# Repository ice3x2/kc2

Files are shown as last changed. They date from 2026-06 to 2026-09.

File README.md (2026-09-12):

# kc2

- **[최신 PCB · 주문한 거버 · 인쇄 모델 — hardware](hardware/README.md)**
- [PCB 프로젝트](hardware/PCB/) · [주문한 거버 ZIP](hardware/GERBER/) · [하우징·링 모델](hardware/MODELS/)
- [MX · Choc V1 · Deep Sea 내부 충전형 인쇄 안내](hardware/MODELS/PRINT-filled-plates.md) · [검증 기록](docs/reports/solid-filled-plates-20260913/README.md)
- [자석 홈 옵션 / 무자석 옵션 선택 안내](hardware/MODELS/PRINT_magnetic.md)
- [주문 당시 안내 원본](order.md) — 봉인 해시 보존용입니다. 현재 위치는 위 `hardware` 안내를 보세요.
- [요구사항 원본(SRS)](docs/spec/00.index.md)

새로 clone한 뒤 기존 생성·검증 도구를 사용할 때는 한 번 실행하세요(Python 3.12 이상).

```powershell
python -B -m tools.kc2_current_layout --apply
```

현재 파일은 `hardware/PCB`, `hardware/GERBER`, `hardware/MODELS`에 실제로 저장됩니다. 기존 `hardware/case`와 일부 `hardware/kicad` 경로는 동일 원본을 가리키는 로컬 호환 연결이며 복사본이 아닙니다.

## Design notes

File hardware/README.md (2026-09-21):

# PCB · 주문한 거버 · 하우징 인쇄 파일

요구사항: `CON-ARCH-006`, `CON-ARCH-007`, `OPS-ARCH-006/007`.

하우징을 인쇄하기 전에 [현재 인쇄·조립 안내](MODELS/PRINT-upper-finish.md)의 검증 명령을 실행하세요. 상판의 비기능 내부 틈을 메우고 국부 하향 돌출을 제거하여 아홉 상판 STL의 최저면을 `Z=4.40`으로 공면화한 개정입니다. 검증이 실패하거나 manifest가 없으면 게시가 미완료된 것이므로 인쇄를 보류합니다. 실제 끼움·강도·키캡 간섭·나사 토크는 출력·조립 후 확인해야 합니다.

- `PCB/`: 기존 주문 설계. [왼쪽 PCB](PCB/kc2_left/kc2_left.kicad_pcb), [오른쪽 PCB](PCB/kc2_right/kc2_right.kicad_pcb). 각 KiCad 프로젝트 폴더 전체와 저장소 `third_party` 라이브러리를 유지하세요.
- `GERBER/`: 변경하지 않은 주문 r4 PCB-only 패키지. [왼쪽 제조 ZIP](GERBER/kc2_left-pcb-fabrication-only.zip), [오른쪽 제조 ZIP](GERBER/kc2_right-pcb-fabrication-only.zip), [주문 manifest](GERBER/manifest.json). 이번 기구 개정으로 재주문할 필요는 없습니다.
- `MODELS/`: MX / Choc V1 / Deep Sea Mini 상판과 무자석 / magnetic 하판. 각 종류의 왼쪽 한 개와 오른쪽 A/B 두 STL을 사용합니다. 오른쪽 STEP/F3D는 두 부품을 포함하는 편집·확인용입니다.
- `MODELS/adapters/`: 이번에 변경하지 않은 [기존 링 어댑터](MODELS/adapters/README.md).

PCB는 이전처럼 하판 받침 위에 놓습니다. 외벽은 PCB 윗면보다 1.50 mm 높고 상판 아래쪽을 1.20 mm 감쌉니다. 중앙 좌우 맞댐은 비접촉이며 잠금 요철은 없습니다. 오른쪽 A/B 결합부는 별도 구조입니다. 이전 상판·하판과 새 파일을 섞지 말고 현재 안내의 정확한 15개 STL 링크 중 필요한 종류를 선택하세요.

실리콘 발 배치·접착 검토는 사용자 요청으로 보류했습니다. 예전 발 배치 그림은 이번 하우징의 검증 증거가 아닙니다. 기존 `PRINT-filled-plates.md` 등 과거 안내는 현재 게시 검증을 대체하지 않습니다. 현재 인쇄 안내가 이전 지침보다 우선합니다.

이 기구 개정은 이미 주문한 PCB/Gerber 16개 파일을 변경하지 않으며 새로운 제작·구매·결제 승인을 의미하지 않습니다.

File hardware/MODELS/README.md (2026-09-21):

# KC2 현재 하우징 파일

요구사항: `CON-ARCH-006`, `CON-ARCH-007`, `OPS-ARCH-006`.

현재 인쇄·편집 파일은 이 디렉터리에 바로 있습니다. 하판 외벽을 PCB 윗면보다 1.50 mm 높게 만들어 상판 아래쪽을 1.20 mm 감싸도록 했습니다. PCB 받침 높이·1.60 mm PCB 두께·주문 거버는 그대로입니다. 상판 외곽도 대응하도록 바뀌었으므로 새 상판과 하판을 함께 사용하십시오. 중앙 요철은 복원하지 않았고 기존 소켓 가림벽과 두 자석 쌍은 유지합니다.

현재 상판은 내부 비기능 틈을 메우고 나사 랜드의 0.30 mm 하향 돌출을 제거해 최저면을 `Z=4.40`으로 공면화한 개정입니다. [현재 인쇄 안내](PRINT-upper-finish.md)를 따르십시오. 아래 검증이 통과해야 게시가 완료된 것입니다. manifest가 없거나 실패하면 인쇄를 보류하십시오.

```powershell
python -B -m tools.publish_kc2_upper_finish
```

## 하판 선택

두 종류 중 한 종류만 선택합니다.

| 종류 | 왼쪽 | 오른쪽 A | 오른쪽 B |
|---|---|---|---|
| 일반형 | [STL](kc2_left_lower_housing.stl) | [STL](kc2_right_lower_housing_part_a.stl) | [STL](kc2_right_lower_housing_part_b.stl) |
| 자석형 | [STL](kc2_left_lower_housing_magnetic.stl) | [STL](kc2_right_lower_housing_part_a_magnetic.stl) | [STL](kc2_right_lower_housing_part_b_magnetic.stl) |

자석형은 기존 중앙 하단의 자석 두 쌍(`Y=103, 111 mm`)만 유지합니다. 컨트롤러 쪽 세 번째 쌍은 벽을 넓히지 않고 안전한 잔여 재료와 유효 흡착 거리를 동시에 확보할 수 없어 추가하지 않았습니다. 임의로 구멍을 뚫지 마십시오.

## 상판 선택

MX, Choc V1, Deep Sea Mini 중 실제 스위치와 맞는 한 종류만 선택합니다. 왼쪽은 STL 한 개, 오른쪽은 `part_a`와 `part_b` 두 개입니다. 세 종류 모두 새 외벽과 맞는 외곽 립을 반영했습니다.

- MX: `kc2_left_mx_upper_housing.stl`, `kc2_right_mx_upper_housing_part_a.stl`, `kc2_right_mx_upper_housing_part_b.stl`
- Choc V1: `kc2_left_choc_v1_upper_housing.stl`, `kc2_right_choc_v1_upper_housing_part_a.stl`, `kc2_right_choc_v1_upper_housing_part_b.stl`
- Deep Sea Mini: `kc2_left_deep_sea_upper_housing.stl`, `kc2_right_deep_sea_upper_housing_part_a.stl`, `kc2_right_deep_sea_upper_housing_part_b.stl`

STL은 인쇄용, STEP과 F3D는 편집·검토용입니다. 오른쪽 전체 STEP/F3D에는 두 몸체가 들어 있으므로 150 mm 프린터에서는 반드시 A/B STL을 사용하십시오. 현재 manifest는 `kc2_upper_finish_manifest.json`입니다. 이전 wall-gap/registered/flat-central/smooth-central/wrap manifest와 `STL_FROM_FUSION_20260921`은 비교 이력입니다. 나사식 조립과 실제 상·하판 여유는 유지합니다.

디지털 검증은 실제 출력물의 수축·팽창, 자석 접착력, 장기 강도와 조립 감각을 확정하지 않습니다. 먼저 시험 출력 후 좌우 간격과 자석 극성을 확인하십시오.

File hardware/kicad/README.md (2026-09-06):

# KC2 X3 V2 canonical hardware

> Current PCB-only release: **solid-floor-20260907-r4**, with independently checked continuous lower floors and current native CAD.
> Physical qualification remains pending; no order or payment was performed. Prior r3/r2 packages are historical.
> Exact directory, PCB ZIP, STL, silicone-foot and assembly guide: [root order.md](../../order.md).
> Use [current release instructions and residual-risk conditions](first_order/README.md).

Requirements: `CON-ARCH-004`, `CON-ARCH-006`, `CON-ARCH-007`,
`REL-ARCH-001`, `OPS-ARCH-006`, `OPS-ARCH-007`

Status: **R4 DIGITAL DESIGN/OUTPUTS VERIFIED; PHYSICAL QUALIFICATION PENDING**.
Follow the [first-order files and Korean instructions](first_order/README.md).
The promoted PCB retains the V1 locator clearances and r3 routing. Unchanged r3 Gerber
and fullboard/zoom evidence is combined with newly verified r4 closed-floor CAD/native evidence. OPS-ARCH-007 separates
pre-order design review from post-receipt acceptance; no prerequisite sample is
required. This is PCB-only preparation, not complete assembly compatibility.
Socket contact tolerances and the high-risk keycap/top-screw-head interface are
explicitly unproven; read the guide before spending money. Historical
`fabrication/` ZIPs remain **DO NOT ORDER**. Later physical-gate wording in this
document is interpreted under OPS-ARCH-007, not as a prerequisite sample demand.

The active V2 source projects are the canonical
`hardware/kicad/kc2_left/` and `hardware/kicad/kc2_right/` projects. The
replaced X3 revision is retained through Git history; there is no duplicate
active V2 tree under `hardware/kicad/draft/`.

## Assembly modes

The selected assembly is `mx_receptacle_with_plate`. Four switch modes are
mutually exclusive at all 70 positions (31 left / 39 right):

- Selected MX: solder two individual open-bottom hat-style receptacles per key
  (62 left / 78 right, 140 total). The selected TTC Bluish White 3-pin switch
  requires the 3D-printed MX plate-lid for retention. Existing 5-pin MX locator
  support remains; the selected 3-pin switch leaves those holes unoccupied.
- MX direct-solder fallback: leave receptacles unpopulated and solder the two
  electrical switch pins directly. Qualify this fallback separately.
- Choc V2 / PG1353-class alternative: install the bottom-side Kailh
  `CPG135001S30` socket; do not directly solder the Choc switch. This is not the
  selected assembly and must not be populated together with MX receptacles.
- Choc V1 / PG1350 alternative: use the bottom Choc socket and V1 center ring
  adapter, with the new copper-free PCB locator clearances. No cutting the switch
  or hand-drilling the PCB is required by this design. Full assembly qualification
  remains pending; the ring alone did not make the historical r2 PCB V1-compatible.
- Choc V2 direct-solder and one-piece MX SMD sockets remain unsupported.
  Never populate multiple switch assemblies at one position.

The socket contract is dimensional, not a required brand/MPN: total length
`3.00 mm`, barrel OD `1.45 mm`, flange OD `2.00 mm`, flange thickness `0.20 mm`,
and an open bottom. A flush flange on a nominal `1.60 mm` PCB projects `1.20 mm`
below it before solder and switch-pin protrusion. Closed-bottom `4.00 mm` and
hatless `3.50 mm` parts are not equivalent substitutes. See the
[selected seller drawing](https://ae-pic-a1.aliexpress-media.com/kf/S4b47dab427cd4b539a50618bf16a62d9J.jpg).
OD tolerances and flat-blade contact limits are unpublished and remain pending;
a Mill-Max compatibility claim is not qualification evidence.

MX electrical lands are `2.50 x 3.20 mm` ovals in footprint-local Y with a
**trial `1.60 mm` PTH**, not a qualified production finished-hole fit. Both
mask layers expose the full land at explicit nominal zero expansion, without
paste apertures. Center/locator NPTHs remain copper-free. The exact purchased
MX switch drawing, flange relief, blade engagement and replacement/contact
tests remain required. The selected low-profile Choc V2 alternative is the user's
Kailh Deep Sea brown seller option; its exact manufacturer MPN/drawing linkage is
still pending. A marketing family name alone does not qualify the dimensional fit.
See the [exact selected-component source review](../../docs/reports/kc2-selected-component-source-closure-2026-09-06.md).

The owned hybrid footprint includes an explicit bottom courtyard from
`(-10.25,1.20)` to `(5.25,8.50)` mm. It encloses the complete bottom socket
body and both B.Cu lands with a `0.25 mm` manufacturing allowance.

The left and right boards use their physical split-keyboard orientations. The
bottom-side socket pattern must be read from the PCB bottom. The historical 1:1
bottom PDF is already mirrored for a physical bottom view, but is an orientation
reference only, not evidence of the current MX geometry.

## Matrix diode and polarity

The PCBs require exactly 70 Diodes Incorporated `1N4148W-13-F`
matrix diodes in flat SOD-123 packages, controlled by `DS30086 Rev. 31-2`.
All are assembled on `B.Cu`. Pin/pad 1 is the cathode connected to the row net; pin/pad
2 is the anode connected to the per-key switch net. A physical bottom view is
mirrored relative to KiCad's top/front view, so place the cathode band toward
the marked pad 1 rather than relying on an assumed left/right direction.

The firmware contract remains `col2row`, active-high columns, and active-high
row inputs with pull-downs. The existing pinned build remains zero-wait: no
extra delay before reading inputs and no delay between driven columns. Do not
change those scan delays until a populated physical coupon has passed both
3.0 V and 3.3 V maximum same-row and maximum same-column stress tests. Those
tests remain pending, so these digitally verified boards are not orderable.
The retained diode-plus-Choc BOM/CPL is an unselected, mutually exclusive
hand-assembly reference, not an MX receptacle BOM or an authorized placement
order. Selected MX procurement documentation must bind the dimensional socket
contract, supplier trace and plate dependency; qualification remains open.

## Joined spacing

The joined reference places the right half `0.80 mm` farther outward than the
ordinary `19.05 mm` one-unit transform. Corresponding Choc V2 and MX assembly
modes are evaluated with the same selected cap envelope for each physical key.
All five actual seam pairs have a nominal `1.80 mm` cap-to-cap gap and a
`3.80 mm` row-center PCB gap:

| Row | Pair | Cap widths (left/right) | Center pitch | Center-to-PCB-edge (left/right) |
|---:|---|---:|---:|---:|
| 0 | `6`-`7` | `18.05 / 18.05 mm` | `19.85 mm` | `8.025 / 8.025 mm` |
| 1 | `T`-`Y` | `18.05 / 18.05 mm` | `19.85 mm` | `8.025 / 8.025 mm` |
| 2 | `G`-`H` | `18.05 / 18.05 mm` | `19.85 mm` | `8.025 / 8.025 mm` |
| 3 | `B`-`N` | `18.05 / 18.05 mm` | `19.85 mm` | `8.025 / 8.025 mm` |
| 4 | `Space`-`B` | `32.3375 / 18.05 mm` | `26.99375 mm` nominal (`26.9937 mm` in the routed coordinate serialization) | `15.16875 / 8.025 mm` nominal |

The two complete closed Edge.Cuts outlines are compared segment by segment,
including horizontal stair transitions. Their exact minimum is `1.10 mm`,
created by a direction-aware `0.55 mm` transition stagger. PCBWay's published
`+/-0.20 mm` CNC outline tolerance gives a conservative two-edge lower bound
of `0.70 mm` at that limiting transition. This is digital nominal geometry;
actual half-to-half housing registration and assembled cap/switch play still
require a printed first article.

Do not trim removable switch blades in the selected receptacle assembly.
Any trimming applies only to separately qualified direct-solder fallback joints.
The 2.50 mm lower plate has exterior-bottom-open cutouts through the full plate
height for every MX terminal and solder joint, rather than a closed component
cavity. The lateral solder-fillet model includes a 0.30 mm allowance.

The Choc socket and 1N4148W SOD-123 solder-fillet models each include a 0.30 mm
lateral allowance. Current digital diode checks enforce at least `1.00 mm`
to switch copper/unused NPTH/unrelated exposed copper, `1.30 mm` to Edge.Cuts,
and the separate `0.10 mm` conservative fillet-to-route gate. Do not reuse
pre-revision route minima as revised evidence. Every diode
pad has an unobstructed cardinal solder-tool approach. The enlarged KC2 hand-
solder land is deliberately not the manufacturer's recommended land: implemented
pads are 1.40 x 1.55 mm at 3.60 mm centers, while the official suggested pads
are 0.90 x 0.95 mm at 4.05 mm centers. The revised lower housing models
`0.35 mm` component cutout XY clearance and `0.30 mm` support-to-routed-copper
wear reserve. See `../case/kc2_housing_clearance.json` for the bound current
geometry. Socket/flange/solder/full-blade protrusion, physical retention,
deflection and populated-coupon fit remain qualification gates.

## M1.4 retention prototype

The PCB contains eight left and nine right `MH*` features using the owned
`MH_M1.4_NPTH_1.60` footprint. Each is an unnetted, copper-free `1.60 mm`
round NPTH. Each hole is visibly numbered `MH1..MH8` on the left and
`MH1..MH9` on the right using `0.80 mm` / `0.15 mm` front-silkscreen text.
Service is modeled with keycaps removed and either supported switch
type still installed. A final `3.00 mm` vertical PH0 driver envelope and a
provisional non-countersunk rounded pan/button head envelope of maximum
`3.00 x 1.20 mm` clear the modeled Choc V2 and MX assemblies with a separate
`0.25 mm` XY reserve. The driver envelope already includes its search reserve
and must not be buffered a second time.

The matching lower housing provides a `3.00 mm` zero-gap support land and desk
column at every hole, with a provisional `1.10 x 2.80 mm` blind pilot and a
`0.70 mm` closed bottom at the common Z=-1.00 mm desk datum. A separate exact
one-to-one network of 31-left/39-right `2.40 mm` key-load feet provides every
switch center with a local desk load path whose worst center-to-support-edge
distance is `3.8990 mm`, within the `4.40 mm` bound; mounting columns are not
credited as typing-load supports. The enlarged-pad routing maintains the
required `0.30 mm` support-to-B.Cu/via copper clearance.

The selected stack is lower housing, PCB, then the plate-integrated MX lid,
clamped by long top-entry screws through the same 17 PCB holes. The former
`4.00 mm` lower-only screw length is not a selected-stack recommendation.
The revised upper design retains provisional `14.0 mm` apertures, `1.5 mm` clip
thickness and `5.2 mm` plate-top height above PCB top. It recesses the screw head
in a `3.4 mm` diameter / `1.5 mm` deep pocket, backed by a `4.6 mm` upper collar
while retaining the `3.0 mm` PCB landing. The nominal maximum `1.2 mm` head sits
`0.3 mm` below the plate top. This removes modeled head protrusion, not unknown
keycap underside or printed-strength qualification. The new nominal under-head-
to-receiver entry distance is `5.3 mm`, replacing the historical `6.8 mm`;
the qualified screw length is still unset. Revised CAD/native export is under
regeneration and must pass before release. Exact
screw/driver, receiver engagement, print material/tolerance, registration,
installation/stripping torque, ten service cycles, full keycap travel, split-joint
retention and 2.0 N deflection require physical evidence. Digital clearance and
the existing `1.10 x 2.80 mm` pilot do not qualify the new long-screw receiver.

## Battery service path

Each half uses one nominal `30.00 x 12.00 x 3.00 mm`, 3.7 V, 100 mAh
301230-class pack above the carrier PCB and below the socketed nice!nano. The
battery centers are left `(131.7125, 50.7500)` and right
`(78.4000, 50.7500)` mm, with the 30 mm axis parallel to the U1 socket rows.
The exact manufacturer/MPN, single-cell protection status, maximum swollen
thickness, lead-exit drawing, and pull limit remain procurement gates.

Only the pack's pre-attached insulated leads are soldered to `J_BAT1`; do not
solder a bare pouch tab and do not add an A2501, JST, or other detachable
battery connector. `J_BAT1` is left `(115.8125, 59.4000)` R180 and right
`(94.3000, 59.4000)` R0. Its visible assembly marks identify pad 1 `B+` and
pad 2 `B-/GND`; the electrical pad nets remain `BAT+` and `GND`, respectively.
The [official nice!nano documentation](https://nicekeyboards.com/docs/nice-nano/)
identifies the carrier's `RAW` and `GND` pins as the battery-positive and
battery-negative connections, so no extra net tie is required.
`BAT_LEAD_SLOT1` remains an unnetted, copper-free
strain-relief feature identified by the exact board text
`BAT STRAIN RELIEF`, at left `(117.9125, 50.7500)` and right
`(92.2000, 50.7500)` mm; it is not a lower battery exit.

The electrical path is
`J_BAT1 BAT+ -> SW_PWR1 pad 1 common -> pad 2 ON -> NN_B+ -> U1 RAW`. Pad 3 is
NC. J_BAT1 B-/GND remains directly connected to
local GND and U1 GND. Keep BAT+ and its GND return paired in the USB-side
corridor and outside the antenna keepout. The lower housing has no TW301525 or
301230 battery-body cavity; it provides only the required U1, J_BAT1,
strain-relief, IMMS lead, and solder-fillet openings.

## Compact controller tab

The V2-only compact-controller layout keeps all 70 key centers and all 17
numbered mounting-hole centers fixed. U1 centers are left
`(132.7125, 50.7500)` and right `(77.4000, 50.7500)` mm. The top Edge.Cuts
centerline is `Y=39.2500 mm`, and the nominal board height is `122.50 mm`.

POWER and RESET occupy the controller-key gap. `SW_PWR1` is left
`(115.8125, 63.4500)` R0 and right `(94.3000, 63.4500)` R180. `SW_RST1` is
left `(126.0625, 63.4500)` R0 and right `(84.0500, 63.4500)` R180, with pad
1=RST on the POWER/USB-facing side and pad 2=GND on the keyboard-center side.
Top-view absolute order is left `PWR|RST` and right `RST|PWR`; from each
USB-facing outer edge toward the antenna, the service order is POWER then
RESET. The centers are 10.25 mm apart, giving 2.20 mm nominal controlled-body
clearance, 3.20 mm reset-body clearance to the nearest keycap envelope, and
`1.73 mm` nominal reset-courtyard clearance to the enlarged U1 socket copper.

All 24 U1 lands per half are `1.80 x 2.40 mm` ovals, elongated perpendicular to
the `2.54 mm` pin-row direction, with unchanged `0.95 mm` drills and `15.24 mm`
row spacing. Both mask layers expose the whole land at nominal zero expansion;
there are no paste apertures. The nominal battery-to-socket-copper gap is now
`0.42 mm`, not the former circular-pad `0.72 mm`. Actual solder wetting, bridge
avoidance and battery/controller-stack fit remain unverified physically.

Each placed `SW_PWR1` retains the owned STEP model. That STEP is a nominal
collision proxy only: the exact purchased manufacturer/MPN and controlled
drawing are pending, and `IMMS-12V` / `BSI-10` equivalence is not assumed.

This V2 contract supersedes the historical X3 no-carrier-power,
USB-under-reset, and antenna-side-reset instructions only for `kc2-x3-v2`.
The exact pack stack, USB shell/cable, POWER/RESET access, controller removal,
lead strain relief, keycap clearance, and actuation support still require
physical first-article evidence. The digital package remains not orderable.

## Outputs

- Current routed source boards: `kc2_left/` and `kc2_right/`; current DRC bindings
  are in `kc2_drc_evidence.json`.
- Current route replay: `autoroute/kc2_mx_solder_support_routes.json`.
- Raw revised Gerber/drill review files: `fabrication_review/mx-receptacle-20260906/left/`
  and `right/`, 15 files per half; not an order-approved fabrication package.
- Historical coupon, BOM/quotes, fabrication, 1:1 PDFs and renders: `coupon/`,
  `fabrication/`, `mechanical/`, `renders/`. Their pre-revision evidence must
  not be treated as regenerated MX-receptacle evidence.
- Current lower/MX upper CAD and evidence: `../case/`, including four STEP files,
  six STL part meshes (one left/two right per housing type), and four
  real native F3D archives.

**DO NOT ORDER** `fabrication/kc2_left_jlcpcb.zip`,
`fabrication/kc2_right_jlcpcb.zip` or `fabrication/kc2_coupon_jlcpcb.zip` for
this revision. These retained direct-solder/lower-only packages do not contain
reviewed current enlarged lands, routing and selected assembly evidence.
The old `*-bom.csv/json` direct-solder references and `pcba_quote/` Choc socket
BOM/CPL are likewise excluded from selected 140-contact MX procurement. They
are not authorized placement files, even when their historical package checks pass.

The raw revised files passed bounded actual-board geometry/drill checks,
including the 17 mounting holes and battery legends. See
[the Gerber inspection report](../../docs/reports/kc2-mx-gerber-inspection-2026-09-06.md).
Complete polygon-visual and physical qualification remain pending. Exporting
raw review files is not a fabrication release; no revised order-ready ZIP is
claimed here. Before release, inspect the exact revised copper, full front/back mask openings,
PTH/NPTH drills, plated-hole tolerances, polarity, mechanical fit and source/hash
bindings component by component. The intended board profile remains two-layer
FR-4, nominal 1.6 mm, 1 oz, ENIG, green mask, white silkscreen, hand assembly and
tented vias. The historical manufacturing manifest does not prove that profile
or via tenting in a new export. Any future JLCPCB engineer-generated production
files must also be downloaded and reviewed before approval.

The retained coupon has historical rotated/mirrored Choc and direct-solder MX
samples. It is not the required selected-assembly minimum three-key receptacle
coupon with production-material plate-lid. Finished-hole and blade seating,
socket retention/contact resistance after replacements, exact diode polarity,
solder-tool access and 3.0/3.3 V zero-wait scan tests remain physical gates.

The four F3D files were exported and reopened in real Fusion and independently
compared with the six STEP solids. See
[the native export report](../../docs/reports/kc2-fusion-native-export-2026-09-06.md)
and `../case/kc2_fusion_export_result.json`. They are native archives of imported
solids, not a reconstructed parametric feature history. Native delivery is
complete; printed clip fit, long-screw/receiver qualification and physical
assembly are not. The upper manifest still states `print_ready=false` and
`order_ready=false`.

## Reproduction and verification

Run PCB tools with KiCad 10 Python:

Run these commands from the repository root. The housing verifier additionally
requires the documented CadQuery environment. The exact executable release
gates for the active V2 target are `tools.verify_kc2_x3_v2` and the dedicated
V2 fabrication, mechanical, outline, coupon, firmware, and housing verifiers
below. Apply the `kc2-pcb-preflight` component-by-component and
circuit-by-circuit review workflow as an additional audit. Its bundled CLI
supports the historical `--variant x3` path only; an `ORDER READY` result from
that historical X3 run is not evidence for `kc2-x3-v2`.

`tools.verify_kc2_x3_v2` exits `0` only when every digital and physical gate
passes, `1` on a digital error, and `2` when PCB checks pass but required
assembly/physical evidence is still pending. After native delivery, the current
expected result is exit `2` with nine qualification/physical blockers, not approval.

```powershell
$kpy = 'C:\Program Files\KiCad\10.0\bin\python.exe'
& $kpy -m tools.generate_kc2_pcbs --variant x3-v2 --output-dir tmp_x3_v2_clean
& $kpy -m tools.render_kc2_x3_joined --variant x3-v2 --placement-mode key-pitch --scale 5 --output-dir hardware/kicad/renders
& $kpy -m tools.verify_kc2_x3_v2
& $kpy -m tools.verify_kc2_x3_v2_coupon
& $kpy -m tools.verify_kc2_x3_v2_outline
& $kpy -m tools.verify_kc2_x3_v2_fabrication
& $kpy -m tools.verify_kc2_x3_v2_mechanical
& $kpy -m tools.verify_kc2_x3_v2_zmk_firmware
python -m tools.verify_kc2_x3_v2_housing
```

The render command writes both SVG and PNG evidence. If Pillow is unavailable
in KiCad Python, it automatically uses an installed Chromium-family browser;
on Windows it detects Microsoft Edge in its standard install locations. Set
`KC2_HEADLESS_BROWSER` to an explicit browser executable when auto-detection is
not appropriate. The focused test launches this exact CLI with the active
KiCad Python and verifies that both fresh PNG files have valid dimensions.

The isolated generator output is intentionally unrouted. The committed board
files include the reviewed route completion and must retain KiCad DRC results
of zero violations and zero unconnected items. After producing both fresh DRC
JSON reports, regenerate the exact board/report evidence binding before running
the release verifier:

```powershell
& "C:\Program Files\KiCad\10.0\bin\python.exe" -B -m tools.generate_kc2_drc_evidence
& "C:\Program Files\KiCad\10.0\bin\python.exe" -B -m tools.verify_kc2_x3_v2
```

`kc2_drc_evidence.json` binds each current board and `.kicad_pro`
SHA-256 to its DRC report SHA-256, schema, source filename, KiCad version,
report date, included severity classes, and the project's `Default` netclass
clearance. The release verifier requires that clearance to remain at least
`0.30 mm`, a KiCad 10.x report, a valid ISO timestamp, and both `error` and
`warning` coverage; `exclusion` is the only optional additional severity. A
changed board, project, or report cannot pass against stale evidence.

When only the generated outline policy changes, use
`tools.repair_kc2_x3_v2_compact_edge --sync-edge-cuts-from <fresh-board>`.
The command rejects non-rigid switch geometry, replaces only Edge.Cuts, and is
covered by route/footprint-preservation and idempotence tests.

The retained `autoroute/kc2_left.dsn`, `kc2_right.dsn` and matching SES files
are historical pre-MX-revision inputs. They retain eight/nine M1.4 NPTHs and
0.30 mm routing rules but reconstruct the old 616-left/803-right routing, not
the selected enlarged-land boards. Their role in the generation manifest is
historical base provenance. Do not run the old SES finalizer against the current
canonical boards. Historical finalizer tests use immutable Git fixtures and
verify exact routes, service-pad/matrix connectivity, mounting geometry and
second-run idempotence without claiming current reconstruction.

Current V1-inclusive routing contains 876 left / 1089 right track/via items, with
digests `ccc6190a8f46e251261c6ef981fda11bd6524fc547ca358be1cde63a10ad2da3`
and `aa78af58190800870654a15ce6f772aea41a806705bb645597ed93b9ef0ac533`.
The schema-2 replay at `autoroute/kc2_mx_solder_support_routes.json` binds exact
pad centers, nets, shape/drill dimensions and local/effective mask margins.
`tools.kc2_solder_route_snapshot.restore` refuses a mismatched board before
changing routes. The fresh-generator regression generates only into a unique
temporary directory, applies this replay and verifies both reconstructed boards
with fresh DRC:

```powershell
& $kpy -B -m unittest tools.test_kc2_generator_route_replay
```

This test passed for both halves. Do not bypass the pad fingerprint or label the
historical DSN/SES import as the current route source.

The project explicitly ignores five KiCad diagnostic classes: missing
courtyard, track-not-centered-on-via, tuning-profile track geometry,
symbol/footprint-filter mismatch, and footprint component-type mismatch.
These are generated-board metadata, custom hybrid-footprint library, or
non-applicable tuning diagnostics. The
electrical implications remain covered by exact footprint geometry checks,
matrix-island connectivity checks, NPTH copper-free checks, Gerber/Excellon
inspection, and zero DRC violations/unconnected items.

The production release gate compares every placed 1N4148W pad, B.Fab body,
courtyard, and mirrored B.Silkscreen cathode mark against the KC2-owned
footprint. It also compares every hybrid-switch pad/NPTH and the side-specific
24-pad nice!nano socket against its owned footprint, requires the matching
front-silkscreen `USB_OUT_LEFT`/`USB_OUT_RIGHT` label, and hard-checks
`SW_RST1` pad 1=`RST`, pad 2=`GND`.

Official geometry references:

- Kailh Choc V2 switch: https://www.kailhswitch.com/mechanical-keyboard-switches/key-switches/kailh-low-profile-switch-choc-v2.html
- Kailh socket drawing: https://www.kailhswitch.com/uploads/15927/files/CPG135001S30.pdf?rnd=925
- Cherry MX2A 5-pin datasheet: https://www.cherry.de/fileadmin/media/Industrial/Switch/MX_BLACK/Data_sheet_MX2A_Black.pdf
- Diodes Incorporated 1N4148W product page: https://www.diodes.com/part/view/1N4148W/
- Diodes Incorporated DS30086 Rev. 31-2 datasheet: https://www.diodes.com/datasheet/download/1N4148W.pdf
- nice!nano v2 pinout and schematic: https://nicekeyboards.com/docs/nice-nano/pinout-schematic/

## Component and terminal audit

This table updates the historical procurement audit for the selected 2026-09-06
assembly. Nominal geometry/pinout checks do not qualify unspecified tolerances,
purchased parts, enlarged hand-solder lands or physical assembly. No `PASS`
entry below is procurement or fabrication approval.

| Placed item | Published body / terminal contract | Actual KC2 footprint | Result |
|---|---|---|---|
| nice!nano v2 `U1` | Published plan `34.1 x 18.3 mm`; official total thickness `3.2 mm` and official Pro Micro pinout. B+ and B- are not socketed; `RAW` and `GND` are their respective carrier equivalents. | Conservative collision envelope `34.1 x 18.3 mm`; 2 x 12 PTH, `2.54 mm` longitudinal pitch, `15.24 mm` row spacing; enlarged `1.80 x 2.40 mm` oval lands, `0.95 mm` drill, full F/B mask openings; `RAW=NN_B+`, `GND_C=GND`, `RST=RST`. | Nominal plan/pinout checked; exact female socket, pin tails, wetting and stack fit PENDING. |
| Kailh Choc V2 socket | Kailh `CPG135001S30`, drawing `KH-PS-1702-35` Rev D; T=1.6 recommended pattern with `2.60 mm` contacts and specified NPTH locations. | Bottom socket body `9.55 x 6.80 mm`, B.Cu pads `2.60 mm`, exact official mechanical holes; duplicate pads 1 and 2 share the MX electrical nets. | Socket PASS; exact mating Kailh switch MPN/drawing PENDING. |
| Selected MX receptacles / direct-solder fallback | Two open-bottom hat contacts per key: length `3.00 mm`, barrel OD `1.45 mm`, flange `2.00 x 0.20 mm`; exact purchased MX drawing/contact tolerances pending. | F.Fab `15 x 15 mm`; electrical lands `2.50 x 3.20 mm` oval, trial `1.60 mm` PTH, full F/B mask openings, existing copper-free `5.00/3.00/1.65 mm` hybrid fixation features. Printed MX plate-lid required for receptacles. | 140 contacts modeled; finished-hole/barrel fit, blade engagement, flange relief, replacement/retention tests PENDING. |
| `1N4148W-13-F` diode | Diodes Incorporated SOD-123, body max `2.85 x 1.70 x 1.35 mm`, terminal span max `3.85 mm`; suggested pads `0.90 x 0.95 mm` at `4.05 mm` centers; pin 1 cathode, pin 2 anode. | B.Fab `2.85 x 1.70 mm`; controlled hand-solder pads `1.40 x 1.55 mm` at `3.60 mm` centers, classified as a KC2 enlargement rather than the manufacturer land; pad 1 row/cathode, pad 2 per-key/anode. | Digital geometry/polarity PASS; populated solder/scan coupon PENDING. |
| `SW_PWR1` | SM Switch `BSI-10`: `10 x 2.5 x 6.4 mm`, `1.6 mm` travel, three `0.6 mm` pins on `2.54 mm` pitch, recommended `0.8 mm` drills; terminal 1 common. | F.Fab `10 x 2.5 mm`, three `1.60 mm` pads / `0.80 mm` drills at `2.54 mm`; pad 1 `BAT+`, pad 2 `NN_B+`, pad 3 NC. | Geometry/net PASS; exact purchased MPN/drawing and former IMMS equivalence PENDING. |
| `SW_RST1` | DeviceMart `NW3-A06-B3`, nominal body `6.1 x 3.7 mm`. | Controlled body `6.1 x 3.7 mm` inside an `8.0 x 3.7 mm` lead-span drawing; SMD pads `1.75 x 1.00 mm`; pad 1 RST, pad 2 GND. | Nominal PASS; purchased-lot drawing/actuation test PENDING. |
| `BAT1` / `J_BAT1` | Nice Keyboards recommends a rechargeable 3.7 V 301230 cell; exact protected-pack maximum, swelling and lead drawing are supplier-specific. | Nominal body `30 x 12 x 3 mm`; direct-lead pads `2.20 x 1.80 mm`, drill `0.90 mm`, pitch `2.54 mm`; pad 1 BAT+, pad 2 GND/B-. | Nominal only; exact protected pack, lead diameter and maximum envelope BLOCK ORDER. |
| `MH*` / long-screw stack | Provisional M1.4 non-countersunk rounded head up to `3.00 x 1.20 mm`; final long-screw length unset. | Copper-free unnetted `1.60 mm` NPTH with provisional lower pilot `1.10 x 2.80 mm`; upper lid, PCB and lower receiver share 17 centers. | Nominal geometry only; exact screw/driver, engagement, receiver torque and deflection PENDING. |

Dimension and terminal sources additionally used by this audit:

- nice!nano mounting/battery guidance: https://nicekeyboards.com/docs/nice-nano/
- nice!nano installation and B+/B-/RAW/GND guidance: https://nicekeyboards.com/docs/nice-nano/getting-started/
- nice!nano published reseller dimensions: https://mechboards.co.uk/products/nice-nano-v2
- SM Switch BSI-10 drawing: https://pf02.ickimg.com/datasheet/upload/2023/10/07/BSI-10.pdf
- DeviceMart NW3-A06-B3 dimensions: https://www.devicemart.co.kr/goods/view?no=1322056
- Diodes Incorporated 1N4148W: https://www.diodes.com/part/view/1N4148W/

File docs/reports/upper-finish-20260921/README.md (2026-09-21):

# Upper inner-void and coplanar print-face correction

Requirements: CON-ARCH-006, OPS-ARCH-006. The immutable input revision is
identified by `hardware/MODELS/kc2_wall_gap_fix_manifest.json`.

The user reported two physical-print concerns in all upper families: awkward
nonfunctional space inside the outer wall and localized screw lands projecting
0.30 mm below the surrounding upper structure. The source minimum is Z4.10,
while the broad surrounding structure starts at Z4.40.

The correction fills only closed nonfunctional silhouette holes outside the
protected switch, socket, screw, service and registration spaces. It removes
all source material below Z4.40, producing one common minimum print datum on
all nine upper STL parts. No downward foot is added. The screw bores and the
larger boss geometry at and above the datum are compared against the source.

Publication is complete only when `hardware/MODELS/kc2_upper_finish_manifest.json`
exists and `python -B -m tools.publish_kc2_upper_finish` passes. Evidence then
contains six CAD generation records, six actual Fusion archive/reopen/native-STL
records, actual-section review, exact right A/B clearance, upper/lower insertion
sweeps, joined-half approach sweeps, and regression results.

The completed digital review reports zero material at Z4.15, Z4.35 and Z4.399
for all nine upper parts. It removed 12.138 mm3 from each left upper and
6.069/7.586 mm3 from the right A/B parts. Above-datum screw-boss section change
is below 2e-14 mm2, all 12 upper/lower insertion sweeps and six joined approach
sweeps have zero overlap, and all three right A/B gaps are about 0.3999 mm.
The 28-test regression suite passes.

Digital checks do not qualify real printer first-layer adhesion, warping,
material strength, screw torque or populated physical fit.

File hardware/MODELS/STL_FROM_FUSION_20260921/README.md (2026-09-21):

# 보강 전 비교용 STL

이 폴더는 2026-09-21 틈 문제를 조사하기 위해 기존 F3D를 그대로 재출력한
비교 자료입니다. 외벽과 기존 본체 사이의 가느다란 틈을 포함합니다.

틈 수정 완료 후 사용할 파일은 상위 `hardware/MODELS` 디렉터리의 STL이며,
게시 완료 여부와 파일 선택은 [틈 보강 인쇄 안내](../PRINT-wall-gap-fix.md)를
확인하십시오. 이 폴더를 수정 완료판으로 사용하지 마십시오.

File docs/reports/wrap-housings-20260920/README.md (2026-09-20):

# Continuous raised external sleeve — CON-ARCH-006

Release identity: `hardware/MODELS/kc2_wrap_housing_manifest.json`.
Use the current verifier below; an absent or failing manifest is not a release.
Physical qualification remains pending. Requirements remain in `docs/spec/`.

The approved construction keeps the PCB bottom/top at Z2.50/Z4.10 and raises
the lower outer wall to Z5.60. It overlaps the lower portion of the upper
housing by 1.20 mm, rather than enclosing the entire upper height. The new
wall is 1.20 mm thick with 0.30 mm nominal lateral clearance. Existing
registrars retain their separate local 0.25 mm clearance.

The actual PCB outline and nominal cap envelopes are included in the common
mating outline. Central exclusions follow the actual opposite housing,
rather than a broad rectangular strip. Service openings and existing socket
covers remain. The two existing magnet pairs and normal/magnetic options are
preserved; there is no new central locking feature or third magnet pair.

## Candidate corrections and evidence

- The first outline based only on the old MX plate intruded into nominal wide
  cap footprints. It was rejected before publication.
- A later actual STL exposed a local PCB clearance reduction to 0.20 mm.
  Including the PCB outline restored approximately 0.30 mm in the generated
  left and right normal housings and left magnetic housing sections.
- Boolean outline unions produced near-zero-length edges. A topology-preserving
  cleanup limited to 1e-9 mm removes numerical artifacts, with area and Hausdorff
  limits. It is not a manufacturing-scale geometry simplification.
- Binary STL serialization can create an exactly collinear T-junction.
  The serializer only subdivides such an existing edge without moving vertices;
  it refuses arbitrary holes and checks closed topology and volume afterward.

Development staging is private under `.codex-tmp/wrap-housing-20260920-r1`.
The published evidence in this directory resolves those logical names without
requiring that directory. Every generation and review is source-hash bound.

The [actual left MX cross-section](assembly-section-left-mx.png) shows the
generated lower/upper STL contours at local Y=80 mm and the nominal 1.60 mm
PCB section. The [raised-wall plan section](left-sleeve-preview.png) shows
actual lower STL material at Z5.35 with the PCB outline. These selected views
illustrate the intended stack; they do not substitute for full interference
checks or depict every mounted part.

## Required release checks

1. Ten current source-bound CAD jobs: normal/magnetic lower and MX/V1/Deep Sea
   upper on each side; fifteen individually printable STL files.
2. Actual mesh topology, required wall/floor/rim sections, PCB and nominal cap
   clearance, static upper/lower and joined sections, and print envelope.
3. Actual BRep added-material completeness, baseline preservation, A/B and
   complete assembly collisions, and magnet pocket/insertion access.
   Continuous nominal insertion is checked separately in `motion-review.json`:
   vertical height intervals, A/B full projections and central horizontal sweep.
   Its explicit mesh-roundoff allowance is not a physical print tolerance.
4. Ten actual Fusion archive exports, reopen checks, and independent readback
   STEP comparisons. A partial Fusion batch is explicitly not final approval.
5. Current regression tests, portable source bindings, and unchanged hashes
   for all sixteen canonical ordered PCB/Gerber files.
6. Publication of all thirty-five housing CAD artifacts together, current
   print guidance, Git commit/push, and a final publication audit.

`tools.publish_kc2_wrap_housings` refuses missing full mesh/CAD/native/test
evidence. Baseline models are retained through Git revision `e0e8686`, not a
second active model folder. The new [print guide](../../../hardware/MODELS/PRINT-wrap-housings.md)
identifies the release and its physical limitations.

## Comparison requested by the user

Wrapping the complete **perimeter** (except central/service clearances) is
different from wrapping the complete **height** of the upper housing.
The selected design does the former with a 1.20 mm vertical overlap.
For MX, reaching the upper plate top Z9.30 would require a wall 5.20 mm above
the PCB, rather than 1.50 mm. A common wall that high would extend above the
V1/Deep Sea plate tops Z6.50/Z6.25. Separate lower heights or additional cap
skirt/travel accommodation would be needed. Longer engagement also increases
the area vulnerable to print distortion and rubbing; no force test is claimed.
Therefore partial-height engagement is preferred for the common lower design.
This is a design judgment from the measured stack, not a tested full-height
prototype or a claim that a full-height enclosure is impossible.

## Published verification

```powershell
python -B -m tools.publish_kc2_wrap_housings
```

Run at repository root. The release contains 15 STL, 10 STEP and 10 actual
Fusion archives. Canonical STEP removes only outside-token trailing ASCII
spaces/tabs; `raw-step/` retains the original reviewed bytes. The manifest
proves lexical equivalence and maps source identities to those raw artifacts.
Native readback STEP remains unmodified. All 16 ordered PCB/Gerber files
are unchanged. Regression evidence covers 75 tests in 17 modules.
Actual mesh/CAD/motion reports cover all ten jobs, 12 vertical assembly
combinations and six complete left/right assemblies. Measured A/B projection
gap is at least 0.4000246 mm. Nominal collision checks do not account for an
unknown physical printer distortion field.

The development plan's broad PCB-folder preservation inventory also hashed
unconsumed autosaves, editor state/locks, footprint cache and local `.history`
metadata. These are classified explicitly as historical hash-only observations,
not CAD dependencies or portable release inputs. They are not uploaded.
Actual PCB/project files, geometry sources, reports and all unknown inputs
remain mandatory. Classification is allow-listed and regression-tested;
no actual design source may use this exception.

Digital geometry checks do not qualify actual print strength, assembly force,
wear, torque, magnet adhesion/attraction, exact purchased switch/cap variation,
solder protrusion, cable behavior, or RF. Silicone feet remain deferred.

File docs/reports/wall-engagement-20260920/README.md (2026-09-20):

# 연속 외벽 결합 방식 비교

요구사항: CON-ARCH-006. 사용자 설명.png의 핵심은 PCB 옆으로 올라온 하판 외벽 자체가
상판과 연속적으로 겹쳐 위치를 잡는 것이다. 기존 세 구간 등록 돌기로 대체할 수 없다.
PCB 윗면 대비 최소1.00 mm 돌출 요구를 SRS Requirement에 반영했다.

**이 문서는 대안 연구이며 수정 STL 배포나 실물 문제 해결 완료가 아니다.**
실제 양쪽/세 종류 상판 STL을 읽어 비교했다. 기존 PCB/Gerber/모델은 수정하지 않았다.

## 높이와 두 방식

PCB 받침 Z2.50 및 PCB 윗면 Z4.10은 유지한다. 초기 권장 검토값은
하판 벽 끝 Z5.60(PCB보다1.50 mm 높음), 상판 아래 Z4.40 대비 명목 겹침1.20 mm이다.
최소 요구1.00 mm에0.50 mm 설계 여유를 더한 것이며 제조 오차 보증이 아니다.

| 비교 | 상판 아래 홈/단차에 하판 벽 삽입 | 하판 외벽 안으로 상판 측면 삽입 |
| --- | --- | --- |
| 위치맞춤 | 여러 방향의 연속 측면이 겹쳐야 함 | 여러 방향의 연속 측면이 겹쳐야 함 |
| 상판 위 잔여 재료 | 홈 지붕 필요 | 외측 개방 겹침이면 홈 지붕 불필요 |
| 기존 외곽 유지 | 상대적으로 유리하나 내부 스위치 보호공간 검토 필요 | 상판을 보존하면 외측에 새 벽/틈 공간 필요 |
| 저상형 | 깊은 홈으로 얇은 지붕 발생 가능 | 지붕 문제를 피할 수 있음 |
| 중앙 좌우 | 중앙 예외 처리 필요 | 전체를 둘러싸면 서로 간섭; 중앙 예외 필수 |
| 출력 | 홈 천장/잔여벽/출력 방향 확인 필요 | 연속 상승벽 뿌리/변형/모서리와 분할 확인 필요 |

두 방식 모두 손으로 억지 압입하는 구조나 걸쇠가 아니다. Z방향 고정은 나사가 담당하고
기존 PCB 받침/상판 나사 받침이 Z하중을 받는다. 벽 끝을 상판에 눌러 높이를 정하지 않는다.

## 홈 지붕 계산

벽 끝5.60에 공학적 천장 여유0.30을 더하면 홈 천장은 Z5.90이다.

| 상판 | 기존 판 윗면 | 홈 위 남는 두께 |
| --- | --- | --- |
| MX | 9.30 mm | 3.40 mm |
| Choc V1 | 6.50 mm | 0.60 mm |
| Deep Sea | 6.25 mm | 0.35 mm |

이는 수직 치수 계산이다. MX도 실제 홈이 스위치 몸체/나사/서비스 공간을 침범하지 않고
상판에 연결되는지는 별도 검증해야 하며 이 표만으로 구현 가능 판정을 내리지 않는다.
과거 얇은 가림벽이 부러졌던 문제를 고려하면 저상형0.60/0.35 mm 지붕을 아무 근거 없이
튼튼한 것으로 채택할 수 없다. 시험의1.20 mm 지붕 비교값은 보수적 연구 기준이며
재료 강도 시험 결과나 모든 면에 동일하게 적용되는 기존 SRS 최소값은 아니다.

## 실제 외곽을 감쌌을 때

현재 상판 STL의 각 정점 높이 구간 중간 단면에서 외곽을 추출하고 합집합하여
평면 외피를 만들었다. 조립 틈0.30 mm와 벽 두께1.20 mm의 단순 외측 감싸기 후보는
**현재 상판 외곽보다 각 방향으로1.50 mm 더 바깥에 공간을 요구**한다.
이는 기존 하판 전체 외곽 대비 항상1.50 mm 증가한다는 뜻이 아니다.
오른쪽 수치는 A/B 합친 범위이며 개별 출력물150 mm 검증으로 해석하면 안 된다.

중앙까지 그대로 둘렀을 때 반대쪽 후보 벽과의 평면 교차면적은
MX60.9060 mm², V1약76.9068 mm², Deep Sea약76.9069 mm²이다.
따라서 무조건360도 두르는 후보는 탈락이며 중앙 결합면을 제외해야 한다.
이 수치는 임시2D 외피 충돌이며 최종 수정 CAD 간섭 검증이 아니다.
USB/PWR/RST, 케이블 및 오른쪽 A/B도 이 단순 후보에는 아직 반영하지 않았다.

MX와 저상형 상판 외곽이 서로 다르므로 공통 하판을 유지하려면 상판 둘레의
결합부를 공통 위치에 맞추거나 별도 하판이 필요하다. 빈틈이 큰 저상형을
그대로 넣고 흔들리지 않는다고 주장하지 않는다. 기존 무자석/magnetic 옵션도 유지한다.

## 판단 및 구현 전 결정

권장하는 방향은 **중앙/서비스를 제외한 둘레를 감싸되, 상판 측면의 아래 부분만
약1.20 mm 높이로 겹치는 외측 개방 겹침 구조**이다. PCB보다 벽은1.50 mm 높게 한다.
이는 저상형의 얇은 홈 지붕을 피하는 데 유리하다. 단, 최종 CAD/강도/캡 간섭 합격은 아니다.

상판의 **전체 높이**를 덮는 높은 담장은 별개의 대안이다. MX의 판 윗면까지라면
PCB 위5.20 mm가 필요하고 저상형 공통 하판으로 쓰기 어렵다. 미제공 키캡 스커트와
전체 이동을 침범할 수 있으므로 단지 더 높다는 이유로 추천하지 않는다.

외측 감싸기는 기존 '키캡이 PCB/하판 외곽을 가리는' 외관 제한과 충돌할 수 있다.
상판을 보존하는 단순 후보는 바깥으로1.50 mm 공간을 쓰므로, 보이는 테두리 확대를
허용할지 사용자 선택이 필요하다. 허용되지 않으면 기존 외곽 안쪽의 홈 방식으로
종류별 벽/홈과 상판 단면을 다시 설계해야 한다. 강도나 보호 공간을 줄여 억지로 맞추지 않는다.

## 검증

- `tools.test_kc2_wall_engagement_study`: 실패 선행(모듈 부재) 후4개 시험 통과.
- `tools.kc2_wall_engagement_study`: 실제9개 상판 STL로6개 조립 외피 검사.
- 계산 및 파일 SHA-256: [alternatives.json](alternatives.json).
- 새로운 인쇄 형상/STEP/F3D는 생성하지 않았으며 실물 시험도 수행하지 않았다.
- 현재 인쇄 파일은 여전히 이번 최소1.00 mm 연속 외벽 요구를 만족하지 않는다.

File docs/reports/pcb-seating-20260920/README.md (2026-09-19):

# PCB 안착 및 보강판 위치맞춤 재점검

대상: `CON-ARCH-006`, 현재 `hardware/MODELS`의 smooth-central 하판.

**실물 안착 불량은 해결되지 않았다. 이 보고서는 재출력 승인이나 개선 STL 배포가 아니다.**
사용자는 PCB가 외벽 위에 올라가 상판 홈이 물리지 않는다고 보고했다.
현재 CAD가 명목 치수상 통과한다는 사실로 실물 불량 보고를 기각하지 않는다.

## 확인 결과

현재 설계 좌표는 PCB 받침 Z2.50, PCB 두께1.60, PCB 윗면 Z4.10 mm이다.
일반 외벽 끝은 Z4.10, 위치맞춤 벽 끝은 Z5.00, 상판 홈은 Z4.40..5.20이다.
따라서 PCB 두께를 누락한 설계는 아니며 명목 물림은0.60 mm이다.
높이는 하판 외부 바닥 Z-2.20 기준의 캘리퍼 측정값과 구분해야 한다.
하판 외부 바닥부터 PCB 받침까지는4.70 mm, 정상 PCB 윗면까지는6.30 mm이다.

현재 PCB 외곽과 실제 STL의 Z2.50 위 모든 서로 다른 정점 높이 구간의
중간 단면을 대조했다. 네 하판 모두 두 구간(Z3.30,4.55)에서 기판 교차면적0이다.
왼쪽 최소 여유0.2999965 mm, 오른쪽0.2999918 mm이며 자석 유무에 따른 차이는 없다.
이 영역에 별도 유도 테이퍼를 제공하는 중간 높이 형상은 확인되지 않았다.
Z2.49 단면에는 기판 아래 받침 재료가 존재한다.
이는 정렬된 맨기판 외곽 검사이지 실장 소켓/납땜부의 실물 안착 보증이 아니다.

## 오차 민감도 — 제조 공차 보증값 아님

| 가정한 둘레 방향 합산 오차 | 남은 최소 여유 | 판단 |
| --- | --- | --- |
| 0.00 mm | 약0.30 mm | 명목 비접촉 |
| 0.10 mm | 약0.20 mm | 비접촉 |
| 0.20 mm | 약0.10 mm | 비접촉 |
| 0.30 mm | 사실상0 | 접촉 한계; STL 수치 근사 포함 |
| 0.35 mm | 0 | 양쪽 모두 겹침 발생 |

위 오차는 기판 외곽을 균등 확장한 민감도 시나리오다. 특정 프린터의 수축률,
기판 제조 공차, 조립 위치 오차를 실측하거나 확정한 값이 아니다.
XY 오차는 기판이 못 내려가는 원인이 될 수 있지만 그 자체가 실제 원인이라는 증거는 없다.

기판이 정상 받침에서0.20 mm 뜨면 상판도 같이 올라간다는 가정에서 홈 물림은0.40 mm,
0.40 mm 뜨면0.20 mm,0.60 mm 이상 뜨면0이다.
일반 외벽 Z4.10에 기판 아랫면이 걸리면 정상보다1.60 mm 높아져 홈 물림이 사라진다.
그러나 정상 안착을 복구하지 않고 벽만1.60 mm 높이는 것은 이 문제의 해결로 인정할 수 없다.
PCB/스위치/나사 높이, 상판과 서비스 간섭을 별도로 바꾸는 결과도 생길 수 있다.

## 수정에 필요한 실물 구분

1. 출력한 하판 STL 파일명과 기판을 올린 옆면 사진을 확인한다.
2. 기판 모서리가 외벽 **안쪽으로 내려갔는지**, 외벽 **위에 걸쳤는지** 확인한다.
3. 가능하면 하판 외부 바닥에서 PCB 윗면까지 높이를 측정한다(설계6.30 mm).
4. 외곽이 들어가도 뜨면 아래 소켓/핀/납땜부의 접촉 위치를 찾는다. 나사로 강제 압착하지 않는다.
5. 둘레 끼임이면 해당 위치의 입구/안쪽 여유를, 하부 접촉이면 해당 부품 공간을 수정한다.
   정확한 원인이 없는 상태에서 전체 축척, PCB 받침 높이 또는 벽 전체 높이는 변경하지 않는다.

## 재현 및 한계

`C:/Python312/python.exe -B -m unittest tools.test_kc2_pcb_seating` — 4개 시험 통과.
시험을 먼저 추가해 모듈 부재로 실패한 뒤 구현했다. 시험용 연결되지 않은 상자 조합의
잘못된 단면 기대값은 실제 폐곡면 링 fixture로 고쳐 내부 빈 공간 보존을 검증했다.
높은 위치의 삽입 장애물 검출, 정상 받침 제외, 추가 PCB 높이에 따른 물림 상실을 포함한다.

`C:/Python312/python.exe -B -m tools.kc2_pcb_seating` — [sections.json](sections.json).
실제 STL 및 PCB 입력 SHA-256을 기록하고 실행 도중 변경 여부를 확인한다.
정점 높이 구간의 수평 표본 검사이며 일반적인 연속 swept-volume 증명은 아니다.
상판 물림 민감도는 설계 좌표 계산이며 이번 실행에서 상판 STL을 새로 측정한 결과는 아니다.

기존 게시물 검증 `tools.publish_kc2_smooth_central_seam --verify`도 통과했다.
PCB, 거버, STL/STEP/F3D는 변경하지 않았다. 실물 문제는 미해결이며 SRS 상태도
`in_progress`로 유지한다. 본 보고서는 새 제작 발주 승인과 무관하다.

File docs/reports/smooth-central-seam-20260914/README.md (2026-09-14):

# 중앙 요철 자리의 파임 메우기

요구사항: `CON-ARCH-006`, `CON-ARCH-007`, `OPS-ARCH-006`.

이전 개정은 돌출 요철만 잘라내어, 탄성 안내부가 움직이도록 비워 둔 외벽과 바닥의 공간이 남았다. 이번 수정은 그 공간을 기존 외벽과 바닥 단면에 맞춰 메운다.

각 하판의 Y=95,117 mm에서 폭 6.20 mm 구간을 복원한다. 외벽은 왼쪽 X=-1.50..-0.30, 오른쪽 X=149.70..150.90 mm이고 Z=-2.20..4.10 mm이다. 바닥 복원은 기존 외벽 안쪽 3.20 mm 폭, Z=-2.20..-1.00 mm에 한정한다. 기존 두께와 외곽 안에서 빠진 재료만 추가하며, 부품 보호 공간과 PCB 여유를 먼저 확인한다.

검증 자료는 이 디렉터리의 generation, review, native-generation, native-review, tests 기록과 [STL 실제 단면 비교](wall-sections.png)에 있다. 원본 바이트와 최종 출력물은 `hardware/MODELS/kc2_smooth_central_housing_manifest.json`으로 연결한다. 이전 입력 형상은 Git `9e0bb01`에 보존한다.

검증 범위는 실제 STEP 재열기, 기존 재료 보존과 추가 영역 제한, 실제 STL 폐쇄성 및 외벽/바닥 단면 연속성, 맞은편 하우징과 새 재료의 간섭, 우측 A/B 간격, 실제 Fusion 저장·재열기·STEP 재출력 일치이다. 상판, 기존 자석 및 부품 보호 영역 밖의 재료는 변경하지 않는다. 실물 강도·출력 공차·자석 고정력은 별도 출력 시험이 필요하다.

실제 재료 추가량은 일반형/자석형 각각 왼쪽 29.448 mm³, 오른쪽 25.4529974 mm³이다. 기존 재료 삭제, 복원 범위 밖 추가와 STEP 복원 누락은 모두 0 mm³이다. 실제 STL 단면 누락 최대치는 0.000000544 mm²로 STL 좌표 정밀도 범위이다. 새 재료와 맞은편 하우징 사이 최소 간격은 0.800 mm, 교차 체적은 0 mm³이다. 우측 A/B 실제 간격은 기존과 동일한 0.400031432 mm이다. 관련 회귀시험 23개와 Git 바이트 보존 시험 2개가 통과했다.

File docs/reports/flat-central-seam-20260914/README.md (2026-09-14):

# KC2 평면 중앙 이음 개정 검증

요구사항: `CON-ARCH-006`, `CON-ARCH-007`, `OPS-ARCH-006`.

## 결과

- 일반형과 자석형 하판에서 중앙 비잠금 안내/마찰 요철 두 쌍(`Y=95, 117 mm`)을 모두 제거했다.
- 변경은 기존 면 밖으로 돌출된 재료의 감산뿐이다. 제거량은 좌측 각 `20.128 mm³`, 우측 각 `21.584 mm³`이며 추가 재료, 허용 창 밖 삭제, 과거 보호 재료 삭제와 남은 돌출부는 모두 `0 mm³`이다.
- 자석형의 기존 두 쌍(`Y=103, 111 mm`)과 전체 자석 감산 체적 `21.7146884216 mm³/측`은 그대로다.
- 컨트롤러 쪽 세 번째 자석 쌍은 추가하지 않았다. `0.1 mm` 간격으로 조사한 유효 범위에 안전하게 정렬되는 후보가 없었다. `Y=92 mm`의 가장 가까운 후보는 좌측 필요 잔여 재료가 `0.0972156518 mm³` 부족했고, `Y=97 mm`는 양쪽 모두 `4.5770181305 mm³` 부족했다. 안전한 원거리 구간의 자석 면 간격은 약 `31.9125 mm`여서 유효 흡착 위치가 아니다. 외벽 확대 금지 조건을 지켜 무리하게 추가하지 않았다.
- 네 STEP과 여섯 STL을 독립 재개방했다. 몸체 수, 유효성, 예상 감산 형상, 메시 체적/경계, watertight 단일 shell과 150 mm 출력 범위를 확인했다.
- Fusion `2705.1.11`에서 네 STEP을 F3D로 저장하고 다시 열어 STEP readback까지 수행했다. 모든 몸체의 체적·표면적·중심·경계가 일치했다.
- 35개 현재 CAD 파일 중 하판 14개만 교체하고 상판 21개는 바이트 그대로 유지했다. 주문된 PCB/Gerber 16개도 바이트 그대로 유지했다.
- 기존 하우징 회귀 356개와 이번 개정 회귀 21개, 총 377개가 통과했다.

## 게시 위치

- 현재 manifest: `hardware/MODELS/kc2_flat_central_housing_manifest.json`
- 인쇄 안내: `hardware/MODELS/PRINT-flat-central-housings.md`
- 실제 인쇄 파일: `hardware/MODELS/*.stl`

현재 상태는 `digitally_verified_physical_pending`이다. 출력 팽창·수축, 자석 접착/흡착력, 실제 좌우 감촉과 장기 강도는 시험 출력 후 확인해야 한다.

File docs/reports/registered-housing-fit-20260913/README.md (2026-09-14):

# 외벽·상판 위치맞춤 및 결합부 개정 검증

대상은 `kc2-x3-v2`, 요구사항은 **CON-ARCH-006, CON-ARCH-007, OPS-ARCH-006**이다. 요구사항의 기준은 [SRS](../../spec/10.product-architecture.srs.md)이며, 이 문서는 기계 설계의 검증 증거를 요약한다.

## 현재 상태

개정 모델의 실제 STEP/STL, Fusion 재출력, 부품 공간, 조립 및 전체 외형 검사가 통과했다. 최종 소스에 연결된 70개 모듈의 356개 회귀시험도 통과했다(239.256초, exit0, errors 없음). **Canonical 발행과 사후 검증, 임시 폴더 없는 격리 검증까지 통과했다.** [게시 확인 기록](publication-confirmation.json)이 최종 manifest와 독립 실행 증거를 연결한다. 실물 적합성 승인은 아니며 첫 출력의 끼움·강도·브리지 품질을 확인해야 한다.

## 변경 범위

- PCB는 이전처럼 하판 위에 놓인다. 기존 소켓 가림벽, 바닥, 70개 키 지지 위치와 17개 나사 위치를 유지하면서 외벽과 상판 위치맞춤 구조를 추가했다. 하판 일반 외벽 상단은 Z=4.10 mm, 위치맞춤 돌기는 Z=5.00 mm이며 상판 홈과의 실제 측면 간격은 0.25 mm다.
- MX, Choc V1, Deep Sea Mini 상판 3종과 공통 하판의 무자석/`magnetic` 2종을 유지한다. 오른쪽은 프린터 크기에 맞춰 A/B로 나뉜다. 발행 목록은 **10 STEP + 10 실제 Fusion F3D + 15 STL = 35 CAD 파일**이다. 기존 링 어댑터는 이 35개 개정 목록에 포함하지 않는다.
- 좌우 중앙 결합은 국소 가이드의 작은 의도된 접촉으로 유격을 줄인다. 실제 조립에서 발견한 불필요한 겹침은 새 왼쪽 외벽·바닥만 국소 절삭해 제거했고, 기존 하판과 실제 결합 돌기 두 개의 손실은 각각 0으로 확인했다.
- 오른쪽 하판 A/B 결합은 2.0 mm 목·4.5 mm 머리와 약0.4 mm 틈을 유지한다. 상판 머리는 4.0 mm다. 얇은 내부 돌출부는 둥글게 정리하고, 하판 수평 이탈 방지는 연속된 1.2 mm 바닥층과 충분한 주변 재료로 검증한다. 나사 체결을 대체하는 영구 잠금 구조로 간주하지 않는다.
- 자석형은 지름2 mm·두께1 mm 자석용 기존 지름2.4 mm/깊이1.2 mm 홈과 뒷벽을 보존하고, 새 외벽을 통과하는 삽입 통로도 검증했다. 자석 면 사이의 명목 간격4.40 mm는 외벽 사이 간격과 다르며, 자력·유지력은 실측하지 않았다.

## 실제 검사와 결과

| 검사 | 확인한 범위와 결과 |
|---|---|
| 상판 6개 작업 | 실제 BRep의 완전한 높이 구간·단면, 스위치/클립/나사 공간 및 오른쪽 분할 형상 검사 통과 |
| 하판 4개 작업 | 원래 형상 보존, 부품·서비스·나사 공간, 새 외벽 및 위치맞춤 형상 검사 통과 |
| 바닥·인쇄 형상 | 4개 하판 작업의 연속된 1.2 mm 바닥층, 닫힌 단면과 내부 바닥 구멍 부재 확인. 전체 15 STL의 닫힘·일관된 면 방향·양의 체적·150 mm 출력 범위 검사 통과 |
| 오른쪽 A/B | 무자석/자석형 모두 바닥층 수평 포획, 주변 재료, 머리·목, 간격 및 이동 검사 통과 |
| 자석 삽입 | 좌우 각 두 곳의 바깥에서 홈까지 연속 통로, 원래 홈·주변 재료·뒷벽 보존 및 선택적 제거 체적 검사 통과 |
| 좌우 중앙 | 무자석/자석형 두 접점씩 실제 조립 검사 통과. 의도된 접촉 외 겹침, 변형 공간·윗공간·삽입 경로 방해 없음 |
| 상하판 조립·전체 외형 | 상판3종 × 하판2종을 양쪽에서 검토. 검사한 높이 구간의 겹침0 및 위치맞춤 간격 확인. 중앙 접촉은 별도 실제 검사로 분리 |
| Fusion 재출력 | 10개 작업 모두 실제 F3D 저장·재개방·STEP 재출력 후 독립 형상 검사 통과. 하판4개는 원본과 재출력의 전체 재료 차집합이 양방향 정확히0 |

최신 전체 외형 보고서 SHA-256은 `3befa770361b7b923cecf4bf652f2f19f58e34634c1df41a9d249bc759a15fc0`(272개 소스 연결)이다. 왼쪽 조립 보고서는 `b833e95cf28b8b64229bdd2cfa9387920921b7e6a13b83471a7111faa945023c`(170개), 오른쪽은 `e1e07332b99727dcd74c6a40635be0282a69b37468eb5bca3833f82bdc7c0db2`(136개)다. 발행 전 원본은 `.codex-tmp/registered-housing-fit/`에 있으며, 발행 뒤에는 manifest가 지정한 증거 사본과 바이트 연결을 사용한다.

## 검증 방법의 구분과 보존 이력

실제 CAD 검사는 STEP을 읽어 단면·재료·간섭을 계산했다. 반면 하판의 native feature 보고서10개는 **원본 실제 검사 + 전체 재료의 양방향 차이 정확히0**에 근거한 명시적 증거 전이다. `exact_zero_whole_material_difference`, `native_feature_rerun=false`로 기록하며, native의 각 기능을 다시 계산했다고 주장하지 않는다. 소스·native·실행 코드 연결이 모두 일치해야 전이가 유효하다.

오른쪽 부품 공간의 원래 Boolean 실패값은 삭제하지 않았다. 최종 방법은 무자석형 전체 Z 구간의 실제 단면 검사와 자석형이 그 형상에서만 재료를 제거했다는 실제 증명을 결합한다. 중단된 612쌍 거리 검사를 완료나 PASS로 바꾸지 않았다. 얇은 receiver 돌출부, 정확히0 면적 STL facet, 중앙 외벽의 실제 겹침, 과도한 nominal 돌기 보호 기준 때문에 중단된 시도도 [진단 이력](diagnostics/README.md)에 보존했다. STL 처리는 정확히0 면적 facet만 제거하며, 정상 facet 좌표 변경·welding·hole filling은 하지 않는다.

발행기 STEP 형식 처리 개정 전 통과 보고서들도 별도로 보존했다. 현재 조립·전체 외형·native 전이 보고서는 개정 후 실행한 결과이며, 과거 PASS를 새 코드의 결과로 재사용하지 않았다.

## 아직 소프트웨어가 보증하지 못하는 것

인쇄 수축·팽창, 층간 접착과 작은 연결부 강도, 중앙 마찰·삽입력·반복 수명, 나사 토크, 자석 유지력, 실제 소켓 접점 공차, 선택한 키캡의 전 스트로크 간섭, 배터리 팽창·배선·RF는 실물 확인이 필요하다. 현재 전체 외형 검사는 실제 키캡 조립의 적합성 증명이 아니다. 중앙 국소 외벽의 브리지도 실제 인쇄 품질 확인이 필요하다. 실리콘 발의 배치·접착·무게중심 검토는 사용자 지시로 이번 범위에서 제외했다. 바닥 구조 검증은 제외하지 않았다.

이번 작업은 기계 하우징 개정이며 주문된 PCB/Gerber 16개 파일의 바이트 보존을 최종 발행·사후 검증·격리 검증에서 확인했다. 새 PCB 제작 패키지, 구매·결제 또는 양산 적합성 승인은 포함하지 않는다. `physical_qualified=false`를 유지한다.

## 발행과 재현

최종 파일은 [hardware/MODELS](../../../hardware/MODELS/README.md)에 게시했다. [현재 인쇄 안내](../../../hardware/MODELS/PRINT-registered-housings.md)에서 상판 한 종류와 하판 한 종류를 선택한다. Manifest는 `kc2_registered_housing_manifest.json`이며 71개 보고서와 329개 소스 연결을 기록한다. Git index의 발행 관련 350개 파일도 검토된 바이트와 일치했다.

[격리 실행 기록](isolated-verification.json)은 독립 Git 객체를 가진 별도 저장소에서 516개 파일이 변하지 않았고 `.codex-tmp` 없이 동일한 실제 보고서 검증을 통과했음을 기록한다(exit0, errors 없음, 828.297초). 검증을 게시 사후 검사와 병행했으므로 원본 기록의 candidate 표기는 보존했다. 실제 게시 성공 후 동일 manifest SHA를 대조한 [확인 기록](publication-confirmation.json)이 이를 최종 게시본에 연결한다. 이는 전체 CAD를 새로 생성한 실험이 아니라 게시 증거의 독립 재검증이다.

[REPRODUCE.md](REPRODUCE.md)는 증거 검증과 격리 재생성 순서를 설명한다. 기준 CAD는 Git commit `5b99bcb4567ea1c6bb4f17e54887d4de7614cd03`으로 고정하며, **발행 후 메인 작업 폴더에서 기준 CAD를 요구하는 생성기를 바로 재실행하지 않는다.** 문서화된 절차 자체는 전체 재생성을 새 환경에서 완료했다는 증거가 아니다.

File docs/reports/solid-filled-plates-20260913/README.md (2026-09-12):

# 내부 충전형 보강판 개발 기록

요구사항: `CON-ARCH-006`, `CON-ARCH-007`, `OPS-ARCH-006`.
상태: 디지털 구현·실제 형상 검증·최종 게시 완료. 현재 `hardware/MODELS`에는 MX, Choc V1, Deep Sea Mini의 내부 충전형 상판이 게시되어 있습니다. 실물 출력·부품 편차·체결 강도 검증은 별도입니다.

현재 파일 선택은 [인쇄·조립 안내](../../../hardware/MODELS/PRINT-filled-plates.md)를 따릅니다. [게시 manifest](../../../hardware/MODELS/kc2_filled_plate_manifest.json)는 상판 21개 파일과 보존한 하판 14개·PCB/거버 16개를 포함한 124개 바이트 바인딩을 검사합니다. 이전 보강 MX 상판은 Git `d9d3729`에 보존했고, 이전 manifest는 `previous-local-cover-manifest.json`에 기록으로 옮겼습니다.

`final-tests.json`의 47개 회귀시험, 여섯 원본 STEP 전체 단면, 아홉 STL 및 독립 설계 계약, 여섯 실제 Fusion 저장·재열기·읽기 결과의 전체 단면, 하판 포함 좌우 조립 검사가 통과했습니다. 각 종류/좌우의 `*-sectional-progress.json`은 원본 STEP 검사, `*-native-review.json`은 실제 재열기 형상 검사입니다. 원본 STEP과의 단면 검사는 독립 계약 및 STL 검사와 함께 사용하며 단독으로 전체 검증을 주장하지 않습니다.

`portable-verification.json`은 게시 파일만 새 임시 디렉토리에 복사한 후 `python -S`로 사이트 패키지 없이 검증한 실행 기록입니다. 정상 검증·복원 검증이 통과했고, STL 변조·출력 목록 누락·Deep Sea native 증거 누락 세 경우를 모두 거부했습니다. 임시 CAD 작업 경로는 보고서의 원래 관측 위치이며 게시 검증기는 이를 실제 저장소 파일에 대응시킵니다.

목표는 Choc V1, 선택된 저상형 Kailh Deep Sea 갈축, MX 세 종류 모두의 구조 공간을 실제 CAD 솔리드로 채우는 것입니다. 벽만 두껍게 하거나 슬라이서 인필 설정만 바꾸는 결과로 대체하지 않습니다. 스위치/클립, 나사 통과 홀·머리 포켓, PCB 비접촉 여유 및 컨트롤러/서비스 공간은 보호합니다.

## 현재 구현

`tools/kc2_solid_plate.py`는 보호 공간의 높이 경계마다 전체 단면을 채웁니다. `tools/kc2_filled_plate_profiles.py`는 세 조립 높이를 구분합니다. `tools/generate_kc2_filled_plates.py`는 실제 PCB 좌표를 읽어 `.codex-tmp/solid-filled-plates`에 생성합니다. 임시 출력은 최종 인쇄 승인 파일이 아닙니다.

실패 우선 테스트로 빈 내부를 남긴 벽-only 결과, 나사홀 충전, 맞지 않는 높이, 분할 틈 충전을 거부했습니다. 실제 좌표 검사에서 기존 A/B 맞물림 홈이 채워지는 문제가 검출되어 반대편 돌기의 여유를 추가로 보호했습니다. 단면 검사기는 실제 BRep의 모든 면이 수직/수평 평면이고 모든 꼭짓점 높이가 예상 경계임을 먼저 확인합니다. 그 뒤 각 높이 구간 단면 전체와 요구 영역을 비교하므로, 단순 체적 일치만으로 통과시키지 않습니다. 숨은 중간 높이 공동과 기울어진 면을 거부하는 변이 시험을 포함합니다.

`tests-progress.json`은 코어·치수·실제 좌표 계획·합성 솔리드 시험 증거입니다. 실제 여섯 전체 보강판의 검토, 출력 메시 검사, Fusion F3D 재열기 및 게시 검증을 대체하지 않습니다.

## 추가 검증 진행

`verifier-tests.json`: 35개 회귀시험 통과. 생성기의 프로파일 표·채움 함수를 호출하지 않는 독립 치수/단면 재계산, 누락된 내부 재료·막힌 나사홀·변경된 분할 마스크·잘못된 높이를 거부하는 시험, 실제 STL 검증기 및 여섯 Fusion 작업 사전검사 시험을 포함합니다. 기존 PCB 좌표 추출기와 기존 서비스/분할 인터페이스는 공유하므로, 부품 실측까지 독립적으로 수행했다는 뜻은 아닙니다.

세 종류 좌우 STEP 6개 및 인쇄 STL 9개가 임시 작업 위치에 생성됐습니다. [실제 메시·독립 설계 검사](mesh-contract-review.json)에서 9개 실제 STL은 모든 표면이 수직/수평이고 꼭짓점 높이가 설계 경계에 있는지 먼저 확인한 뒤, 각 높이 구간의 단면 전체를 독립 설계와 비교하여 모두 통과했습니다. STL 좌표 양자화 허용치는 높이 0.00001 mm, 단면 누락/초과 면적 각각 0.02 mm²이며, 큰 공동이나 나사홀 충전을 허용하는 공차가 아닙니다. 실제 STL에서 측정한 보강판 좌우 최소 간격은 MX 0.445999 mm, V1 및 Deep Sea 1.299999 mm이고 투영 겹침은 0입니다.

[하판 포함 조립 검사](assembly-review.json)도 통과했습니다. 이전 실제 CAD 검증과 바이트가 일치하는 하판의 전체 외곽과 새 STL의 전체 외곽을 합쳐 기존 좌우 위치에서 검사했습니다. MX 최소 0.445999 mm, V1/Deep Sea 최소 1.299998 mm, 투영 겹침 0입니다. 기존 하판 14개 CAD 파일과 주문된 PCB/거버 16개 파일이 그대로임을 함께 확인했습니다. 이 검사에는 실제 부품·키캡의 제조 편차나 조립 하중이 포함되지 않습니다.

`tools/fusion/KC2FilledPlatesToF3D/KC2FilledPlatesToF3D.py`로 여섯 STEP을 실제 Fusion에서 열고 F3D를 저장한 뒤 다시 열어 STEP으로 읽어내는 작업이 모두 통과했습니다. 원본 STEP 여섯 개의 전체 단면 검사와 `tools/review_kc2_filled_native.py`의 독립 계약 대비 native 형상 검사도 모두 통과했습니다. `*.native-readback.step`은 인쇄용 대체 모델이 아니라 F3D 재열기 검증 증거입니다.

## 치수 근거 및 한계

[V1 가족 도면](https://www.kailhswitch.com/Content/upload/pdf/201915927/CPG135001D01_-_Red_Linear_Choc.pdf)의 장착 단면과 기존 0.20 mm 링 테두리를 반영한 공학 모델입니다. 특정 수령 V1 축의 실측값은 아닙니다.

[Kailh 저상형 정음 가족 도면](https://www.kailhswitch.com/uploads/15927/files/CPG1353S01D01-01-data-sheet.pdf?rnd=494)은 임시 선형 모델 도면입니다. 클립 틈 1.35와 하부 0.80에서 판 높이 2.15 mm를 추론했습니다. [Deep Sea Mini 판매 페이지](https://kailhswitch.net/products/kailh-deep-sea-silent-min-low-profile-keyboard-switch)의 Whale 선택과 이전 갈축 로트를 이 도면과 동일한 제어 도면으로 확정한 것은 아닙니다. 정상 높이 Deep Sea Box와 혼동하지 않습니다.

| 설계값, mm | MX | Choc V1 + 링 | Deep Sea Mini 가족 기준 |
|---|---:|---:|---:|
| 판 아래 Z | 7.80 | 5.30 | 5.05 |
| 판 위 Z | 9.30 | 6.50 | 6.25 |
| 머리 받침 Z | 7.80 | 5.10 | 5.10 |
| 보스 상단 Z | 9.30 | 6.60 | 6.60 |
| 명목 나사 길이 | 7.50 | 5.00 | 5.00 |

저상형 보스는 판보다 조금 높습니다. 실제 키캡 내부·전체 이동·체결 강도는 미검증이며, 기존 MX 나사를 저상형에 사용하지 않습니다. PCB/거버와 하판 두 옵션은 변경하지 않았습니다. 디지털 납품 목표가 완료되어도 이런 실물 검증이 자동으로 통과되는 것은 아닙니다.

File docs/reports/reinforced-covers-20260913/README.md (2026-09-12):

# 가림벽 파손 대응 보강 검증

요구사항: `CON-ARCH-006`, `OPS-ARCH-006`; 조립 기준 보존: `CON-ARCH-007`.

사용자가 기존 약 0.40 mm 가림벽의 출력 후 파손을 보고했습니다. 이번 개정은 하판과 MX 상판의 국소 가림벽을 명목 1.20 mm, 바닥·판 연결 겹침을 0.80 mm로 보강합니다. 기존 PCB 안착 높이, 소켓 공간, 체결 위치, 좌우 결합 위치와 무자석/자석 선택을 유지합니다. 주문된 PCB와 거버는 변경하지 않습니다.

이전 2026-09-10 검증 기록은 얇은 벽의 과거 디지털 증거이며 이번 보강 형상 또는 실물 강도에 대한 증거로 사용하지 않습니다.

보강 출력물의 개별 형상·조립·native 검증이 통과했습니다. 최종 게시 여부와 파일 일치는 `hardware/MODELS/kc2_local_cover_manifest.json`의 이 디렉토리 증거 연결 및 `python -B -m tools.publish_kc2_local_covers --verify` 결과로 확인합니다. 실제 출력 강도와 구매 부품의 조립 적합성은 재출력 확인 전까지 미검증입니다.

## 검증 범위

108개 소스 고정 회귀 테스트가 통과했습니다. 기존 0.40 mm 벽을 새 보강 벽으로 이름만 바꾸어 통과시키는 경우, 두께/연결 겹침 부족, 원래 받침 삭제, 전역 외벽 추가, 누락된 모서리와 잘못된 분할 등을 거부하는 테스트를 포함합니다. 실제 STEP/STL 검사 및 Fusion 재열기 검사는 별도 증거입니다.

Fusion 6개 F3D의 저장·재열기와 진단 STEP 재내보내기가 완료됐습니다. 동일 커널의 적응형 체적/치수 비교도 여섯 모델 모두 통과했습니다. 이는 파일 변환 시 형상 보존에 대한 증거이며 재출력 강도에 대한 증거가 아닙니다.

MX 상판의 좌우 실제 STEP/STL 검토가 통과했습니다. 세 인쇄 부품 모두 원본 삭제·요청 가림부 누락·허용 영역 밖 추가·보호 부품/서비스 공간 간섭은 0 mm³이고, 새 서비스/드라이버 접근 방해가 없습니다. 오른쪽 원본 부품 간, 보강 부품 간, 추가부와 맞은편 원본 간 및 추가부끼리의 거리는 모두 0.19975909123481658 mm로 기존 명목 0.20 mm 분할 여유를 보존합니다. 기존 서비스 접근 한계와 실제 출력 오차는 별도입니다.

좌우 하판의 무자석/자석 버전 실제 검토도 통과했습니다. 기준 r5 대비 추가 재료는 왼쪽 485.607831 mm³, 오른쪽 658.100031 mm³로 각 옵션에서 동일합니다. 원본 삭제, 허용 영역 밖 추가, 가림부 누락, 소켓/부품 및 나사 파일럿 침범은 모두 0 mm³입니다. 기존 자석 홈과의 차이도 추가/누락 모두 0 mm³입니다. 하판 6개 STL은 각각 닫힌 단일 몸체이고 STEP 형상 및 150 mm 출력 범위 검사에 통과했습니다. 오른쪽 기존 분할선의 국소 보강부 생략 면적 0.3852 mm²는 원래 0.20 mm 이음 여유에만 해당하며, 그 밖의 가림부 누락은 없습니다. 검사 시작/종료 소스 해시가 일치합니다.

네 실제 형상 검토를 묶은 전체 조립 검토도 통과했습니다. 기존 오른쪽 이동 X124.625/Y0에서 전체 하우징 평면 외곽의 최소 좌우 간격은 0.446 mm, 겹침은 0 mm²입니다. 하판 6개 STL의 무부품 무게중심은 원래 실리콘 발 지지 영역 안에 있습니다. 완전 실장 상태의 안정성과 실제 FDM 오차는 이 값으로 검증된 것이 아닙니다.

이 개정의 연결부 보강은 가림벽과 바닥·MX 판의 접합 겹침 확대입니다. 추가 요청된 “이음 부분”이 오른쪽 A/B 맞물림 돌기를 뜻하는지는 사용자에게 확인 요청했습니다. A/B 돌기 폭 확대·위치 이동은 사전 검토만 했으며 현재 형상에는 적용하지 않았습니다. 좌우 키보드를 기계적으로 잠그는 구조는 추가하지 않습니다.

출력 파일은 하판 6개 STL(일반형 3개 또는 자석형 3개 중 선택)과 공통 MX 상판 3개 STL입니다. STEP/F3D는 각 6개이며 오른쪽 전체 파일에는 분할된 두 솔리드가 들어 있습니다. 출력 개별 부품의 최대 평면 치수는 약 137.667 mm로 150 mm 범위 이내입니다. 바닥은 기존 1.20 mm, PCB 아래/위는 Z2.50/4.10, MX 판 아래/위는 Z7.80/9.30, 가림벽 아래 끝은 Z4.40을 유지합니다.

새 가림벽은 스위치·소켓의 기존 보호 공간을 채우지 않도록 바깥쪽으로 보강합니다. 스위치 몸체 보호 영역은 15.6 mm 기준이며, 키캡 안쪽 형상·실제 납땜 돌출·수령 부품 편차는 이 디지털 모델만으로 합격 처리하지 않습니다. 컨트롤러 서비스 방향의 기능상 개구부는 유지하며 기존 구조의 도구 접근 제한을 제거했다는 뜻이 아닙니다.

## 재현

각 side `left`/`right`에 대해 `tools.generate_kc2_local_covers`, `tools.kc2_local_upper_covers`로 생성하고 `tools.review_kc2_local_covers`, `tools.review_kc2_local_upper_covers`로 실제 STEP/STL을 검토합니다. 임시 생성 경로는 `.codex-tmp/reinforced-cover-build`입니다. 네 검토 통과 후 `tools.review_kc2_local_assembly`를 실행합니다.

Fusion에서 `KC2LocalCoversToF3D`로 여섯 파일을 내보내고 다시 엽니다. `KC2LocalNativeReview`의 `all` 작업은 F3D에서 검사용 STEP을 내보냅니다. `tools.review_kc2_local_native --label all`은 동일 커널과 적응형 체적 적분으로 원본/검사용 STEP을 비교합니다. 허용 오차는 기존과 동일하게 치수 0.001 mm, 체적 max(0.002 mm³, 원본 체적×1e-6)입니다. 검사용 `native-check-*.step`은 증거이며 인쇄/편집할 별도 활성 모델이 아닙니다.

`tools.collect_kc2_local_cover_tests`의 소스 고정 회귀 결과와 모든 형상·native 증거가 통과해야 `tools.publish_kc2_local_covers --apply`로 `hardware/MODELS`를 갱신할 수 있습니다. `--verify`는 임시 파일·Fusion·CadQuery 없이 게시된 실제 바이트와 증거 연결을 검사합니다. PCB/거버 16개 파일의 원본 바이트도 보존 검사합니다.

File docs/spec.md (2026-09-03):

# KC2 Keyboard Specification

## 개요

KC2는 KC1 핸드와이어링 키보드의 배열 철학과 결합/분리 사용성을 계승한 2세대 PCB 설계다. 한국어 2벌식 입력 습관을 반영한 오른손 `B` 키를 유지하며, 보강판 없이 variant별 SRS가 지정한 switch footprint와 assembly mode를 사용한다. 상부 하우징은 두지 않지만, 3D 프린터로 만든 하부 바닥판에 PCB를 고정하고 그 아래에 실리콘 feet를 부착한다.

## 핵심 요구사항

- 이름: KC2
- 형식: 좌우 분리형 split keyboard
- 배열: 일반 row-stagger 기반
- 키 수: 현재 정본 `kc2-x3-v2`는 `CON-ARCH-004`의 70-key v5 배열(왼쪽 31, 오른쪽 39)을 사용한다. 이전 77키 X3 정본은 Git 이력에서 보존하고, 그보다 앞선 71키 배열 설명은 historical routed draft baseline으로만 유지한다.
- 펌웨어: ZMK
- 컨트롤러: nice!nano v2, 좌우 각 1개
- 연결: BLE 중심, USB는 firmware flash/debug 및 필요 시 유선 출력용
- 백라이트/RGB: 없음
- 컨트롤러 소켓: 디바이스마트 상품번호 5494 `싱글라운드소켓(64핀)`, 2.54 mm pitch, 1열, round socket을 절단해 사용
- 배터리: `kc2-x3-v2`의 각 half는 301230-class, 3.7 V, 100 mAh Li-Po 1개를 사용한다. 정확한 제조사/MPN, single-cell protection 상태, 최대 팽창 두께와 lead 인출 도면을 조달 검토에 기록한다.
- 배터리/컨트롤러 전원 연결: `CON-ARCH-007`에 따라 배터리는 carrier PCB 상면과 socketed nice!nano 사이에 두고, 이미 배터리에 부착된 절연 lead만 `J_BAT1`에 직접 납땜한다. 탈착식 A2501/JST 배터리 커넥터와 bare pouch tab 납땜은 사용하지 않는다. `BAT_LEAD_SLOT1`은 하부 배터리 출구가 아니라 copper-free strain relief로 유지한다.
- PCB 전원 커넥터/패드: `kc2-x3-v2`에는 direct-solder `J_BAT1`, `SW_PWR1`, local `BAT+`, `NN_B+`, `GND` 경로를 둔다. `BAT+`만 IMMS-12V로 차단하고 B-는 local GND에 직접 연결한다. Promoted/historical X3의 no-carrier-power 계약은 `CON-ARCH-002` 기록으로만 유지한다.
- 키스위치: variant별 SRS requirement가 지원 switch family와 assembly mode를 정의한다. `kc2-x3-v2`는 `CON-ARCH-004`에 따라 Choc V2 socket-only 및 MX solder-only로 제한한다.
- 스위치 실장: 현재 정본 `kc2-x3-v2`는 Choc V2 bottom-side socket assembly와 MX 5-pin direct-solder assembly만 허용한다. 이전 Choc V1 중심 X3 정본은 Git 이력에서만 보존한다. V2는 물리 coupon 실장 검증 전까지 주문 불가이다.
- 스위치 footprint 기준: 일반 KC2 footprint는 다중 호환 hole/pad pattern을 목표로 하되, 더 좁은 variant별 SRS requirement가 있으면 그 요구사항을 우선한다.
- 큰 키: 현재 X3 no-stabilizer layout은 `>=2u` 키를 모두 분할하므로 stabilizer footprint를 생성하지 않는다. stabilizer가 필요한 별도 layout은 실물 체결 검증 전 generic/MX-style placeholder hole로 발주하지 않는다.
- 프로그래밍용 택트 스위치: 디바이스마트 상품번호 1322056 `NW3-A06-B3`, SMD micro tact switch, 6.1 mm x 3.7 mm급 body, 2.55 mm급 높이
- 전원 스위치: `kc2-x3-v2`의 각 half에 IMMS-12V 형상 후보 1개를 둔다. `IMMS-12V`와 `BSI-10` 명칭은 동일 제조품임이 확인된 것으로 간주하지 않으며, exact manufacturer/MPN/drawing 또는 incoming inspection이 물리 gate로 남는다. Top/component-side view에서 USB 바깥쪽부터 POWER, RESET, antenna 순서이며, 절대 좌→우 순서는 왼쪽 `PWR|RST`, 오른쪽 `RST|PWR`이다.
- 보강판: 없음
- 하우징: 상부 하우징 없음. 3D 프린터 하부 바닥판을 사용한다.
- PCB 수량: 좌우 독립 PCB 2장

## 제조 파일 제출

`OPS-ARCH-006`에 따라 main path와 fabrication ZIP은 현재 정본 `kc2-x3-v2` 전용이다. 이전 X3 Gerber/ZIP이나 주문 가능 판정을 V2 증거로 사용할 수 없다. V2의 디지털 PCB 검증은 통과했지만 `CON-ARCH-004`, `CON-ARCH-006`, `CON-ARCH-007`, `REL-ARCH-001`의 물리 gate가 남아 있으므로 **ORDER READY: NO**이다.

2026-09-03 기준 V2 fabrication, 1:1 mechanical, housing STEP/STL, coupon, joined SVG/PNG 산출물은 exact Diodes Incorporated `1N4148W-13-F` SOD-123과 둥근머리 P3 reinforcement 좌우 정본 보드 SHA-256 `3a6f80a5bc1afe897056107be9522a26079766fd4963f2115a9237737470268d` / `a4361040d81b3189cce8cdfcedaf54e570248d2fd513835dfadf80bcc187ef6d`에 맞춰 재생성했다. 현재 라우트는 좌 616 / 우 803 items이고 digest는 `b37c88d783baa27e6358d1c3baf33528d282934c41c507f2da5edc44e739ebbb` / `44a0c7fdd446f3153d2faf2506194947577b74147713c9a097c7ac83a9c1a964`이다. 새 DRC와 모든 소스 결속 산출물이 디지털 검증을 통과했다. 이는 디지털 증거이며 주문 승인은 아니다. 활성 V2 실행 gate는 `tools.verify_kc2_x3_v2`와 V2 전용 fabrication/mechanical/housing/coupon/render verifier이다. `kc2-pcb-preflight` skill의 부품별·회로별 review workflow는 추가 감사에 적용하되, 번들 CLI는 historical `--variant x3`만 지원하므로 그 `ORDER READY` 결과를 V2 근거로 사용할 수 없다.

Historical KC2 X3 main PCB는 좌우 독립 PCB 2장이므로 PCB 제조사 제출 파일도 좌/우를 분리해서 다룬다. `hardware/kicad/fabrication/kc2_fabrication.zip`처럼 좌/우 산출물을 함께 담은 합본 ZIP은 저장소 내부 검증/보관용 묶음이며, JLCPCB 같은 제조사에 단일 비패널 PCB 주문으로 그대로 제출하지 않는다.

기본 주문 방식은 좌/우 fabrication directory를 각각 별도 ZIP으로 묶어 별도 PCB 주문으로 제출하는 것이다.

- Left: `hardware/kicad/fabrication/kc2_left/`
- Right: `hardware/kicad/fabrication/kc2_right/`

JLCPCB 제출용 개별 ZIP은 다음 두 파일을 사용한다.

- Left order ZIP: `hardware/kicad/fabrication/kc2_left_jlcpcb.zip`
- Right order ZIP: `hardware/kicad/fabrication/kc2_right_jlcpcb.zip`

각 ZIP에는 Gerber copper, solder mask, solder paste, silkscreen, Edge.Cuts, Gerber job 파일뿐 아니라 PTH/NPTH Excellon drill 파일과 drill map/report를 함께 포함해야 한다. "거버 파일"이라고 부르더라도 drill 파일을 빼면 발주용 패키지로 인정하지 않는다.

현재 주문 가능한 X3 좌우 PCB에는 하단면 `B.Silkscreen`에 각각 `KC2 v1.0 L` 및 `KC2 v1.0 R` 제품/버전 식별자를 넣는다.

좌우 PCB를 한 주문 안에 넣으려면 단순히 두 보드 파일 세트를 한 ZIP에 섞지 말고, 의도적인 customer panel Gerber를 별도로 생성한 뒤 서로 다른 디자인 2개를 포함한 panelized order로 제출한다. 이 경우 제조사의 different-design/panel 옵션, 추가 비용, V-cut/tab-route 분리 조건을 주문 전에 확인한다.

이전 soldered, hotswap, x1, x2 KiCad 산출물은 `hardware/kicad/draft/` 아래에 보관한다. 제조와 검증의 기본 진입점은 `hardware/kicad/kc2_left/`와 `hardware/kicad/kc2_right/`이다.

## 한국어 입력 요구사항

KC2는 KC1의 한글 2벌식 입력 방식을 이어받아 `ㅠ` 입력을 자연스럽게 하기 위한 오른손 `B` 키를 가진다.

KC1과의 관계는 배열 철학과 사용성의 계승이며, KC2의 하드웨어 프로젝트명과 펌웨어 식별자는 별도 세대인 `kc2`로 통일한다.

- QWERTY 기준 `B`는 왼손 알파열 위치에 유지한다.
- 오른쪽 하단에도 추가 `B` 키를 둔다.
- 오른쪽 하단 `B`는 한글 2벌식 `ㅠ`를 오른손으로 입력하기 위한 필수 키다.
- PCB 설계 시 오른쪽 하단 `B` 키를 삭제하거나 다른 키로 대체하지 않는다.

## 물리 구조

- 무보강판 구조다.
- 상부 하우징은 없다.
- PCB 아래에는 3D 프린터로 제작한 하부 바닥판을 둔다.
- PCB가 전기 회로이자 variant별 switch footprint, socket, 또는 solder joint의 기준 구조물이다.
- 키스위치 고정/실장 방식은 variant별 SRS requirement를 따른다. 현재 정본 `kc2-x3-v2`는 `CON-ARCH-004`에 따라 Choc V2 bottom-side socket assembly와 MX 5-pin direct-solder assembly만 허용한다.
- 현재 정본 `kc2-x3-v2`는 `CON-ARCH-006`의 조건부 M1.4 retention prototype을 사용한다. PCB에는 좌 8개/우 9개의 `1.60 mm` copper-free NPTH가 있고, 2.50 mm 하우징에는 해당 위치의 zero-gap land/desk column과 `1.10 x 2.80 mm` blind pilot가 있다. 사용자가 선택한 나사 머리는 접시/저두형이 아닌 둥근 pan/button 형상이며, exact MPN 도면 전까지 최대 `3.00 x 1.20 mm` 포락선과 별도 `0.25 mm` 조립 여유를 적용한다. 31/39 일대일 키 하중 지지대가 주 타건 하중 경로이며, exact screw/driver, full-pattern fit, torque/repeat cycle, keycap skirt, 2 N deflection 실측 전에는 주문할 수 없다.
- stabilizer가 필요한 별도 layout의 큰 키 stabilizer는 plate-mounted가 아니라, 무보강판에서 실제로 고정되는 PCB-mounted/PCB-retained 방식을 사용한다.
- PCB 외곽선은 키 배열, 결합부, controller 돌출부, USB-C 접근 방향을 따라 최대한 타이트하게 잡는다.
- 실리콘 feet는 PCB가 아니라 3D 프린터 하부 바닥판 아래에 부착한다.
- 기존 M2 고정 방향은 routed draft baseline 기록으로 유지한다.
- X3 screwless rail housing 방향에서는 PCB의 모든 M2 나사 구멍을 제거하고, FDM PLA+ 하부 트레이의 레일/턱과 3.0 mm NPTH 등록 구멍으로 위치를 잡는다.
- X3 screwless rail housing의 PCB 두께는 1.6 mm로 주문한다.
- X3 screwless rail housing의 일반 외곽 rail land는 4.0 mm nominal로 두며, 검증된 국소 구간에 한해 3.6 mm hard lower bound를 허용하고 강도/공차/배선 때문에 필요한 구간은 5.0 mm까지 허용한다.
- X3의 접착제는 1차 고정 수단이 아니라 필요 시 보조 수단으로만 검토한다.
- 배터리, 납땜부, diode lead/pad, controller pin이 하부 바닥판 또는 책상과 직접 닿아 쇼트되지 않도록 한다.

## 무보강판 스테빌라이저

KC2는 상부 보강판이 없고 PCB 또는 switch socket이 switch retention/assembly 구조의 일부가 되므로, 큰 키의 stabilizer는 단순한 plate-mounted low-profile stabilizer를 사용할 수 없다. 조사 결과 Kailh Choc V1/V2 계열 stabilizer는 일반적으로 PCB cutout과 1.2 mm급 switch plate cutout을 함께 요구한다. 따라서 KC2에서는 "PCB에 구멍만 있는 상태"로 실제 부품이 고정되는지 검증되지 않은 footprint를 발주용으로 인정하지 않는다.

현재 정본 `kc2-x3-v2`는 `CON-ARCH-004`와 `docs/spec/20.kc2-no-stabilizer-layout.md`가 정의한 70-key v5 layout(왼쪽 31, 오른쪽 39)을 사용한다. 이전 77-key X3는 Git 이력의 historical baseline이며 두 variant 모두 stabilizer footprint를 생성하지 않는다. 아래 2u 이상 key/stabilizer 검토 내용은 이전 71-key routed draft baseline 또는 stabilizer가 필요한 별도 layout을 위한 historical design constraint로만 유지한다.

기존 71-key routed draft baseline과 stabilizer가 필요한 별도 layout에 대한 5개 서브에이전트 검토 결론:

- stabilizer가 필요한 별도 layout에서는 적용 기준을 `2u 이상`으로 둔다.
- stabilizer가 필요한 별도 layout에서도 `1.75u` 이하 key는 기본적으로 stabilizer를 넣지 않는다.
- 현재 KiCad generator의 `KC2:PCB_Mount_2u_Stabilizer_NPTH`는 Cherry MX PCB-mount에서 온 형태에 가까운 provisional keepout/placement marker다. low-profile 무보강판 발주용 final footprint가 아니다.
- stabilizer가 필요한 별도 layout의 최종 stabilizer family는 switch/keycap ecosystem과 함께 결정해야 한다. MX-style PCB stabilizer hole과 Choc/low-profile keycap/stabilizer를 섞어 발주하지 않는다.
- stabilizer가 필요한 별도 layout은 실물 stabilizer, keycap underside, switch footprint, 하부 바닥판 간섭을 1:1 출력물 또는 test coupon으로 확인한 뒤 final drill/cutout를 고정한다.

기존 71-key routed draft baseline에서 스테빌라이저가 필요했던 위치:

| Half | Key | Width | 위치 기준 | 결정 |
| --- | --- | --- | --- | --- |
| Left | `Shift` | 2.25u | Row 4, `Z` 왼쪽 | stabilizer 필수 |
| Left | `Space` | 2.25u | Row 5, 오른쪽 끝 | stabilizer 필수 |
| Right | `Backspace` | 2.25u | Row 1, `=` 오른쪽 | stabilizer 필수 |
| Right | `Enter` | 2.5u | Row 3, `"` 오른쪽 | stabilizer 필수 |
| Right | `Shift` | 2u | Row 4, `?` 오른쪽 | stabilizer 필수 |
| Right | `Space` | 2u | Row 5, `B_RH` 오른쪽 | stabilizer 필수 |

기존 71-key routed draft baseline에서 스테빌라이저를 넣지 않았던 위치:

- Left `Tab` 1.5u
- Left `Caps Lock` 1.75u
- Right `\` 1.75u
- 모든 1.25u, 1u key

stabilizer가 필요한 별도 layout의 배치 규칙:

- 모든 stabilized key는 현재 KLE key width의 중심에 switch center를 두고, stabilizer pair를 key의 긴 축 방향으로 switch center 좌우에 대칭 배치한다.
- KC2의 wide key는 모두 수평 key이므로 stabilizer bar 방향은 좌우 방향이다.
- 2u, 2.25u, 2.5u key는 기본 후보로 2u stabilizer spacing을 검토하되, 실제 keycap underside의 보조 stem 간격과 stabilizer wire 규격을 실측해 확정한다.
- low-profile/Choc stabilizer를 유지하려면 무보강판에서도 고정되는 part이거나, 하부 바닥판/별도 3D printed retainer가 stabilizer 이탈을 막는 구조여야 한다. 단, 별도 retainer는 보강판을 새로 추가하는 결정이므로 발주 전에 별도 검토한다.
- 최종 footprint에는 stabilizer body courtyard, wire swing/insert keepout, PCB cutout, NPTH drill, copper keepout이 모두 포함되어야 한다.

stabilizer가 필요한 별도 layout의 제조 및 routing keepout:

- stabilizer NPTH/cutout에는 top/bottom copper, trace, via, pad, zone이 겹치면 안 된다.
- stabilizer hole edge에서 copper/trace/via까지 최소 0.50 mm, 목표 1.00 mm clearance를 둔다.
- stabilizer hole edge는 PCB outline에서 최소 4.0 mm, 가능하면 5.0 mm 이상 떨어뜨린다.
- diode pad, diode body, switch/socket solder joint, Choc socket body/pad/solder fillet, MX switch pin/solder joint, historical/separate M2 layout의 M2 hole, 하부 바닥판 screw boss/rib는 stabilizer body courtyard와 겹치면 안 된다.
- routing과 diode 배치는 stabilizer footprint를 먼저 고정한 뒤 그 주변으로 피해서 잡는다. 공간이 부족하면 stabilizer hole을 줄이지 말고 diode 위치, diode package, trace layer, outline 순서로 재검토한다. historical/separate M2 layout에서는 M2 위치도 같은 기준으로 재검토한다.
- 하부 바닥판은 stabilizer clip, wire, keycap 하강 공간을 막지 않아야 한다.

조사 근거:

- Keebio Choc stabilizer installation: https://docs.keeb.io/choc-stabs
- LowproKB Kailh Choc stabilizers: https://lowprokb.ca/products/kailh-choc-stabilizers
- Keebio Kailh Choc V2 stabilizers: https://keeb.io/products/kailh-choc-v2-stabilizers
- splitkb Cherry 2u PCB Mount Stabilizer: https://splitkb.com/products/cherry-2u-pcb-mount-stabilizer
- Keebio Kailh PG1350 2u footprint reference: https://raw.githubusercontent.com/keebio/Keebio-Parts.pretty/master/Kailh-PG1350-2u.kicad_mod

## 외형 및 결합 구조

- KC2는 KC1처럼 좌우 키보드를 붙였다 뗐다 할 수 있어야 한다.
- 좌우 half를 붙였을 때 맞닿는 안쪽 edge는 다른 외곽보다 얇게 만든다.
- 왼쪽 keyboard의 오른쪽 edge와 오른쪽 keyboard의 왼쪽 edge가 결합 edge다.
- 결합 edge는 키캡 간격과 손가락 간섭을 줄이기 위해 최소 여백을 목표로 한다.
- 바깥쪽 edge, 손바닥 접촉부, controller 돌출부는 강도와 라운딩을 우선한다.
- 일반 PCB 외곽 테두리는 keycap 외곽 기준 5.5 mm를 기본값으로 하며, 부품/배선 조건에 따라 5.0-6.0 mm 범위에서 조정한다.
- 좌우 half가 맞닿는 결합 edge는 keycap 외곽 기준 2.8 mm를 기본값으로 하며, 허용 범위는 2.5-3.0 mm로 둔다. 2.5 mm 미만은 반복 결합/분리 시 파손 위험 때문에 사용하지 않는다.
- X3를 결합 상태로 배치할 때는 오른쪽 `Y`/`H` 쪽 돌출부가 왼쪽 `T`/`G` 쪽 홈으로 들어가는 interlocked placement를 기본 reference로 둔다. 좌우 PCB Edge.Cuts 사이의 최소 joined placement clearance는 `1.0 mm`로 둔다.
- X3 오른쪽 `Y`/`H` 돌출부의 세로 inner Edge.Cuts 면은 X3 inner-edge routing relief가 적용된 `3.6 mm` margin을 유지한다. X방향 끼임 여유는 세로면을 후퇴시키지 않고 돌출부의 가로 ledge 시작점만 안쪽으로 `0.8 mm` relief 처리해 확보한다.
- 3D 프린터 하부 바닥판의 치수 팽창, 밀링 burr, 자석 정렬 오차를 흡수하기 위한 실사용 clearance 허용 범위는 `0.8-1.2 mm`이며, `0 mm` 접촉은 좌표 정렬 확인용으로만 사용한다.
- joined placement clearance는 하부 바닥판/자석/정렬 구조의 배치 기준이며, PCB inner-edge routing relief 또는 copper-to-edge clearance를 줄이기 위한 값이 아니다.
- 결합 edge의 얇은 영역에는 가능하면 pad, via, diode lead, wire strain relief, screwless registration hole(`REG_NPTH_3.0`)을 두지 않는다. historical/separate M2 layout에서는 M2 홀도 두지 않는다.
- PCB edge-to-copper clearance는 일반 edge에서 1.0 mm 이상, 결합 edge에서 최소 0.8 mm 이상을 유지하되 가능하면 1.0 mm를 목표로 한다.
- PCB 외형은 단순 사각형이 아니라 키 배열 외곽을 따라 남는 공간을 최소화한다.
- controller가 놓이는 영역은 숫자열 바로 위에 붙은 돌출 탭 형태로 만든다.
- controller 돌출 탭의 X 위치는 결합 edge 쪽에 가깝게 두되, 탭의 결합면 쪽 끝은 실제 결합 edge보다 안쪽으로 들어가게 한다. 현재 draft 기준 왼쪽 half는 약 12 mm, 오른쪽 half는 약 17 mm recessed 배치로 둔다. 왼쪽 half는 오른쪽 결합 edge 쪽, 오른쪽 half는 왼쪽 결합 edge 쪽에 탭을 배치하되, 맞붙임을 방해하지 않아야 한다.
- controller 돌출 탭은 요철처럼 튀어나오되, 모서리는 둥글게 처리한다.
- controller 돌출 탭은 전기적 배치뿐 아니라 손가락/케이블/하부 바닥판 간섭을 함께 고려한다.
- X3 screwless rail housing에서는 M2 홀을 배치하지 않는다.
- X3에는 나사 체결이 아닌 하우징 등록/보조 포획용 3.0 mm NPTH `REG_NPTH_3.0` 홀을 각 half당 9개 배치한다. 중간 지지 홀은 PCB 중앙부 anti-flex 지점에 더 가깝게 배치하고, 실물 조립 식별을 위해 각 홀 주변에 `H1`-`H9` label을 둔다.
- 결합 edge의 2.8 mm 얇은 테두리 구간은 하부 바닥판의 연속 지지 리브로 보강한다.

## 배열

KC2의 PCB 설계에서는 물리 배열과 firmware 동작을 분리해서 본다. 사용자 제공 KLE와 실물 측정은 switch center, key size, stabilizer 위치의 기준이고, ZMK keymap은 각 물리 키의 동작 기준이다.

무보강판 low-profile no-stabilizer 방향의 최종 split layout은 하위 문서 `docs/spec/20.kc2-no-stabilizer-layout.md`를 따른다. 현재 정본은 `CON-ARCH-004`가 정의한 X3 V2 70-key v5 layout(왼쪽 31, 오른쪽 39)이며, 이전 X3 77-key layout과 그보다 앞선 71-key 배열 설명은 historical baseline으로 유지한다.

기존 71-key routed draft baseline의 왼쪽 half 물리 배열:

```text
Left half, 30 keys

Row 1: `  1  2  3  4  5  6
Row 2: Tab  Q  W  E  R  T
Row 3: Caps A  S  D  F  G
Row 4: Shift Z  X  C  V  B
Row 5: Ctrl Win Alt Fn Space
```

기존 71-key routed draft baseline의 오른쪽 half 물리 배열은 Keyboard Layout Editor raw data를 원본으로 둔다.

```js
[{x:0.5},"7","8","9","0","-","=",{w:2.25},"<-","DEL"],
["Y","U","I","O","P","[","]",{w:1.75},"\\",{a:7},""],
[{x:0.25,a:4},"H","J","K","L",":","\"",{w:2.5},"Enter",{a:7},""],
[{x:0.75,a:4},"N","M","<",">","?",{w:2},"Shift",{a:7},"",""],
[{x:0.75},"",{w:2},"","","","","","",""]
```

기존 71-key routed draft baseline의 오른쪽 half KLE 해석:

```text
Right half, 41 keys

Row 1: x0.50  7  8  9  0  -  =  Backspace(2.25u)  Del
Row 2:        Y  U  I  O  P  [  ]  \(1.75u)        blank/Home
Row 3: x0.25  H  J  K  L  :  "  Enter(2.5u)       blank/PgUp
Row 4: x0.75  N  M  <  >  ?  Shift(2u)             blank/Up  blank/PgDn
Row 5: x0.75  blank/B_RH  Space(2u)  blank/RAlt  blank/Fn  blank/RCtrl  blank/Left  blank/Down  blank/Right
```

기존 71-key routed draft baseline의 ZMK 기본 레이어 동작:

```text
Row 1: `  1  2  3  4  5  6      |  7  8  9  0  -  =  BSPC  DEL
Row 2: Tab Q  W  E  R  T         |  Y  U  I  O  P  [  ]     \    Home
Row 3: Caps A S  D  F  G         |  H  J  K  L  ;  '  Enter PgUp
Row 4: Shift Z X  C  V  B        |  N  M  ,  .  /  RShift Up PgDn
Row 5: Ctrl GUI Alt Fn Space     |  B  Space RAlt Fn RCtrl Left Down Right
```

기존 71-key routed draft baseline 배열 제약:

- 왼쪽 half는 `~`부터 `6`, `QWERT`, `ASDFG`, `ZXCVB`를 포함한다.
- 오른쪽 half는 `7`부터 시작하며 `YUIOP`, `HJKL`, `NM`, punctuation, nav column을 포함한다.
- split 경계는 왼쪽 `B`와 오른쪽 `N` 사이의 성격을 유지한다.
- 오른쪽 하단 `B_RH`는 KLE 5번째 row의 첫 blank 1u key position이며, 오른쪽 Space 바로 왼쪽에 둔다.
- 오른쪽 Space는 KLE 기준 2u key다.
- 오른쪽 `Backspace`는 2.25u, `\`는 1.75u, `Enter`는 2.5u, `Shift`는 2u key다.
- 우측 끝 nav column은 오른쪽 PCB outline에 포함한다.
- 왼쪽 half의 가장 왼쪽 keycap edge는 키캡을 씌웠을 때 같은 X선에 정렬되어야 한다. 즉 첫 열 switch center는 단순 stagger 값이 아니라 각 key width의 절반만큼 보정한다.
- 왼쪽 bottom row는 사용자 제공 KLE 기준 `Ctrl Win Alt Fn Space`이다.
- PCB silkscreen은 keycap legend 기준인지 firmware 동작 기준인지 제작 전에 확정한다.

## 펌웨어 스펙

- ZMK shield id: `kc2`
- ZMK shield siblings: `kc2_left`, `kc2_right`
- board target: `nice_nano_v2`
- left build shield: `kc2_left`
- right build shield: `kc2_right`
- split central: left half
- layer 수: 3
  - `default_layer`
  - `fn_layer`
  - `fn_layer2`

주의:

- 기존 71-key routed draft의 `fn_layer2` binding 수는 2026-06-02 검증에서 70개로 확인되어, 누락된 `&trans` 1개를 추가해 71개로 맞췄다. 현재 주문 가능한 historical X3 no-stabilizer 77-key keymap과 물리 검증 대기 중인 `kc2-x3-v2` 70-key v5 keymap은 각각 별도 검증 대상이다.
- PCB 제작 전 `./zmk/app/build.sh`로 좌우 firmware 빌드를 검증한다.
- 기존 `kc1` 펌웨어 식별자는 KC1 핸드와이어링/이전 설계 기록을 가리키는 이름으로만 남기며, KC2 제작용 ZMK shield id로는 사용하지 않는다.

## Matrix

- logical rows: 5
- logical columns: 16
- mapped positions: 77 for current historical X3 no-stabilizer; 70 for digitally verified but not orderable `kc2-x3-v2` under `CON-ARCH-004` (31 left / 39 right)
- transform row별 key 수: current X3 no-stabilizer physical rows 16 / 15 / 15 / 16 / 15; current X3 V2 v5 rows 15 / 14 / 14 / 15 / 12; historical earlier 71-key routed draft used 15 / 15 / 14 / 14 / 13
- diode direction: `col2row`
- diode: current canonical `kc2-x3-v2` uses exact Diodes Incorporated `1N4148W-13-F`, bottom-side SOD-123 at each of its 70 positions; the previous X3 main boards used 디바이스마트 상품번호 14592018 `1N4148W`, SOD-123, 총 77개 and are retained through Git history; historical earlier 71-key routed draft used 디바이스마트 상품번호 25 `1N4148`, SOD-27(DO-35), 71개
- `col2row` 기준 diode의 cathode, 즉 표시선 쪽은 row net으로 둔다.
- X3 SOD-123 diode assembly orientation: solder side/B.Cu가 보이게 PCB를 뒤집고 controller tab이 위로 가게 놓으면, 좌우 half 모두 diode의 흰색 cathode band를 왼쪽으로 둔다. KiCad top/front view에서는 pad 1(row net, cathode)이 오른쪽(+X)에 있지만, bottom-side soldering view에서는 좌우가 mirror되어 왼쪽으로 보인다. PCB를 손에서 돌린 경우에는 left/right보다 `pad 1 = row net = cathode band`를 기준으로 맞춘다. 이 문장은 verified 77-key X3용 historical/current-main 조립 기준이다.
- X3 V2 1N4148W assembly orientation: exact Diodes Incorporated `1N4148W-13-F` / DS30086 Rev. 31-2 기준 pin/pad 1은 cathode/row net, pin/pad 2는 anode/per-key switch net이다. B.Cu mirrored assembly drawing에서 cathode band가 pad 1을 향하는지 확인하고, generic `1N4148W` 이름만으로 다른 package/manufacturer 부품을 섞지 않는다.
- active canonical `kc2-x3-v2`는 KC2 소유 enlarged hand-solder land와 exact 70개 배치, 양쪽 canonical `kc2_left.dsn/.ses` 및 `kc2_right.dsn/.ses` 라우팅, fresh DRC, fabrication/mechanical/housing/coupon 산출물을 현재 1N4148W board에 맞춰 재생성·디지털 검증했다. 다만 populated 물리 coupon과 최종 독립/order gate는 여전히 pending이므로 주문할 수 없다.
- 1N4148W 전환은 firmware matrix 논리를 바꾸지 않는다. `col2row`, active-high column, active-high pull-down row, pad 1=row/cathode, pad 2=per-key/anode를 유지하며, 기존 pinned V2 firmware source와 UF2 hash도 그대로 둔다. 기록된 zero-wait scan delay를 물리 coupon 전에 임의 변경하지 않는다.
- V2 발주 전 물리 coupon에서 기존 zero-wait firmware로 3.0 V와 3.3 V 각각의 maximum same-row 및 maximum same-column press/release stress를 실행하여 missing/false/stuck key가 없음을 확인한다. 이 증거는 현재 pending이다.
- historical 또는 future variant에서 SOD-27(DO-35) 배치 공간이 실제로 부족하면 SMD diode로 전환한다.
- Active V2의 exact diode는 Diodes Incorporated `1N4148W-13-F` / SOD-123이다. 다른 제조사 1N4148W, MiniMELF, SOD-323, SOD-523 또는 ES1B/SMA 대체는 footprint·polarity·routing·housing 전체 재검증 없이 허용하지 않는다.
- Historical/future non-V2 SMD 전환 2순위 후보는 `1N4148WS` / `SOD-323`이다. 공간은 더 작지만 수동 납땜 난도가 높으므로 active V2 후보가 아니다. historical/separate M2 layout에서는 M2 hole도 같은 기준으로 본다.

## Left Half Matrix

왼쪽 half는 7 columns x 5 rows다.

| Net | nRF GPIO | Pro Micro/nice!nano pin 의미 |
| --- | --- | --- |
| L_COL0 | `gpio0 20` | D3 |
| L_COL1 | `gpio0 24` | D5 |
| L_COL2 | `gpio0 22` | D4/A6 |
| L_COL3 | `gpio1 0` | D6/A7 |
| L_COL4 | `gpio0 11` | D7 |
| L_COL5 | `gpio1 4` | D8/A8 |
| L_COL6 | `gpio1 6` | D9/A9 |
| L_ROW0 | `gpio0 9` | D10/A10 |
| L_ROW1 | `gpio0 10` | D16 |
| L_ROW2 | `gpio1 11` | D14 |
| L_ROW3 | `gpio1 13` | D15 |
| L_ROW4 | `gpio1 15` | D18/A0 |

## Right Half Matrix

오른쪽 half는 9 columns x 5 rows다. 오른쪽 local column 0..8은 global column 7..15에 대응한다.

| Net | Global col | nRF GPIO | Pro Micro/nice!nano pin 의미 |
| --- | --- | --- | --- |
| R_COL0 | G_COL7 | `gpio1 6` | D9/A9 |
| R_COL1 | G_COL8 | `gpio0 9` | D10/A10 |
| R_COL2 | G_COL9 | `gpio0 10` | D16 |
| R_COL3 | G_COL10 | `gpio1 11` | D14 |
| R_COL4 | G_COL11 | `gpio1 13` | D15 |
| R_COL5 | G_COL12 | `gpio1 15` | D18/A0 |
| R_COL6 | G_COL13 | `gpio0 2` | D19/A1 |
| R_COL7 | G_COL14 | `gpio0 31` | D21/A3 |
| R_COL8 | G_COL15 | `gpio0 29` | D20/A2 |
| R_ROW0 | - | `gpio0 20` | D3 |
| R_ROW1 | - | `gpio0 22` | D4/A6 |
| R_ROW2 | - | `gpio0 24` | D5 |
| R_ROW3 | - | `gpio0 17` | D2 |
| R_ROW4 | - | `gpio0 11` | D7 |

주의:

- 오른쪽 `R_COL7`과 `R_COL8`은 초기 draft의 D20/D21 배정에서 서로 교환했다.
- `R_COL7`은 `DEL`, `\`, `PgUp`, `PgDn`, `Right`가 포함된 긴 column이므로 controller 바깥쪽에 더 가까운 D21/A3에 배정한다.
- `R_COL8`은 `Home` 1키 column이므로 D20/A2에 배정한다.
- ZMK matrix pin 설정은 이 표를 기준으로 맞춘다.

## 전원 및 컨트롤러

- nice!nano v2를 Pro Micro 호환 24핀 socket으로 장착한다.
- socket은 디바이스마트 상품번호 5494 `싱글라운드소켓(64핀)`을 잘라 좌우 1x12 socket 2줄로 사용한다.
- nice!nano의 `B+`/`B-` top pins에는 socket/header를 설치하지 않는다.
- 각 half에 301230-class 3.7 V, 100 mAh Li-Po 배터리 1개를 둔다.
- Nominal battery body는 30.0 mm x 12.0 mm x 3.0 mm이며, 30 mm 축을 U1 pin row와 평행하게 두고 USB 쪽으로 1.0 mm 치우친다. Left center는 `(131.7125, 50.7500)`, right center는 `(78.4000, 50.7500)` mm이다.
- 15.24 mm socket-row center와 1.80 mm pad 기준으로 battery-to-pad nominal clearance는 각 0.72 mm, battery-to-antenna-keepout plan clearance는 3.97 mm이다.
- 사용자가 육안으로 추정한 약 8 mm stack은 fit 증거가 아니다. 완전히 체결한 carrier-to-controller 간격, pack/절연/retainer 최대 두께, pouch 팽창과 pin 돌출을 caliper와 first article로 확인한다.
- 배터리에는 이미 부착된 절연 lead만 사용한다. Bare pouch tab 또는 pouch seal에 납땜하지 않는다.
- 배터리 lead는 carrier의 `J_BAT1` BAT+/B- PTH에 직접 납땜하고 `BAT_LEAD_SLOT1` copper-free slot으로 strain relief한다. Board에는 exact text `BAT STRAIN RELIEF`를 표시한다. A2501, A1251, JST 등의 detachable board connector는 사용하지 않는다.
- `J_BAT1 BAT+ -> SW_PWR1 pad 1 common -> pad 2 ON throw -> U1 RAW/NN_B+`로 연결한다. SW_PWR1 pad 3은 NC이고 B-는 local GND 및 U1 GND에 직접 연결한다.
- 각 half의 전원은 독립적이며 좌우 배터리 전원을 교차 연결하지 않는다.
- 각 half에 IMMS-12V power switch 1개를 둔다. Center는 left `(115.8125, 63.4500)`, right `(94.3000, 63.4500)` mm이고 rotation은 left 0도, right 180도이다. 안쪽 이동은 ON, USB 바깥쪽 이동은 OFF로 표시한다.
- 각 half에 `NW3-A06-B3` reset switch 1개를 둔다. Center는 left `(126.0625, 63.4500)`, right `(84.0500, 63.4500)` mm이고 rotation은 left 0도, right 180도이다. POWER와 RESET의 center spacing은 10.25 mm이며, controlled body 기준 간격은 2.20 mm이다.
- Top/component-side view의 절대 좌→우 순서는 left `PWR|RST`, right `RST|PWR`이다. 각 half의 사용자 관점에서는 USB 바깥쪽부터 POWER, RESET, antenna 순서가 같다.
- Socketed nice!nano는 battery가 carrier에 납땜된 상태에서도 분리할 수 있어야 한다.
- Lower housing에는 TW301525 또는 301230 battery-body cavity를 만들지 않는다. U1/J_BAT1/strain-relief/IMMS lead와 solder fillet에 필요한 하부 opening만 둔다.
- 정확한 battery MPN과 single-cell protection 상태는 BOM과 component-by-component 조달 검토에 명시하며 size code만으로 보호회로를 추정하지 않는다.
- 각 half에 프로그래밍용 tact switch 1개를 둔다.
- tact switch는 디바이스마트 상품번호 1322056 `NW3-A06-B3`를 사용한다.
- `NW3-A06-B3`는 SMD 부품이며, X3 V2에서는 `CON-ARCH-007`의 controller-key-gap RESET 위치와 10.25 mm POWER center spacing을 따른다.
- 프로그래밍용 tact switch는 `RST`와 `GND` 사이에 연결하여 nice!nano bootloader/reset 진입에 사용한다.
- `kc2-x3-v2` carrier는 `CON-ARCH-007`의 J_BAT1, IMMS-12V, RAW/GND 전원 경로를 사용한다. 배터리 극성, IMMS common/throw, RAW/GND continuity는 조립 전후 multimeter로 확인한다.

## PCB 설계 제약

- variant별 SRS requirement가 지원 switch family와 assembly mode를 좁혀 정의할 수 있다.
- 일반 KC2 switch footprint는 다중 호환 hole/pad pattern을 목표로 하되, `kc2-x3-v2`는 `CON-ARCH-004`에 따라 Choc V2 socket-only 및 MX solder-only로 제한한다.
- 하나의 PCB에서 가능한 한 여러 switch family를 납땜할 수 있게 하는 목표는 SRS가 더 좁은 variant별 assembly mode를 지정하지 않은 경우에만 적용한다.
- 단일 hole pattern이 모든 제조사/모든 switch를 물리적으로 지원할 수는 없으므로, KiCad footprint 작성 전에 지원하려는 switch family별 pin pitch, metal pin, center/locator hole, keycap 간섭 치수를 라이브러리와 실물로 검증한다.
- `무보강판 스테빌라이저` 섹션은 stabilizer가 필요한 별도 layout에만 적용한다. Historical X3 no-stabilizer layout 및 현재 정본 `kc2-x3-v2`는 stabilizer footprint와 keepout을 생성하지 않는다.
- 보강판에 의존하는 plate-mounted stabilizer는 KC2 기본 구조와 맞지 않으므로 final footprint로 사용하지 않는다.
- 현 draft의 MX-style `KC2:PCB_Mount_2u_Stabilizer_NPTH`는 위치/공간 확인용 placeholder이며, low-profile 무보강판 실물 체결 검증 전에는 fabrication footprint로 사용하지 않는다.
- 현재 정본 `kc2-x3-v2`는 `CON-ARCH-004`의 70개 switch/diode 배치를 기준으로 검증한다. 이전 X3 77개 배치와 그보다 앞선 71-key routed draft의 diode 공간 검토는 historical baseline으로만 유지한다.
- Historical 또는 future variant에서 DO-35 axial diode를 검토할 경우, through-hole axial 부품은 SMD diode보다 차지하는 면적과 lead bending 공간이 크다.
- DO-35 유지 실패 기준은 switch footprint 또는 stabilizer가 필요한 별도 layout의 stabilizer footprint와의 courtyard overlap, screwless registration hole 배치 실패, historical/separate M2 layout의 M2 hole 배치 실패, hole-to-hole clearance 위반, 결합 edge 2.5-3.0 mm 여백 침범, 하부 바닥판 지지점 간섭, lead bending 공간 부족 중 하나라도 발생하는 경우로 둔다.
- 공간이 부족하면 diode 위치 재배치, PCB 반대면 배치, routing 재배치를 먼저 검토한다. Active V2는 exact `1N4148W-13-F` SOD-123 requirement와 concealed-bezel/housing land를 함께 만족해야 하며 작은 SOD-323/SOD-523 또는 큰 SMA 패키지로 임의 변경하지 않는다.
- diode는 keycap, switch/socket solder joint, Choc socket body/pad/solder fillet, MX switch pin/solder joint, controller socket, battery, screwless registration hole, 하부 바닥판 지지점과 간섭하지 않아야 한다. historical/separate M2 layout에서는 M2 고정 홀 간섭도 금지한다.
- 기존 `-hotswap` draft 산출물은 V2 요구사항이 아니며, `kc2-x3-v2`의 switch footprint 기준으로 사용하지 않는다.
- 기존 `-hotswap` draft 산출물은 `key-switches.pretty:SW_Kailh_Choc_V1V2_HotSwap_Hybrid`와 Kailh Choc V1/V2 low-profile socket(`CPG135001S30` 계열) 검토 기록을 보존한 것이다.
- `kc2-x3-v2`의 Choc V2 socket-only/MX solder-only footprint는 `CON-ARCH-004`를 따른다. V2에는 Choc V1/PG1350 switch geometry, Choc V1 전용 locator/direct-solder geometry, Choc V2 direct-solder pad, MX hot-swap socket pad를 포함하지 않는다.
- Choc V2 hot-swap socket은 bottom-side SMD pad를 갖는 부품이므로 공식 Choc V2 switch/socket 및 5-pin MX switch 도면/데이터시트 기준으로 PCB 하부면 socket soldering 방향, MX top-side direct-solder 방향, left/right 회전 또는 mirror 배치, socket orientation, Choc V2 center/switch-pin/locator NPTH clearance, MX center/electrical-pin/locator hole clearance를 검토한다. 1:1 출력물과 실물 소켓 확인은 사전 sanity check로만 사용하며, V2 발주 가능 증거로는 인정하지 않는다.
- 무보강판 no-stabilizer 구조에서는 Choc V2 hot-swap socket만으로 switch/keycap 흔들림과 이탈을 충분히 억제하지 못할 수 있다. 하부 바닥판, keycap, Choc V2 socket body/pad/solder fillet, MX switch pin/solder joint, nearby diode body/lead/pad 간섭과 target Choc V2 switch/socket 및 target 5-pin MX switch의 실물 fit은 intended footprint, stackup, drill, mask, paste data로 제작된 1:1 physical test coupon 또는 first-article PCB section에서 실제 부품을 장착/납땜해 검증한 뒤에만 V2를 발주 가능 상태로 본다. CAD-only render, paper check, unsoldered visual inspection은 이 gate의 충분한 증거가 아니다. stabilizer가 필요한 별도 layout에서는 stabilizer 간섭도 별도로 검증한다.
- 아래 `x1`/`x2` 항목은 historical draft variant 기록이며, 현재 정본 `kc2-x3-v2` 요구사항으로 사용하지 않는다.
- `x1` 변형은 `hotswap` 변형을 복사한 hand-solder diode 개선판이다.
- `x1` 변형의 diode는 디바이스마트 상품번호 14592018 `1N4148W`, SOD-123을 사용한다.
- `x1` 변형의 diode footprint는 `kc2.pretty:D_SOD123_HandSolder_14592018`이며, KiCad 기본 `D_SOD-123`의 `0.9 mm x 1.2 mm` pad보다 큰 `1.4 mm x 1.55 mm` pad를 사용한다.
- `x1` 오른쪽 half는 enlarged diode pad를 쓴 autoroute의 board-edge clearance를 확보하기 위해 상단 outline에 0.3 mm relief를 둔다.
- `x2` 변형은 `x1`을 복사한 뒤 switch footprint를 `key-switches.pretty:SW_Kailh_Choc_V1_HotSwap_THT`로 바꾼다.
- `x2` 변형은 Kailh Choc V1/PG1350 기준으로 hot-swap socket pad와 through-hole 직접 납땜 pad를 모두 제공한다.
- `x2` 변형은 `x1`의 Choc V1/V2 hot-swap-only footprint를 유지하지 않는다. Choc V2까지 포함하는 socket+THT 통합 footprint는 현재 채택하지 않는다.
- `x2` 변형은 추가된 switch THT pad와 diode 간섭을 피하기 위해 diode y offset을 switch center 기준 `-7.6 mm`로 둔다.
- `x2` 오른쪽 half는 `x1`과 같은 상단 outline 0.3 mm relief를 유지한다.
- 이전 main PCB는 기존 `x3` 변형을 승격한 no-stabilizer layout 개선판이며 Git 이력으로 보존한다. 현재 main PCB는 `OPS-ARCH-006`이 승격한 `kc2-x3-v2`이다.
- `x3` 변형은 switch footprint, diode footprint, diode y offset을 `x2`와 동일하게 유지하되, preflight copper-edge clearance를 위해 상단 outline relief는 왼쪽 half 0.3 mm, 오른쪽 half 0.6 mm를 사용한다.
- `x3` 변형은 `docs/spec/20.kc2-no-stabilizer-layout.md`의 77-key layout을 사용하며, 물리 키 최대 폭은 `1.75u`이다.
- SpecKiwi SRS source of truth: `docs/spec/10.product-architecture.srs.md`의 `CON-ARCH-004`가 `kc2-x3-v2` switch-footprint requirement를 정의한다. 요약: 디지털 구현/검증은 통과했지만 물리 검증은 남은 현재 정본 V2 board이며, Choc V2/PG1353-family low-profile switch는 bottom-side Choc hot-swap socket으로만 지원하고 Cherry MX-style switch는 5-pin PCB-mount through-hole direct-solder로만 지원한다. 정확한 Kailh manufacturer MPN과 controlled drawing revision은 아직 조달 gate이며 `Deep Sea Whale` 같은 판매명만으로 부품을 확정하지 않는다. Historical X3 증거나 물리 coupon 실장 증거 없는 V2는 주문 가능 상태가 아니다.
- `kc2-x3-v2` 변형은 Choc V1/PG1350 switch, Choc V1 전용 locator/direct-solder geometry, Choc V2 direct-solder pad, MX hot-swap socket pad를 지원하지 않는다.
- `OPS-ARCH-006`에 따라 `kc2-x3-v2` 산출물은 `hardware/kicad/kc2_left/`, `hardware/kicad/kc2_right/`, `hardware/kicad/fabrication/kc2_left_jlcpcb.zip`, `hardware/kicad/fabrication/kc2_right_jlcpcb.zip` 정본을 대체한다. 활성 V2의 draft 중복본은 두지 않으며 이전 정본은 Git 이력으로 보존한다. 이 경로 승격은 물리 검증이나 주문 승인을 의미하지 않는다.
- active V2의 현재 M1.4-hole-aware compact-controller route input/session은 `kc2_left.dsn/.ses` 및 `kc2_right.dsn/.ses`이다. Exact service geometry, diode lands, P3 clamps와 precondition-checked detour를 적용해 좌 616 / 우 803 route items를 재현한다. 이전 `70-es1b-controller-r3`, `70-es1b-mh-r2`, `70-es1b-r1`, left `70-v5-r1`, right `71-r12`는 historical evidence이며 active V2 재현에 사용하지 않는다.
- Historical `x3`와 현재 정본 `kc2-x3-v2`는 모두 `2u 이상` 키가 없으므로 stabilizer footprint를 생성하지 않는다.
- `x3` 오른쪽 half는 5개 row 모두 9개 matrix column을 사용한다. 기존 `R_COL8=D20`, `R_COL7=D21` pin mapping은 유지하되, firmware keymap에서는 duplicate legend physical key를 별도 위치로 구분해야 한다.
- `x3` outline은 증가한 matrix 밀도 때문에 양쪽 half의 inner edge에 `0.8 mm` routing relief를 추가한다.
- `x3` joined mechanical reference는 오른쪽 `Y`/`H` 돌출부를 왼쪽 `T`/`G` 홈으로 넣은 interlocked 배치에서 Edge.Cuts 간 최소 `1.0 mm` clearance를 유지한다. 오른쪽 `Y`/`H` 돌출부는 세로 inner Edge.Cuts 면을 `3.6 mm` margin으로 유지하고 가로 ledge만 `0.8 mm` 안쪽 relief 처리하되, 전기적 copper-to-edge clearance는 fabrication gate 기준을 계속 만족해야 한다.
- 상부 하우징이 없으므로 PCB outline은 손에 노출되는 최종 상부 외형이다.
- PCB 모서리는 라운드 처리한다.
- nice!nano는 각 half의 숫자열 바로 위에 가로 배치한다.
- controller는 키 배열 위쪽의 둥근 돌출 탭 안에 배치한다.
- controller 돌출 탭은 X 좌표상 결합 edge에 가까운 끝쪽으로 붙인다. 왼쪽 half에서는 오른쪽 끝, 오른쪽 half에서는 왼쪽 끝이 기준이다.
- 단, controller 돌출 탭은 결합 edge 최외곽까지 튀어나오면 안 된다. 결합/분리 시 탭이 먼저 닿지 않도록 왼쪽 half는 약 12 mm, 오른쪽 half는 약 17 mm 안쪽으로 recessed 처리한다.
- X3 compact controller tab은 기존 72.0 mm controller 탭보다 작게 줄이고, nominal 탭 폭은 54.0 mm 이하를 목표로 한다.
- X3 compact controller tab은 좌우 대칭 사각 탭이 아니라 USB-C/reset switch 쪽은 타이트하게, antenna keepout 쪽은 10 mm no-copper keepout을 포함하도록 비대칭으로 잡을 수 있다.
- 좌우 half를 붙였을 때 nice!nano의 USB-C 포트는 서로 반대쪽, 즉 바깥쪽을 바라보게 한다.
- 왼쪽 keyboard의 USB-C 포트는 왼쪽 바깥쪽을 향하게 한다.
- 오른쪽 keyboard의 USB-C 포트는 오른쪽 바깥쪽을 향하게 한다.
- 좌우 모두 nice!nano component side가 위를 향하는 top-side socket 배치로 두고, 단순 mirror가 아니라 회전 방향만 다르게 잡는다.
- 왼쪽 half는 USB-C가 왼쪽 바깥쪽을 향하고, antenna end는 오른쪽 결합 edge 쪽을 향한다.
- 오른쪽 half는 USB-C가 오른쪽 바깥쪽을 향하고, antenna end는 왼쪽 결합 edge 쪽을 향한다.
- KiCad 배치에는 `USB_OUT_LEFT`, `USB_OUT_RIGHT`, `ANTENNA_INWARD` silkscreen 또는 Dwgs.User 표시를 넣어 footprint 회전 오류를 검증한다.
- USB-C 포트 아래쪽은 각 half의 key-side, 즉 숫자열을 향한 쪽으로 정의한다. Promoted/historical X3의 프로그래밍용 tact switch는 antenna-side controller-tab edge 쪽 상면에 둔다. X3 V2에서는 `CON-ARCH-007`에 따라 controller-key gap에 mirrored POWER/RESET pair를 둔다.
- 핸드와이어링 버전의 배열은 유지하되, PCB outline과 controller/USB 주변 외형은 PCB화에 맞춰 조정할 수 있다.
- USB는 nice!nano v2 자체 USB-C만 사용한다. 기존 USB-C guide/extension/외부 USB board 구조는 유지하지 않는다.
- USB-C 포트는 결합 상태와 분리 상태 모두에서 케이블을 꽂기 쉬운 방향으로 둔다.
- nice!nano의 USB-C 반대쪽 끝을 antenna end로 정의한다. KC2에서는 USB-C를 바깥쪽으로 향하게 하므로 antenna end는 좌우 결합 edge 쪽을 향한다.
- antenna end에서 최소 10 mm 길이, nice!nano 폭 전체, 그리고 인접 결합 edge 방향에는 copper pour, trace, via, battery, wire strain relief, screwless registration hole(`REG_NPTH_3.0`) 또는 하부 바닥판 peg, 금속 insert, 금속 보강물을 두지 않는다. historical/separate M2 layout에서는 M2 screw도 두지 않는다.
- 이 keepout 값은 공식 pinout/schematic과 실물 측정 후 조정할 수 있으나, 1차 PCB 초안에서는 10 mm keepout을 기본값으로 둔다.
- 배터리를 controller 아래에 둘 수는 있지만, 안테나 바로 아래에는 두지 않는다.
- Li-Po pouch와 배선은 2.4 GHz 안테나를 detune하거나 감쇠시킬 수 있으므로, 배터리는 MCU/USB 쪽 아래로 치우치게 배치하고 안테나 아래는 비워 둔다.
- Promoted/historical X3의 tact switch는 antenna-side controller-tab 기록을 유지한다. X3 V2의 POWER/RESET pair는 antenna keepout 반대쪽 controller-key gap에 mirror 배치하고, 배터리·keycap·하우징·controller 탈착과 간섭하지 않게 한다.
- Controller, battery, POWER/RESET 및 direct-solder lead는 `CON-ARCH-007`과 `REL-ARCH-001`의 3D keepout, strain-relief, RSSI/PER, charging-state 및 power-transition gate를 적용한다.
- keycap 간섭, USB 삽입 간섭, 바닥면 쇼트 가능성을 1:1 출력물로 확인한다.

## 미확정 항목

- CON-ARCH-004로 좁혀지지 않은 future variant용 다중 호환 switch hole/pad pattern 검증. 현재 정본 `kc2-x3-v2`는 CON-ARCH-004의 Choc V2 socket-only/MX solder-only 제한을 따르며 이전 X3 footprint는 historical evidence이다.
- `kc2-x3-v2` 물리 coupon에 조달 전에 확정한 exact Kailh low-profile Choc V2/PG1353-family MPN·drawing revision과 `CPG135001S30` socket을 하단 0/180도 양방향으로 실장하고, 5-pin MX switch를 상면 직납하여 실제 fit, keycap pitch, diode, solder joint, 하우징 간섭을 확인해야 한다.
- Active V2는 exact Diodes Incorporated `1N4148W-13-F` SOD-123 hand-solder requirement를 따른다. 다른 패키지 전환은 새 SRS 변경과 전체 검증을 요구한다.
- stabilizer가 필요한 별도 layout의 keycap unit, 실제 keycap underside stem 간격, 무보강판에서 체결 가능한 PCB-mounted/PCB-retained stabilizer footprint
- stabilizer가 필요한 별도 layout의 stabilizer 1:1 출력물 또는 test coupon 기반 실물 끼움 테스트
- 정확한 301230-class 제조사/MPN, single-cell protection 상태, 최대 팽창 두께, lead 인출 방향과 rated pull 조건
- Fully seated controller stack의 caliper 간격과 battery/절연/retainer first-article fit
- J_BAT1 drill, strain-relief 및 service pull 조건의 purchased-lead drawing 기반 확정
- 최종 좌우 first article의 battery-only/USB charging/charge-complete RSSI, packet loss, disconnect 및 IMMS power-transition 측정
- `hardware/kicad/kc2_physical_evidence.json`의 네 evidence bundle이 exact source와 raw measurement artifact 경로·SHA-256·크기·측정일·장비/교정 정보 및 SRS 임계값을 모두 통과해야 한다. 생성형 PCB/하우징 JSON의 `passed`/`order_ready` 문자열만 바꾸는 것은 주문 증거가 아니다.
- Promoted/historical X3의 `NW3-A06-B3` antenna-side 상면 위치 검증; X3 V2는 `CON-ARCH-007`의 mirrored controller-key-gap service gate 적용
- X3 screwless rail/capture 하부 바닥판의 실제 레일, 턱, peg, rib 치수
- X3 screwless 구조에서 접착제가 필요한 경우의 보조 적용 위치와 서비스성
- 3D 프린터 하부 바닥판 형상과 PCB 지지점
- 결합 edge 하부를 지지하는 3D 프린터 바닥판 lip/rib 형상과 지지 위치
- 실리콘 feet 위치
- nice!nano 자체 USB-C 접근 방향과 cable clearance
- 기존 `-hotswap` draft 변형의 Kailh Choc socket orientation, solder fillet 공간, socket body와 하부 바닥판 간섭. `kc2-x3-v2`의 Choc V2 socket clearance는 `CON-ARCH-004` 검증 항목으로 별도 다룬다.

## 구매처 링크

| 용도 | 부품 | 구매처 |
| --- | --- | --- |
| Matrix diode | 디바이스마트 상품번호 25 `1N4148`, SOD-27(DO-35), 75V, 450mA | https://www.devicemart.co.kr/goods/view?no=25 |
| Matrix diode alternative 1 | 디바이스마트 상품번호 14592018 `1N4148W`, SOD-123 | https://www.devicemart.co.kr/goods/view?no=14592018 |
| Matrix diode alternative 2 | 디바이스마트 상품번호 15106773 `1N4148WS`, SOD-323 | https://www.devicemart.co.kr/goods/view?no=15106773 |
| Matrix diode (active X3 V2, exact part) | 70 pcs Diodes Incorporated `1N4148W-13-F`, SOD-123 on B.Cu, DS30086 Rev. 31-2; pin 1=row/cathode, pin 2=per-key/anode; bottom view mirrored; KC2 enlarged hand-solder land | https://www.diodes.com/part/view/1N4148W/ |
| Controller socket | 디바이스마트 상품번호 5494 `싱글라운드소켓(64핀)`, 2.54 mm pitch, 1열 round socket | https://www.devicemart.co.kr/goods/view?no=5494 |
| Battery (X3 V2) | 301230-class, 3.7 V, 100 mAh, pre-attached insulated leads; exact protected-pack MPN pending physical gate | https://nicekeyboards.com/docs/nice-nano/ |
| Power switch (X3 V2) | provisional `IMMS-12V` / `BSI-10` nominal collision proxy, 3 x 0.80 mm drill, 2.54 mm pitch; exact manufacturer/MPN/drawing or incoming equivalence inspection pending | https://www.devicemart.co.kr/goods/view?no=2647 |
| Programming tact switch | 디바이스마트 상품번호 1322056 `NW3-A06-B3`, SMD micro tact switch, 6.1 mm x 3.7 mm급 body, 2.55 mm급 높이 | https://www.devicemart.co.kr/goods/view?no=1322056 |
| KC2 X3 V2 target switch | Kailh low-profile Choc V2 / PG1353-family, 70개. Exact manufacturer MPN and controlled drawing revision pending; bottom-side socket assembly only. | https://www.kailhswitch.com/mechanical-keyboard-switches/key-switches/kailh-low-profile-switch-choc-v2.html |
| KC2 X3 V2 socket | Kailh Choc hot-swap socket `CPG135001S30` class, 70개 when using Choc V2 mode. Do not populate in MX mode. | https://www.kailhswitch.com/uploads/15927/files/CPG135001S30.pdf?rnd=925 |
| KC2 X3 V2 MX alternative | Cherry MX-style 5-pin PCB-mount switches, 70개 when using MX direct-solder mode. Do not populate Choc sockets at the same positions. | https://www.cherry.de/fileadmin/media/Industrial/Switch/MX_BLACK/Data_sheet_MX2A_Black.pdf |
| Historical draft hot-swap socket variant | Kailh Choc/PG1350 low-profile hot-swap socket, `CPG135001S30` 계열. 기존 `-hotswap` draft 변형 기록으로만 유지하며 `kc2-x3-v2` 기준 부품이 아니다. | https://ko.aliexpress.com/item/1005009187521124.html |

Historical draft hot-swap 참고 자료:

- AliExpress mirror 조사: Kailh low-profile 1350 Chocolate switch용 hot-swap socket으로 표시됨. https://alitools.io/en/showcase/kailh-hot-swap-socket-for-low-profile-1350-chocolate-switches-on-mechanical-keyboard-pcb-socket-diy-base-modification-33023283633
- Kailh Choc hot-swap socket part number/source: `CPG135001S30`. https://www.flux.ai/whitelynx/kailh-choc-hot-swap-socket
- Kailh `CPG135001S30` datasheet mirror. https://jonathan.rico.live/projects/split-keyboard/files/kailh-choc-sockets.pdf
- Historical draft reference: `key-switches.pretty` compatibility table의 `SW_Kailh_Choc_V1V2_HotSwap_Hybrid`는 Choc V1 조건부, Choc V2 compatible, Hot-Swap footprint로 분류됨. 이 footprint는 기존 `-hotswap` draft 기록으로만 유지하며 `kc2-x3-v2` 기준 footprint가 아니다. https://github.com/siderakb/key-switches.pretty
- Kailh-style hot-swap socket은 일반 switch footprint가 아니라 별도 footprint와 socket 방향 검증이 필요함. https://docs.keeb.supply/basics/soldering/hotswap/

## 폐기된 부품 후보

| 용도 | 부품 | 상태 | 링크 |
| --- | --- | --- | --- |
| Battery/controller harness | 디바이스마트 상품번호 10894399 `NW3-5264-02`, 2핀, 2.5 mm pitch, 약 200 mm, AWG26, A2506 한쪽 커넥터 | KC2 X3 V2에서는 사용하지 않음. Pre-attached insulated battery lead를 J_BAT1에 직접 납땜 | https://www.devicemart.co.kr/goods/view?no=10894399 |
| PCB power connector | `NW3-A2501-02AB`, `NW3/YTC-A2501-02AW`, `NW-5268-2AW` 및 mating A2501/A2506 housing | KC2 X3 V2에서는 사용하지 않음. Carrier에는 direct-solder J_BAT1만 둠 | https://www.devicemart.co.kr/goods/view?no=1322955 |
| Programming tact switch | 디바이스마트 상품번호 34555 `ITS-1105-5mm`, DIP tact switch, 높이 5.0 mm | USB-C 아래 공간이 커서 `NW3-A06-B3` SMD tact switch로 대체 | https://www.devicemart.co.kr/goods/view?no=34555 |

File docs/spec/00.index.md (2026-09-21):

# SpecKiwi Project SRS Index

| Field | Value |
|---|---|
| Document Type | srs_index |
| Product | SpecKiwi Project |
| Product Version | 1.0.0 |
| Active Target | kc2-x3-v2 |
| Status | draft |
| Rules | [SRS-MD Authoring Rules v1.0.0](../rule/SRS-MD-Rules-v1.0.0.md) |

## 1. Purpose

KC2 하드웨어 요구사항의 기준 문서와 활성 target 상태를 요약한다.

### Active target: `kc2-x3-v2`

Upper coplanar print-face correction (2026-09-21, CON-ARCH-006 / OPS-ARCH-006): all MX, Choc V1 and Deep Sea upper parts remove the localized Z4.10..4.40 screw-land protrusions and share a Z4.40 minimum datum; closed nonfunctional inner voids are filled while screw bores, above-datum bosses, functional spaces, right A/B clearance, lower housings and ordered PCB/Gerber remain unchanged. See [current print guide](../../hardware/MODELS/PRINT-upper-finish.md), `hardware/MODELS/kc2_upper_finish_manifest.json`, and [evidence](../reports/upper-finish-20260921/README.md). Physical print fit and strength remain pending.

Wall-gap correction (2026-09-21, CON-ARCH-006 / OPS-ARCH-006): see [gap-fix print guide](../../hardware/MODELS/PRINT-wall-gap-fix.md) and [evidence](../reports/wall-gap-fix-20260921/README.md). Publication is complete only when `python -B -m tools.publish_kc2_wall_gap_fix` passes with the new manifest. The prior wrap entry below is baseline history, not verification of gap-corrected outputs. Screw assembly and ordered PCB/Gerber are retained; physical fit and strength remain pending.

Current housing revision (2026-09-20, CON-ARCH-006 / OPS-ARCH-006): continuous lower external sleeve at Z5.60, 1.50 mm above the unchanged 1.60 mm PCB, with 1.20 mm upper overlap. All three upper families and both lower options are revised together. Use [current print guide](../../hardware/MODELS/PRINT-wrap-housings.md), `hardware/MODELS/kc2_wrap_housing_manifest.json`, and [current evidence](../reports/wrap-housings-20260920/README.md). Earlier registered/flat/smooth-central housing entries below are historical, not approval of the new output files. Ordered PCB/Gerber remains unchanged; physical fit and strength remain pending.
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

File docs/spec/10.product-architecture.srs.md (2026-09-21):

# Product Architecture

| Field | Value |
|---|---|
| Document Type | scope_srs |
| Scope | ARCH |
| Scope Name | Product Architecture |

## 1. Scope Overview

Describe the scope.

## 2. Scope Boundaries

### In Scope

- SRS requirements

### Out of Scope

- None

## 3. Assumptions and Constraints

- None

## 4. Requirements

### CON-ARCH-001 — X3 interlocked placement clearance for 3D-printed housing

| Field | Value |
| --- | --- |
| Type | constraint |
| Target | kc2-x3 |
| Status | verified |
| Priority | high |
| Tags | kc2 x3 mechanical housing magnet |
| Risk | high |
| Stability | stable |
| Verification Method | Board-coordinate render and kc2-pcb-preflight regression check. |
| GitHub Issue | - |
| Related Docs | docs/spec.md, docs/spec/20.kc2-no-stabilizer-layout.md |
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

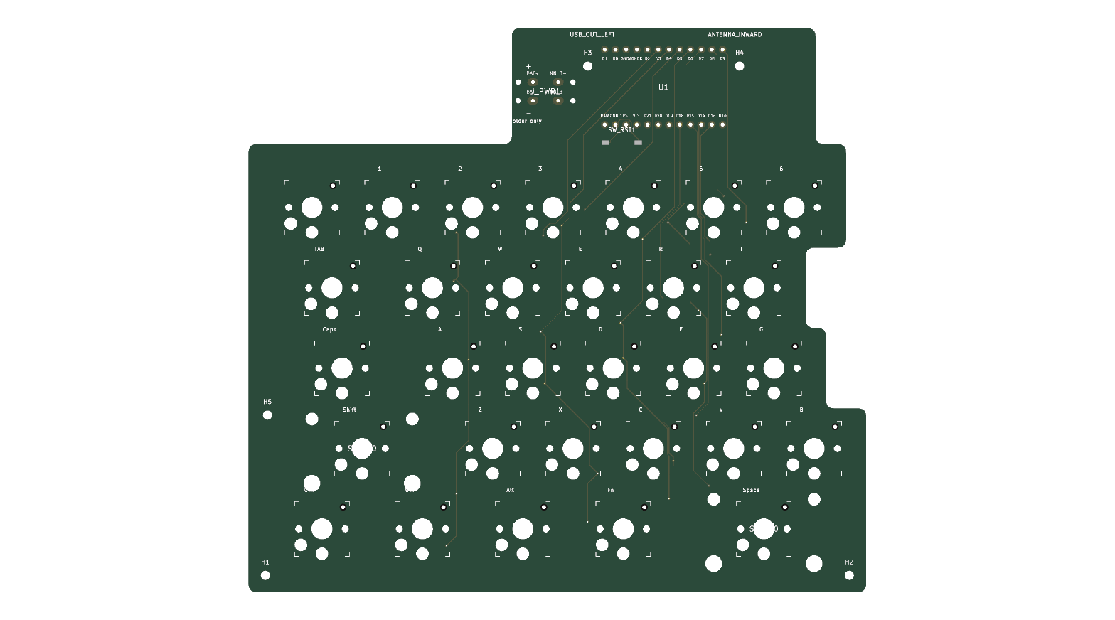
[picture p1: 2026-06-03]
hardware/kicad/draft/x1/renders/kc2_left-x1_top.png

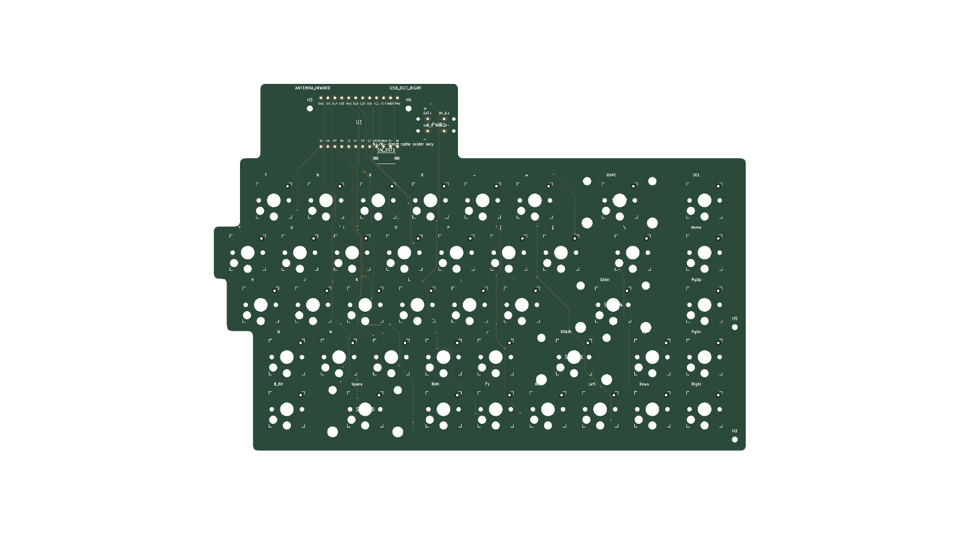
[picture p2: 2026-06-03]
hardware/kicad/draft/x1/renders/kc2_right-x1_top.png

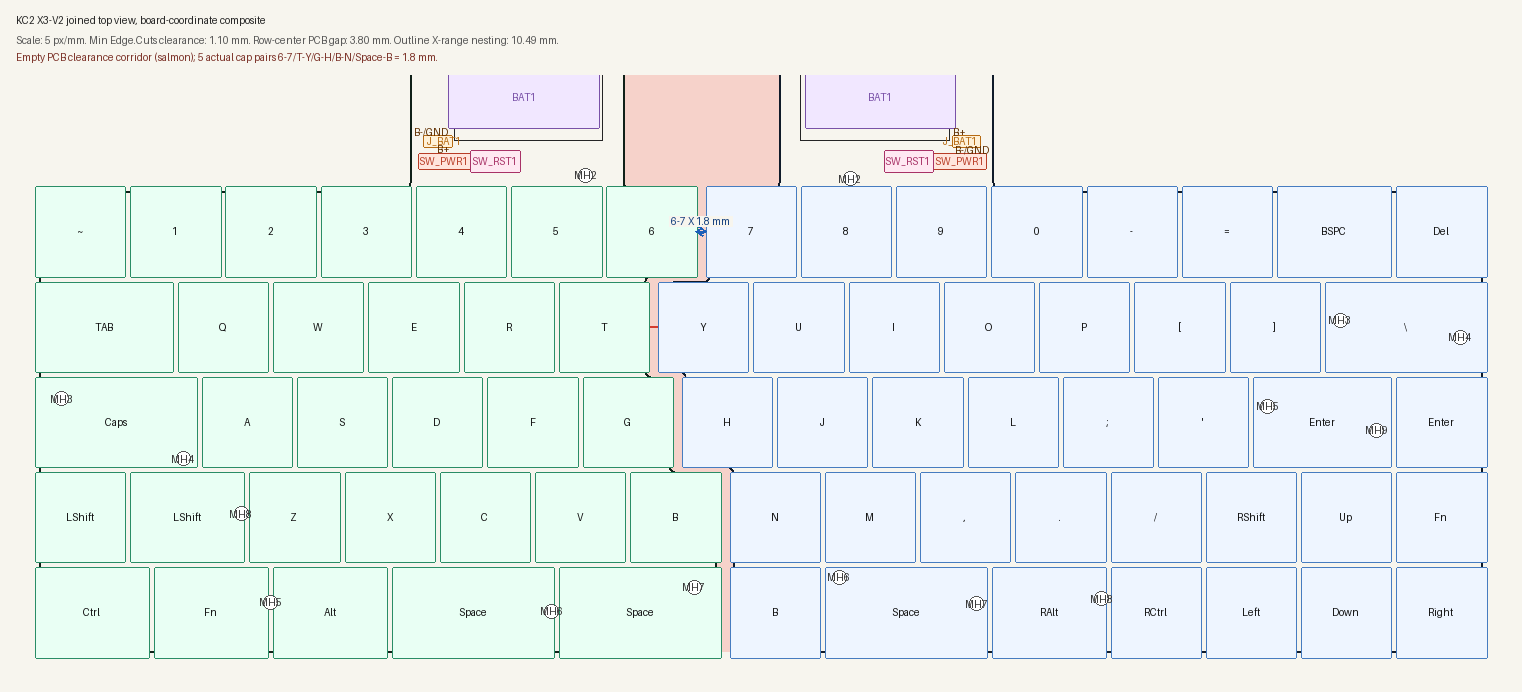
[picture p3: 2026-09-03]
hardware/kicad/renders/kc2_joined_top.png

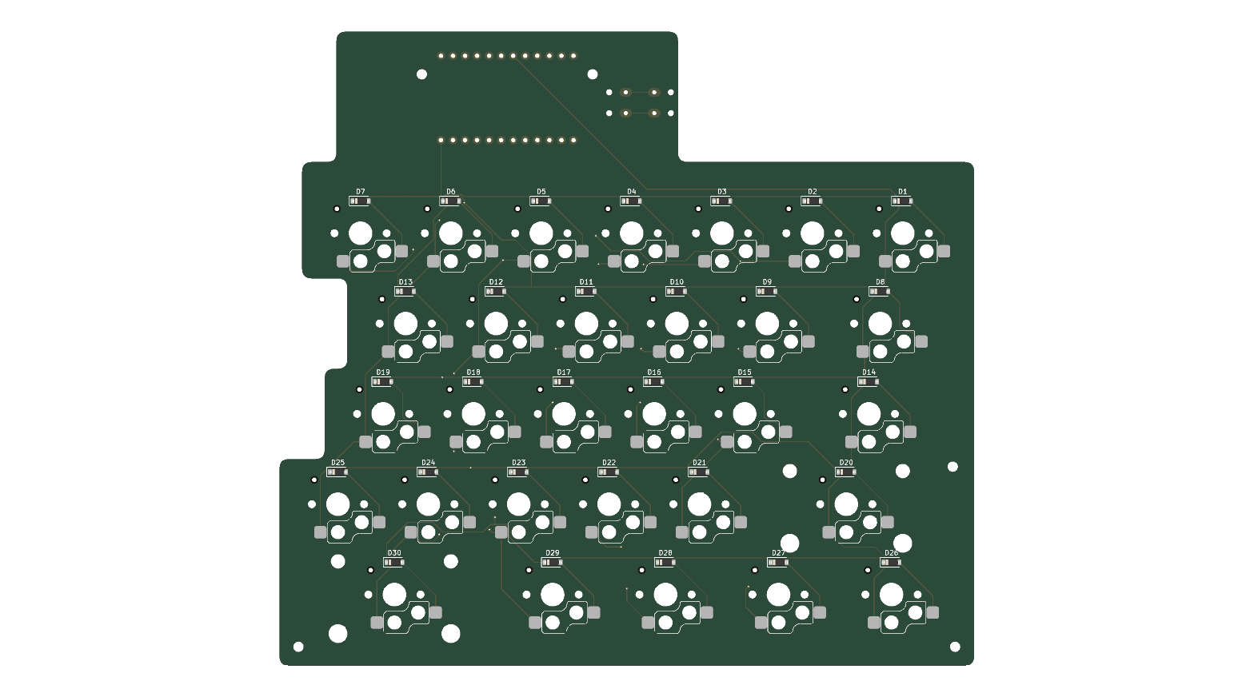
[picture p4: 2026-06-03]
hardware/kicad/draft/hotswap/renders/kc2_left-hotswap_bottom.png

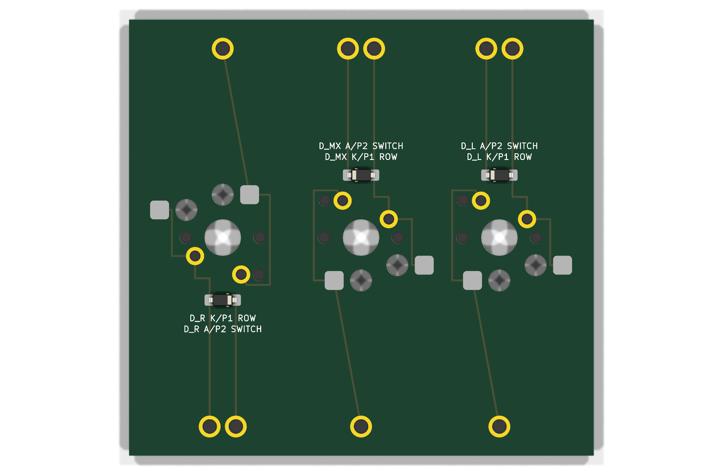
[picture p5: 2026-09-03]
hardware/kicad/renders/kc2_coupon_bottom.png

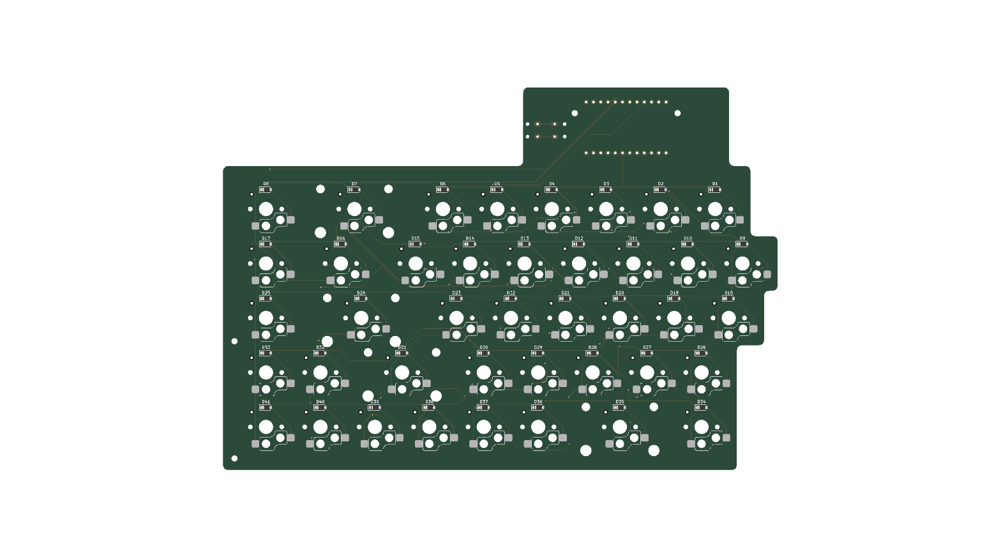
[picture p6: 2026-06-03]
hardware/kicad/draft/hotswap/renders/kc2_right-hotswap_bottom.png

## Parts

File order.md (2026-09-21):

# KC2 디렉토리·PCB 주문·3D 인쇄 안내

> 2026-09-21 상판 공면 개정: MX, Choc V1, Deep Sea 상판의 닫힌 비기능 내부 틈을 메우고, 나사 랜드만 0.30 mm 아래로 내려오던 돌출을 제거하여 모든 상판 STL의 최저면을 `Z=4.40`으로 맞췄습니다. [최신 STL 안내](hardware/MODELS/PRINT-upper-finish.md)와 `python -B -m tools.publish_kc2_upper_finish`를 사용하십시오. 현재 manifest는 `hardware/MODELS/kc2_upper_finish_manifest.json`입니다. 하판과 이미 주문한 PCB/Gerber는 변경하지 않았습니다. 아래 하우징 개정 설명은 이력입니다.

> 2026-09-21 틈 보강 개정: 좌우 외벽과 본체 사이의 불필요한 좁은 틈을 메웁니다. 나사식 조립, PCB 높이와 기능 공간은 유지합니다. [최신 STL 안내](hardware/MODELS/PRINT-wall-gap-fix.md)와 `python -B -m tools.publish_kc2_wall_gap_fix`를 사용하십시오. 검증 통과 전에는 게시 미완료이므로 인쇄를 보류합니다. 파일은 계속 `hardware/MODELS` 바로 아래이며, `STL_FROM_FUSION_20260921` 폴더는 보강 전 비교용입니다. 주문 PCB/Gerber는 그대로입니다. 아래 날짜의 하우징 설명은 이력입니다.

> 2026-09-20 현재 하우징: 하판 외벽이 PCB 윗면보다 1.50 mm 높아 상판 아래쪽을 감쌉니다. [현재 STL 선택 및 인쇄 안내](hardware/MODELS/PRINT-wrap-housings.md)를 따르십시오. 상판과 하판을 함께 새 버전으로 인쇄합니다. 파일은 `hardware/MODELS` 바로 아래, 현재 manifest는 `kc2_wrap_housing_manifest.json`입니다. 이미 주문한 r4 PCB/Gerber는 변경하지 않았습니다. 아래 하우징 개정 설명은 이전 이력입니다.

> 2026-09-14 현재 하우징: 인쇄 파일은 `hardware/MODELS` 바로 아래에 있습니다. 중앙 좌우 요철을 모두 제거한 최신 하판은 [hardware/MODELS/README.md](hardware/MODELS/README.md)와 [PRINT-flat-central-housings.md](hardware/MODELS/PRINT-flat-central-housings.md)를 따르십시오. 자석형은 기존 두 쌍만 유지하며, 컨트롤러 쪽 세 번째 홈은 안전 여유가 없어 추가하지 않았습니다. 현재 검증 manifest는 `hardware/MODELS/kc2_flat_central_housing_manifest.json`입니다. 아래의 과거 `hardware/case` 경로 설명은 이력으로만 보십시오.

기준일: 2026-09-07. 요구사항 원본은 [SRS](docs/spec/00.index.md)입니다.
이 문서는 `OPS-ARCH-006/007`, `CON-ARCH-004/006`의 파일 위치와 절차를 설명하며 요구사항을 대체하지 않습니다.

> 바닥 일체형 r4의 디지털 설계·출력 검증을 완료했습니다. 아래 r4 패키지와 현재 STL을 사용하세요.
> 주문·결제는 실행하지 않습니다. 실물 접점·출력물 강도·배터리·무선 합격은 별도입니다.

## 1. 현재 디렉토리 구조

주요 디렉토리와 용도입니다. 개별 자동 백업과 전체 테스트 파일은 생략했습니다.

```text
kc2/
├─ order.md                         ← 주문·인쇄 파일 선택 안내
├─ README.md                        ← 프로젝트 진입점
├─ AGENTS.md                        ← SRS·하드웨어 검증 작업 규칙
├─ .gitattributes                   ← 검증 자료의 Git 원본 바이트 보존
├─ .gitignore                       ← 임시·백업·로컬 출력 제외
├─ requirements-cad.txt             ← CAD 도구 의존성
├─ docs/
│  ├─ spec/                         ← 유일한 요구사항 원본·검증 근거 연결
│  ├─ rule/                         ← SRS 작성 규칙
│  ├─ analysis/                     ← 요구사항별 분석·변경 이력
│  ├─ research/                     ← 부품 도면·제조 공차 조사
│  ├─ reports/                      ← DRC/회로/CAD/테스트/출력 검토 결과
│  └─ momory/                       ← 기존 기록(현재 이름 그대로)
├─ hardware/
│  ├─ case/                         ← 현재 하우징 STEP/STL/F3D·검증 manifest
│  │  ├─ adapters/                  ← V1/MX 중앙 링 STL
│  │  └─ 백업/                      ← 기존 보관 자료; 현재 인쇄 원본 아님
│  └─ kicad/
│     ├─ kc2_left/                  ← 정식 왼쪽 PCB 프로젝트
│     ├─ kc2_right/                 ← 정식 오른쪽 PCB 프로젝트
│     ├─ autoroute/                 ← 배선 데이터·현재 replay snapshot
│     ├─ first_order/               ← 버전별 봉인 제조 ZIP
│     │  ├─ solid-floor-20260907-r4/ ← 현재: 바닥 일체형 개정용 패키지
│     │  ├─ v1-recess-20260906-r3/   ← 이전 매립 나사/개방 하판 이력
│     │  ├─ mx-receptacle-20260906-r2/
│     │  └─ mx-receptacle-20260906/  ← 이전 검토 이력
│     ├─ fabrication_review/        ← 실제 거버·드릴 원본과 시각 검토 그림
│     ├─ fabrication/               ← 이전 기본 제조 출력; 현재 주문에 사용 금지
│     ├─ mechanical/                ← 이전 기계 출력; 최신 1:1은 case/ 참조
│     ├─ renders/                   ← 배치·조립 렌더
│     ├─ coupon/                    ← 시험용 PCB; 제품 대신 주문하지 않음
│     ├─ draft/                     ← 비활성 과거 설계·로컬 편집 잔여물
│     ├─ kc2_left-hotswap/           ← 과거 설계
│     └─ backups/, autoroute_*/     ← 로컬 백업·실험 출력
├─ firmware/
│  ├─ kc2_zmk/                      ← ZMK 실드·키맵·설정
│  ├─ out/                          ← 검증에 연결된 좌우 UF2
│  └─ build/                        ← 로컬 빌드 캐시; 커밋 대상 아님
├─ third_party/
│  ├─ kc2.pretty/                   ← 프로젝트 소유 KiCad 풋프린트
│  ├─ kc2.3dshapes/                 ← 부품 3D 모델
│  └─ key-switches.pretty/          ← 외부 스위치 풋프린트 자료
├─ tools/                           ← 생성·검증·테스트 스크립트
│  ├─ fusion/KC2StepToF3D/          ← Fusion native 저장·재열기 도구
│  └─ cache/, __pycache__/          ← 로컬 도구·캐시
├─ kiwi/                            ← 기존 작업 상태 자료; SRS를 대체하지 않음
└─ .codex-tmp/, tmp*/               ← 로컬 실험·복구 자료; 주문/인쇄 사용 금지
```

정식 설계는 `hardware/kicad/kc2_left`, `kc2_right`, `hardware/case`에 있습니다.
`draft`나 백업에서 비슷한 이름의 파일을 골라 쓰지 마세요. 과거 정식 설계는 Git 이력으로,
봉인된 이전 발주 ZIP은 해당 개정의 검토 이력으로 보존합니다.

## 2. 주문할 PCB 거버 ZIP

아래 두 ZIP을 제조 사이트에 각각 업로드합니다. 파일을 변경했다면 먼저 6절의 패키지 검증을 다시 실행하세요.
아래 r4 패키지의 두 ZIP을 사용하며, 기존 r3 ZIP으로 대신 발주하지 마세요.

| 대상 | 정확한 파일 경로 | 한 키보드에 필요한 PCB |
|---|---|---:|
| 왼쪽 | [kc2_left-pcb-fabrication-only.zip](hardware/kicad/first_order/solid-floor-20260907-r4/kc2_left-pcb-fabrication-only.zip) | 1장 |
| 오른쪽 | [kc2_right-pcb-fabrication-only.zip](hardware/kicad/first_order/solid-floor-20260907-r4/kc2_right-pcb-fabrication-only.zip) | 1장 |

좌우는 서로 다른 PCB입니다. 주문 수량은 제조사의 허용 단위에 맞추되 한쪽만 주문하지 마세요.
ZIP을 다시 압축하거나 내부 파일을 추가·수정하지 마세요. 각각 거버9개, job1개,
PTH/NPTH 드릴2개, 드릴 맵2개, 드릴 보고서1개로 총15개 파일입니다.

| 제조 항목 | 설정·확인할 내용 |
|---|---|
| 주문 종류 | Bare PCB 제조만. PCBA 자동 실장 주문 아님 |
| 층수·재질 | 2층, FR-4 |
| PCB 두께 | 1.60 mm |
| 외층 구리 | 1 oz |
| 표면 처리 | ENIG |
| 마스크·실크 | 초록 솔더마스크, 흰 실크 |
| 구멍 | NPTH는 비도금. PTH/NPTH를 임의 합치지 않음 |
| V1 측면 구멍 | Ø2.60 mm. 분석 조건: 직경±0.08 mm, 위치±0.05 mm |
| 비아 | 개별 비아 마스크 덮임. 동일 넷 패드와 겹치는3곳은 노출 예외 |

최종 기준은 [fabrication-profile.json](hardware/kicad/first_order/solid-floor-20260907-r4/fabrication-profile.json)입니다.
업로드 후 자동 인식된 크기·층수·두께·드릴을 미리보기에서 확인하세요. 제조사가 다른 공차를 적용하면
기존 간섭 계산을 그대로 적용하지 마세요. job의 finish 표기는 실제 주문 표면 처리 선택을 대신하지 않습니다.

[왼쪽 수동 조립 BOM](hardware/kicad/first_order/solid-floor-20260907-r4/kc2_left-manual-mx-bom.json) /
[오른쪽 BOM](hardware/kicad/first_order/solid-floor-20260907-r4/kc2_right-manual-mx-bom.json)은 부품 확인용입니다.
BOM/CPL 자동 실장 업로드 승인이 아닙니다.

`fabrication_review/v1-recess-20260906-r3/{left,right}`에는 변경되지 않은 PCB의 검토 거버 원본이 있습니다.
바닥 변경은 PCB 배선을 바꾸지 않으므로 재검증한 같은 제조 바이트를 사용합니다.
이전 하우징 검증까지 그대로 유효하다는 뜻은 아닙니다.

## 3. 인쇄할 하우징 STL — 선택한 MX 조립 기준

최종 r4 검증 완료 후 아래 **6개 STL을 각각1개** 인쇄합니다. `.step`과 `.f3d`는 CAD 확인·편집용입니다.
정식 경로의 파일명은 이전 개정과 같으므로, 파일이 존재한다는 이유만으로 바닥 개정 검증이 끝났다고 판단하지 마세요.

| 용도 | 인쇄 파일 | 수량 |
|---|---|---:|
| 왼쪽 바닥 일체형 하판 | [kc2_left_lower_housing.stl](hardware/case/kc2_left_lower_housing.stl) | 1 |
| 오른쪽 하판 A | [kc2_right_lower_housing_part_a.stl](hardware/case/kc2_right_lower_housing_part_a.stl) | 1 |
| 오른쪽 하판 B | [kc2_right_lower_housing_part_b.stl](hardware/case/kc2_right_lower_housing_part_b.stl) | 1 |
| 왼쪽 MX 보강판 뚜껑 | [kc2_left_mx_upper_housing.stl](hardware/case/kc2_left_mx_upper_housing.stl) | 1 |
| 오른쪽 MX 뚜껑 A | [kc2_right_mx_upper_housing_part_a.stl](hardware/case/kc2_right_mx_upper_housing_part_a.stl) | 1 |
| 오른쪽 MX 뚜껑 B | [kc2_right_mx_upper_housing_part_b.stl](hardware/case/kc2_right_mx_upper_housing_part_b.stl) | 1 |

단위 mm, 축척100%로 사용하며 각 조각은150×150×150 mm 이내입니다. 자동 크기 맞춤으로 축소하지 마세요.
특정 재료·프린터 프로파일의 강도와 치수 정확도는 아직 검증되지 않았습니다.

- **하판:** 넓고 평평한 새 바닥 외면이 베드에 닿게 둡니다. 첫 층과 이후 층이 모두0.20 mm이면 바닥1.20 mm는6층 높이입니다. 바닥층0 또는 vase/spiral 설정은 사용하지 마세요. 미리보기에서 바닥 전체와 작은 받침·파일럿이 생존하는지 확인합니다.
- **MX 뚜껑:** 보강판의 평평한 윗면을 베드에 놓고 받침 기둥이 위로 향하게 뒤집습니다.14 mm 개구, 나사 포켓과 얇은 벽을 확인합니다. 매립 포켓 위 작은 브리지 품질은 실물 확인이 필요합니다.
- 오른쪽 A/B는 별도 조각입니다. 하판과 상판의 결합부를 바꿔 끼우지 않습니다. 출력 오차를 나사로 끌어당겨 억지로 맞추지 마세요.
- 내부 여유 공간을 서포트 잔재로 막지 마세요. 바닥이 있으므로 조립 후 아래에서 납땜하지 않습니다.

### 실리콘 미끄럼방지 발

[왼쪽 부착 배치도](hardware/case/kc2_left_silicone_foot_layout.svg)와
[오른쪽 부착 배치도](hardware/case/kc2_right_silicone_foot_layout.svg)에 부착 위치를 표시합니다.
하판 조각마다 Ø8 mm 평면 영역4곳, 총12곳이며 분할선·가장자리를 피합니다.
이는 부착 공간의 치수이지 특정 제품의 접착력·마찰 성능 검증은 아닙니다.
배치도는 CAD의 XY 좌표 기준입니다. 하판을 뒤집어 바닥에서 보면 좌우가 반전될 수 있으므로, 분할선과 외곽 모양을 기준으로 위치를 맞추세요.
발을 같은 높이로 맞추고 깨끗하고 평평한 면에 붙여 책상에서 흔들림이 없는지 확인하세요.
오른쪽 각 인쇄 조각에도 지지가 있어야 합니다.

## 4. 선택해서 인쇄할 중앙 링

| 모드 | 파일 | 사용 수량 |
|---|---|---|
| MX | [kc2_mx_ring_cap_020.stl](hardware/case/adapters/kc2_mx_ring_cap_020.stl) | 적용할 키마다1개, 최대70개 |
| Choc V1 | [kc2_v1_ring_cap_020.stl](hardware/case/adapters/kc2_v1_ring_cap_020.stl) | 적용할 키마다1개, 최대70개 |

두 링을 한 키에 겹치지 마세요. 소량으로 중심 기둥·안착을 확인한 뒤 필요한 수량을 인쇄합니다.
**넓은 테두리가 베드 쪽**입니다. 첫 층과 이후 층 모두0.20 mm로 설정하면 테두리는 첫1층,
전체1.40 mm 링은7층입니다. 조립할 때는 뒤집어 테두리를 PCB 위에 둡니다.
내경 V1 3.50/MX 4.10 mm는 초기 맞춤값입니다. 출력 수축·실물 공차는 별도 확인하며,
특히 MX 벽0.35 mm가 슬라이서에서 사라지지 않는지 확인하세요.

Choc V1은 하부 Choc 소켓+V1 링 대체 모드이며 MX 뚜껑을 Choc 유지용 보강판으로 취급하지 않습니다.
Choc V2도 별도의 하부 소켓 조립 모드입니다. 한 키에 Choc 소켓과 MX hat 소켓을 동시에 실장하지 않습니다.
선택한 MX 모드의 hat 소켓은70키에140개이며 명목 길이3.00/몸통Ø1.45/플랜지Ø2.00×0.20 mm입니다.
내부 접점 수용 범위·삽입력·공차는 미공개입니다. 핀을 깎거나 힘으로 눌러 맞추지 마세요.

## 5. 조립 순서와 나사

1. PCB 좌우, nice!nano USB 방향, 배터리 BAT+/GND, POWER/RESET 및 다이오드 cathode 표시를 확인합니다.
2. **하판 밖에서** PCB를 납땜합니다. 스위치·보강판으로 소켓을 정렬해 가접하고 식힌 뒤 탈착을 확인한 후 마무리합니다. 열린 소켓 내부로 납을 흘리지 마세요.
3. PCB 아래 핀·납땜 돌출을 측정합니다. 바닥 여유의 설계 조건은 PCB 아랫면 기준 최대2.90 mm입니다. 절단 가능한 납땜 리드는 정리하되 스위치 자체 핀/돌기는 임의 절삭하지 않습니다. 접점 깊이가 부족하면 조립을 중단합니다.
4. 오른쪽 하판 A/B를 결합하고 PCB를 받침에 올립니다. 눌러야 안착한다면 간섭 원인을 먼저 찾습니다.
5. MX 뚜껑·스위치를 맞추고 나사를 조입니다. 왼쪽8개/오른쪽9개, **M1.4×7.50 mm가 명목 길이**이며 이전9 mm는 사용하지 않습니다.
6. 나사 머리 최대 모델Ø3.00×1.20 mm, 포켓Ø3.40×깊이1.50 mm입니다. 새 바닥 때문에 나사를 길게 바꾸지 마세요. 명목 파일럿 삽입2.20 mm/끝 여유0.60 mm이며 실물 길이·출력 공차를 확인합니다.
7. 지정 평면에 실리콘 발을 붙이고 흔들림·분할부·키캡 전체 행정을 확인합니다.
8. **전원 인가 전** 배터리 극성·단락·POWER/RESET을 확인합니다. 미확인 배터리에 charge boost를 켜지 않습니다. 이후70키 입력·충전·무선 성능을 검사합니다.

하판 외면 Z-2.20, PCB 아래/위 Z2.50/4.10, 보강판 위 Z9.30 mm입니다.
실리콘 발을 제외한 바닥 외면–보강판 위 높이는11.50 mm이며 스위치·키캡 높이는 포함하지 않습니다.
나사 머리는 보강판 위보다0.30 mm 낮고, 접착 발 높이만큼 책상 위 높이가 더해집니다.

## 6. 검증·재현·Git 보존

```powershell
& C:/Python312/python.exe -B -m tools.prepare_kc2_first_order --verify-package hardware/kicad/first_order/solid-floor-20260907-r4
```

현재 소스·보고서·CAD·거버 바이트가 모두 필요한 검증이며 실물 합격 판정이 아닙니다.
도구 경로는 환경에 맞추되 PCB 분석은 KiCad Python, CAD는 CadQuery/Shapely가 있는 Python을 사용합니다.
`.gitattributes`가 봉인 해시를 Windows 줄바꿈 변환으로부터 보호합니다. 설계·검증 입력을 편집하면
manifest 해시를 수동으로 고치지 말고 검증·릴리스를 새로 만드세요.
임시·에디터 기록·개인 상태는 커밋에서 제외하고, 추적된 과거 자료는 임의 삭제하지 않습니다.
검증된 좌우 UF2는 재현에 필요한 예외로 포함하되 전체 ZMK 빌드 캐시는 업로드하지 않습니다.

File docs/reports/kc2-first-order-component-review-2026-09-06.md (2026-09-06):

# KC2 first-product component and circuit review

Requirements: CON-ARCH-004, CON-ARCH-006, CON-ARCH-007, REL-ARCH-001,
OPS-ARCH-007. This records pre-order design inspection, not measured hardware
qualification. The first manufactured lot is the product, not a sample prerequisite.

## Source identity and coverage

Canonical LF-normalized PCB SHA-256:

- Left: `e1a50fa657a2cc8ad10a60eed9e0fd5d326c6a138315f429414b9fc18d3b5583`
- Right: `30029aac80a7d1ce0cdf15ead621dcc9906e51775e031c4dffe4841aff8f618c`

The current exact V2 verifier was rerun and returned `errors=[]` and
`connectivity_errors=[]`. Its nine legacy order-blocker messages describe
qualification activities; their timing is governed by OPS-ARCH-007. They are
not converted into physical PASS results. The new first-order package gate also
requires independent actual-output and mechanical reviews.

The KiCad skill was used. No installed `kc2-pcb-preflight` skill was available;
the repository component/circuit checks and independent review cover its stated
gate categories. There is no canonical schematic: this is actual-pad/net versus
SRS/firmware intent review, not an ERC or independently authored schematic-parity claim.

| Item | Actual design review |
|---|---|
| Both nice!nano v2 controllers | All 24 physical pad identities and ordered positions checked; 2.54 mm pitch, 15.24 mm row spacing. Component side up, USB outwards: left USB left, right USB right. Right footprint is the corresponding 180-degree physical orientation, not a backside assembly. |
| Controller battery/reset | RAW is the ordinary side-row battery-positive connection, not 3.3 V/VCC. GND_C is ground. Top-edge extra battery pads are not assumed to be socket contacts. RESET goes only to RST and local GND. Unused controller contacts remain intentionally unconnected. |
| Battery pads, two halves | J_BAT1 pad1 BAT+, pad2 GND, 0.90 mm PTH; no connector polarity is implied by a wire color. Left pad1/2 X=115.8125/113.2725, right=94.3000/96.8400; Y=59.4000 mm. Protected single-cell 301230 nominal 30x12x3 mm envelope is a dimensional interface, not approval of an unspecified pack's charge rating. |
| POWER, two halves | Common pad1 BAT+ at center; pad2 NN_B+; pad3 NC. Left 0 degrees, right 180 degrees. Physical straight-lead order 2,1,3 and 2.54 mm pitch agree with the BSI-10 drawing. Switching the negative lead is not substituted. |
| RESET, two halves | NW3-A06-B3 two-terminal normally-open SMD interface, body 6.1x3.7 mm, nominal height2.55 mm; mirrored placement retains pad1 RST/pad2 GND. No four-terminal switch substitution. |
| 70 switches / 140 MX sockets | Two plated MX contacts per key; both Choc alternate lands tied to the intended corresponding contact nets. 31 left and39 right keys, maximum1.75U, no stabilizers. Selected population is MX hat sockets plus plate-lid; Choc pads stay empty. All locator/center holes remain NPTH. |
| 70 matrix diodes | Exact Diodes Incorporated1N4148W-13-F SOD-123, bottom side. Cathode band to pad1/row, anode pad2/per-key; bottom assembly must follow the mirrored pad1 marking, not a top-view guess. Actual diode nets/geometry and all per-key clearances passed. |
| Mounting and other NPTH | 8 left/9 right M1.4 mounting holes are1.60 mm unnetted NPTH with copper keepout. 195/244 total NPTH holes/slots, including one3.60x2.20 mm battery-lead slot per half; drill inspection matches every center/size. |
| Solder access | U1 oval1.80x2.40 mm /0.95 PTH and MX oval2.50x3.20 mm /1.60 PTH expose their full lands on both faces, without paste. Diode tool-approach, fillet, unrelated-pad/trace, NPTH and edge clearance checks passed. |
| Power/RF geometry | BAT+ switched to RAW/NN_B+, unswitched local GND, no inter-half battery link. Current controller/battery/service and antenna keepouts pass the source-bound geometric checks. Radio and charge performance are not inferred from clearance. |

## Primary-source orientation review

The manufacturer's [nice!nano v2 pinout and schematic](https://nicekeyboards.com/docs/nice-nano/pinout-schematic/)
were opened and the actual pinout image visually compared with both PCB pad rows.
The USB-adjacent ordinary RAW contact is battery positive; the extra top-edge
contacts are separate. Leave the charge-boost jumper open for the nominal100 mAh
pack. The manufacturer warns that bridging it increases charge current; an
unspecified cell must not be assumed to accept that current.

The manufacturer-authored [Diodes DS30086 Rev31-2 drawing](https://www.mouser.com/datasheet/2/115/ds30086-3214660.pdf)
confirms SOD-123, cathode band and exact -13-F ordering identity. Body maximum
2.85x1.70 mm, terminal span3.85 mm, height1.35 mm were compared with the owned
land and underside envelope. The enlarged1.40x1.55 mm pads at3.60 mm center
spacing are KC2 hand-solder lands, not mislabeled manufacturer recommendations.

The manufacturer-authored [BSI-10 drawing](https://amec-gmbh.de/wp-content/uploads/2022/11/BSI-10.pdf)
was downloaded and visually inspected. It shows central common1, throws2/3,
2.54 mm pitch,0.80 mm PCB holes,0.60 mm terminals,10x2.50 mm body and1.60 mm travel.
This verifies the intended physical interface. The historic `IMMS-12V_BSI-10`
value is not proof that every seller's similarly named switch is identical;
received parts must match that interface. Terminal2 versus3 changes actuator
direction, not the battery/ground topology.

The product's attached [NW3-A06-B3 drawing](https://www.devicemart.co.kr/goods/download?id=1322056&rank=1)
was also downloaded and visually inspected after the browsing interface timed
out. It shows the two-terminal normally-open circuit,6.1x3.7 mm body,2.55 mm
height and8 mm terminal span. Suggested lands have6 mm inner gap and9.5 mm
outer span, giving1.75 mm land length and7.75 mm center spacing, matching the
owned footprint. Left/right mirroring therefore does not interchange a
power-sensitive terminal or accidentally short a duplicated four-leg pair.

## DRC and fabrication exceptions

Both current source-bound DRC reports have zero hard errors, warnings and
unconnected items. The inherited exclusions are footprint_filters_mismatch,
footprint_type_mismatch, missing_courtyard, track_not_centered_on_via and
tuning_profile_track_geometries. These do not waive electrical clearance;
library identity, courtyard/body and via geometry are separately inspected.
Ordinary unrelated copper clearance remains0.30 mm. Owned footprint and current
route replay checks bind regenerated pads, masks and routing; 26 focused tests
including fresh generation/replay, fresh-process pad checks, route binding and
Fusion/housing integration passed in7.581 seconds.

Actual mask rendering, beyond a centered-flash check, found three SAME-NET
pad-opening/via overlaps:

| Side/coordinate(mm) | Pad / net | Open faces |
|---|---|---|
| Left136.500,59.400 | U1 D5 / L_COL1 | Front and back |
| Right73.500,59.500 | U1 D18 / R_COL5 | Front and back |
| Right90.754,127.917 | D27 pad1 / R_ROW3 | Back |

Each is a0.30 mm via drill. These are not unrelated-net shorts or extra mask
apertures. They can draw solder from the adjacent land during hand assembly;
inspect and replenish the joint without flooding the socket. Isolated vias
retain tenting, but **all vias fully tented is false**. No filled/capped-via
service is requested, and the remaining solder land is not masked off merely
to hide these holes. This explicit fabrication exception supersedes historical
blanket-tenting descriptions for this output set.

## Analytical limits and assembly acceptance

Read the separate socket-fit and actual-output visual reviews. The1.60 mm MX
hole has a known PCB-only1.52..1.73 mm finished range, not a guaranteed full
socket tolerance fit. Exact blade/contact-spring tolerances remain unknown.
Current5.20 mm plate stack meets the generic reference nominal geometry but
provides no additional local flange-height reserve. A9 mm under-head screw is
the calculated candidate;10 mm is a known bottoming conflict and is prohibited
for this stack. No10 mm screw is selected by this release.

After receipt and before energizing, check polarity and shorts without a battery,
then verify actual pack protection/rating, wiring and switch operation. Inspect
socket seating, continuity, solder intrusion and retention before assembling the
complete product. Preserve the SRS post-receipt contact-cycle, scanning, housing,
power and RF acceptance activities as pending. This review identifies no known
electrical/net incompatibility in the frozen PCB; it does not guarantee unknown
purchased-part tolerances or replace received-part inspection.

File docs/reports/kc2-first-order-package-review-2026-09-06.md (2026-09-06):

# First-product package code review — 2026-09-06

Requirement: `OPS-ARCH-007 AC-1/2/3/4/5` (evolving, in progress).

Independent review covered `tools/prepare_kc2_first_order.py` and
`tools/test_prepare_kc2_first_order.py`. No production package was created by
this review and no PCB or manufacturing input was modified.

## Result and regression evidence

The original nine tests passed. Two additional mutation tests then failed as
expected: removing a selected manual BOM and its output hash was accepted;
changing the manifest to request machine placement was also accepted. The
small correction requires the exact output inventory and explicit hand-assembly
flags. All eleven tests now pass:

```powershell
python -B -m unittest tools.test_prepare_kc2_first_order
```

Current raw-byte SHA-256:

- Package tool: `0abdecc87b28862c83c6cb502a47e4c8b6a6693fb87ad013e1fef5fb94aef743`
- Tests: `1d0109b281c6c6583914765b97948e5abcc175543ac0a3e017204ef4bf5e0215`

The review confirmed required raw-byte source/review bindings, independent
board/project/DRC-sidecar consistency, source/output drill and solder-land
comparison, explicit unchecked-review/known-blocker rejection, no overwrite,
staged publication and rechecking source bytes before publication.

## Exact delivery inventory

The sealed delivery directory must contain exactly eight files:

- `manifest.json`
- `review-evidence.json`
- `digital-validation.json`
- `fabrication-profile.json`
- `kc2_left-manual-mx-bom.json`
- `kc2_right-manual-mx-bom.json`
- `kc2_left-pcb-fabrication-only.zip`
- `kc2_right-pcb-fabrication-only.zip`

The manifest hashes the seven other files. Each ZIP must contain exactly fifteen
reviewed files for its own half: nine Gerbers (front/back copper, mask, paste and
silk, plus outline), the Gerber job, separate PTH/NPTH drills, two drill maps,
and the drill report. Names and bytes must match the bound input allowlist.
No BOM, CPL, historical ZIP or other placement file may enter those ZIPs.
The selected manual MX BOMs are separate hand-assembly references.

`machine_placement_requested=false`, `bom_cpl_upload_authorization=false`,
`assembly_service=none_hand_assembly` and
`physical_qualification_complete=false` remain enforced. A successful first-order
build does not turn pending physical records into passed records.

## Limits

The qualitative review booleans are engineering sign-offs backed by hashed
reports, not an independent geometric proof or cryptographic reviewer identity.
The standalone `verify_package()` function checks offline package bytes and
inventory. The CLI `--verify-package` additionally revalidates the bound evidence
against current repository sources. The package verifier does not independently
rederive the entire manual BOM from the source board; the build derives it and
binds its bytes. An entirely rewritten evidence set still requires legitimate
engineering review, not merely recalculated hashes.

Actual Gerber visual observations, including the three same-net exposed-via
solder-wicking exceptions, are recorded in
[the visual review](kc2-mx-gerber-visual-review-2026-09-06.md). Exact component,
housing and full-travel assessments belong to their separate bound reports.
This code review alone is not first-order approval, physical qualification,
machine-placement permission or authorization to purchase.

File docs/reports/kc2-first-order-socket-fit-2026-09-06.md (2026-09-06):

# KC2 first-product MX socket and stack review — 2026-09-06

Requirements: `CON-ARCH-004`, `CON-ARCH-006`, `OPS-ARCH-007` (in progress / evolving). This is dimensional research, not a second requirements source or complete fabrication approval. The user's first order is the product; no separate pre-order coupon is required. Physical tests remain pending after receipt, not passed or waived. No PCB/CAD geometry was changed for this report.

## Evidence and selected dimensions

The selected [seller product](https://ko.aliexpress.com/item/1005010364025678.html) [hat-style drawing](https://ae-pic-a1.aliexpress-media.com/kf/S4b47dab427cd4b539a50618bf16a62d9J.jpg) specifies total length **3.00 mm**, barrel OD **1.45 mm**, flange OD **2.00 mm**, flange thickness **0.20 mm**, and an open bottom. It does not specify dimensional tolerances, entry ID, accepted flat-blade section, spring position, contact length, force, or resistance. The drawing was visually inspected from the locally cached original image; live AliExpress product access failed. The 3.50 mm hatless and prior 4.00 mm alternatives are not this selection. “Mill-Max compatible” does not transfer another manufacturer's tolerances or contact specification.

The manufacturer-authored [Cherry MX drawing, archived by Farnell](https://www.farnell.com/datasheets/1792245.pdf), visually inspected pages 2 and 5, provides this generic reference:

| Reference feature | Drawing value | Interpretation |
|---|---:|---|
| Under-flange body depth | 5.0 mm | Reference switch underside datum |
| Exposed contact length | 3.30 mm | From body underside to tip |
| Frame top above PCB | 0.197 +0.012 inch | Approximately 5.00 to 5.31 mm; not symmetric ±0.012 |
| Square opening | 0.551 ±0.002 inch | 13.9954 ±0.0508 mm |
| Corner radius maximum | 0.012 inch | 0.3048 mm |
| Frame thickness | 0.060 ±0.004 inch | 1.524 ±0.1016 mm |

The 1.50 mm candidate plate is within that reference thickness interval. This archived generic drawing is not a controlled drawing of the user's exact switch, and does not establish FDM dimensional accuracy or keycap clearance. Its inspected views do not dimension the contact blade width/thickness. No numeric blade cross-section is invented here.

## Finished hole and solder land

[JLCPCB published capabilities](https://jlcpcb.com/capabilities/pcb-capabilities) give ordinary PTH diameter tolerance +0.13/−0.08 mm, hole position ±0.05 mm and 1.60 mm PCB thickness ±10%. These are the known fabrication bounds; seller socket tolerances remain unknown.

| Calculation | Result |
|---|---:|
| Finished 1.60 mm PTH | 1.52–1.73 mm |
| Diametral clearance to nominal 1.45 mm barrel | 0.07–0.28 mm; nominal 0.15 mm |
| Radial clearance | 0.035–0.140 mm; nominal 0.075 mm |
| Conservative minor-axis copper ring, 2.50 mm land | (2.50−1.73)/2−0.05 = 0.335 mm |
| Centered flange overlap at largest hole | (2.00−1.73)/2 = 0.135 mm |

These are **PCB-only bounds with the socket held nominal**, not full worst-case production fit. Guaranteed non-interference requires actual maximum barrel OD below 1.52 mm, with additional assembly clearance desired. Increasing the drill without a demonstrated need reduces flange bearing and annular ring. At maximum hole/barrel eccentricity (0.140 mm), the nominal flange need not cover the entire hole circumference; this is not complete loss of retention, but supports centering the receptacles with the correctly seated switch/plate during soldering. Prevent solder entering the spring.

No known barrel/hole interference follows from the supplied nominal values. An unknown seller OD tolerance is a disclosed procurement risk, not evidence that interference already exists.

## Vertical stack, open bottom and contact engagement

Engineering assumptions: generic 5.0 mm under-flange body; 3.30 mm exposed pin; socket flange sits on PCB top; no beneficial recess in the switch underside; current plate top is 5.20 mm above PCB top, with a 1.50 mm plate and 3.70 mm hard stop. Dimensions below are calculations, not measured assemblies.

Taking PCB top as zero:

| Feature | Nominal Z (mm) |
|---|---:|
| Plate top / bottom | +5.20 / +3.70 |
| Switch underside and nominal flange top | +0.20 |
| Socket bottom | −2.80 |
| Switch contact tip | −3.10 |

The nominal switch underside meets the flange top with **zero additional local height reserve**. Unknown body/flange/print tolerances can affect seating; the archived frame-spacing interval is not proof of a clearance allowance inside every MX clone. The pin extends 0.30 mm through the open socket bottom, which is not a bottoming collision. Axial reach alone cannot prove spring engagement: the seller gives neither spring start/end positions nor usable contact travel.

For PCB thickness 1.44–1.76 mm, socket protrusion below PCB is 1.04–1.36 mm (nominal 1.20); pin protrusion is 1.34–1.66 mm (nominal 1.50). The lower support plane at Z=2.50 and desk at Z=−1.00 provide 3.50 mm below-PCB space. Thus nominal socket/pin desk clearances are 2.30/2.00 mm; PCB-only minima are 2.14/1.84 mm. Subtracting a separate 0.30 mm print allowance leaves 1.84/1.54 mm, **before unknown socket/pin tolerances and solder protrusion**. Do not label 1.20 mm socket protrusion a maximum envelope.

For blade width `w`, thickness `t`, and a rigid circular mouth ID `d`, `sqrt(w*w+t*t) <= d` is a useful geometric entry check, but not a contact-force/elastic-spring qualification. None of these three selected-part dimensions is available here. A different branded receptacle's round-pin range cannot resolve this flat-blade question.

## Long-screw length candidate, not an exact part approval

Current stack places the under-head bearing face 6.80 mm above receiver entry; receiver pilot depth is 2.80 mm. For an under-head screw length `L`, nominal insertion is `L−6.80`, and bottom reserve is `9.60−L`.

| Under-head length | Nominal insertion | Nominal bottom reserve | PCB-only insertion range |
|---|---:|---:|---:|
| 8.00 mm | 1.20 mm | 1.60 mm | 1.04–1.36 mm |
| **9.00 mm candidate** | **2.20 mm** | **0.60 mm** | **2.04–2.36 mm** |
| 10.00 mm | 3.20 mm | −0.40 mm | 3.04–3.36 mm |

A 10 mm under-head screw is a **known geometric bottoming conflict** with this unmodified stack. A 9 mm candidate balances insertion and reserve better than 8 mm, without changing geometry. Its PCB-only bottom reserve is 0.44–0.76 mm. Full thread engagement is less than insertion when the point or incomplete threads occupy the tip. Screw length tolerance, pilot depth/print error, head seating error and point length are not yet supplied; combined adverse length/depth errors must remain below 0.44 mm to avoid bottoming at the known PCB-thickness bound. This is not a thread-strength or torque qualification. Retain the required non-countersunk head envelope ≤3.00 mm diameter ×1.20 mm height and verify actual thread form against the printed pilot before selecting a purchasable screw.

## Decision and post-receipt checks

The selected hat socket has **no demonstrated nominal hole or open-bottom vertical incompatibility**. Remaining unknowns are actual barrel/flange tolerances, exact MX blade and underside geometry, spring contact/force/resistance, printed aperture/clip fit, solder envelope, and exact fastener tolerances. These are explicit first-product residual risks under `OPS-ARCH-007`; they are not fabricated PASS evidence and do not independently require a separate pre-order sample.

After receipt, inspect the actual product parts: finished hole/OD and flange seating; both switch contacts' insertion, continuity and retention; final plate opening and clip seating; solder intrusion/bridges and underside clearance; actual screw tip reserve and progressive tightening; keycap full travel and service-driver access. Use the physical acceptance definitions in the SRS. A known incorrect part, interference, electrical error or stale output still blocks first-order approval. Full-board electrical, component, Gerber/drill, 1:1 and upper-head/keycap checks remain separate mandatory digital review work.

## Inspectable 1:1 and native geometry evidence

New [left 1:1 overlay](../../hardware/case/kc2_left_first_order_1to1.svg) and [right 1:1 overlay](../../hardware/case/kc2_right_first_order_1to1.svg) use actual current PCB Edge.Cuts and drilled switch, U1 and MH centers read by KiCad from byte-identical temporary snapshots. Black is PCB outline; blue is the nominal 14 mm plate aperture at each actual switch center; red is U1 drill geometry; green is MH; orange is switch electrical/mechanical drill geometry. SVG physical width/height are in millimetres with one viewBox unit per millimetre. Print at actual size, never fit-to-page. These drawings show geometric alignment, not exact switch-body/keycap silhouettes or full-travel qualification. The [overlay manifest](../../hardware/case/kc2_first_order_1to1_manifest.json) binds both source and SVG hashes and records all extracted coordinates.

The new helper `tools/generate_kc2_first_order_overlay.py` is read-only for boards and fails closed on unsupported non-segment outlines, slots, unexpected key/U1 counts or concurrent source changes. Requirement-linked automated tests were first run RED (missing implementation), then GREEN (2 tests), checking physical units, exact aperture/pad centers and absent-outline rejection. Regenerate with KiCad Python after any PCB change; a report link alone does not prove freshness.

Both overlays now include a visible legend, 50 mm calibration bar and 100% print instruction. The footer requirement was tested RED before implementation and the 2 tests passed again afterward. An independent reviewer inspected the original registration drawings and found no clipped outlines or misplaced visible aperture/drill patterns; that inspection does not establish controller-body, keycap or full-travel fit.

Existing [left upper plan](../../hardware/case/kc2_left_mx_upper_plan.svg), [right upper plan](../../hardware/case/kc2_right_mx_upper_plan.svg) and [dimensioned mounting Z section](../../hardware/case/kc2_mx_mounting_section.svg) show the candidate split/lid and stack. The Z section is explicitly an enlarged diagram, not the 1:1 board print template.

Native upper geometry: [left STEP](../../hardware/case/kc2_left_mx_upper_housing.step), [right STEP](../../hardware/case/kc2_right_mx_upper_housing.step), [left F3D](../../hardware/case/kc2_left_mx_upper_housing.f3d), [right F3D](../../hardware/case/kc2_right_mx_upper_housing.f3d). Native lower geometry: [left STEP](../../hardware/case/kc2_left_lower_housing.step), [right STEP](../../hardware/case/kc2_right_lower_housing.step), [left F3D](../../hardware/case/kc2_left_lower_housing.f3d), [right F3D](../../hardware/case/kc2_right_lower_housing.f3d). All four native round trips are indexed by the [Fusion result](../../hardware/case/kc2_fusion_export_result.json). Native round-trip dimensional equality is not physical fit evidence. The overlay manifest explicitly uses raw-byte SHA256, whereas the main CAD evidence uses `tools.canonical_hash` newline-normalized hashes; compare like policies rather than interpreting CRLF differences as geometric changes. Actual PCB geometry changes require existing CAD manifests to undergo exact-geometry rebinding or regeneration checks; the new current-coordinate SVG does not silently requalify old CAD.

## All-17 head / keycap travel projection review

Read-only calculation uses current overlay coordinates, `make_left_keys_x3_v2` / `make_right_keys_x3_v2` key widths and the same keycap rectangle formula as `tools.verify_kc2_x3_v2_outline.keycap_bounds`: half-size = key unit dimension ×19.05/2−0.50 mm. Heads are radius 1.50 mm discs. Exact circle-to-rectangle distance is `hypot(max(abs(dx)−half_width,0), max(abs(dy)−half_height,0))−1.50`; negative means overlap, not a measured collision depth. The plate check uses 7 mm half-width apertures. Current switch rotations are multiples of 90 degrees, so those square apertures are unchanged by rotation.

| Side / mount | Nominal keycap projection | Nearest cap | Head-to-aperture gap (mm) | Existing head-to-installed-component XY gap (mm) |
|---|---|---|---:|---:|
| Left MH1 | clear 24.000 mm | SW5 | 26.0250 | 2.7292 |
| Left MH2 | clear 0.750 mm | SW6 | 2.7750 | 1.9750 |
| Left MH3 | overlaps | SW14 | 2.3062 | 1.5062 |
| Left MH4 | overlaps | SW14 | 3.1750 | 1.7705 |
| Left MH5 | overlaps | SW28 | 3.3937 | 2.5937 |
| Left MH6 | overlaps | SW30 | 7.2562 | 6.2565 |
| Left MH7 | overlaps | SW31 | 2.4187 | 1.6187 |
| Left MH8 | overlaps | SW21 | 2.1375 | 1.3375 |
| Right MH1 | clear 23.750 mm | SW3 | 25.7750 | 2.5738 |
| Right MH2 | tangent; zero reserve | SW2 | 2.0250 | 1.2250 |
| Right MH3 | overlaps | SW16 | 4.5813 | 3.1136 |
| Right MH4 | overlaps | SW16 | 2.4187 | 1.6187 |
| Right MH5 | overlaps | SW23 | 2.4125 | 1.6069 |
| Right MH6 | overlaps | SW34 | 3.5750 | 1.6379 |
| Right MH7 | overlaps | SW34 | 5.6812 | 4.2957 |
| Right MH8 | overlaps | SW35 | 2.1062 | 1.3062 |
| Right MH9 | overlaps | SW23 | 2.4000 | 1.2429 |

Thus **13 heads overlap nominal cap projections and one is tangent**. These positions cannot be cleared for full travel merely from plan views. No head intersects the nominal plate aperture; the minimum aperture gap is 2.025 mm. The last column is read from the current lower housing manifest's per-hole `head_to_installed_component_mm`. Its implementation computes 2D separation from the union of 15.60 mm switch-service rectangles, component features including controller/socket/reset geometry, and battery/POWER body/sweep geometry. Positive plan gaps exclude intersection with those modeled envelopes irrespective of Z, but do not qualify missing or larger actual part shapes. Keycaps are explicitly excluded by its keycaps-off service assumption.

The actual upper head envelope is **Z=9.30–10.50 mm**, not the old head-on-PCB 4.10–5.30 mm envelope. At every overlapped head location, the selected keycap's underside throughout the full keystroke must remain above the head. A proposed **0.30 mm engineering assembly reserve** makes the interface requirement underside ≥10.80 mm at the nominal stack, equivalently ≥1.50 mm above plate top. This reserve is an assumption for this review, not a supplied keycap tolerance. An exact cap underside/travel model is unavailable, so that condition is **unproven**, not PASS and not a demonstrated 3D collision. PCB-thickness movement shifts head and plate together; it does not supply missing local cap-to-head clearance.

This is a high-risk conditional mechanical interface for the first **PCB-fabrication-only** release, not approval to buy unspecified keycaps/fasteners or a claim that the printed full assembly is qualified. A compatible cap may satisfy it; otherwise a separately reviewed cap/fastener/housing change may be needed. Do not assume relief is possible or silently modify the current geometry. The candidate 9 mm screw remains conditional on both the axial pilot calculation and this actual head/cap interface. A later proven underside collision remains a real fit error regardless of verification phase.

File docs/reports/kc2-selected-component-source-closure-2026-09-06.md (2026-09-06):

# Selected-component source closure review

Date: 2026-09-06. Requirement: `CON-ARCH-004`; release interpretation: `OPS-ARCH-007`.
Read-only component research; no board, requirements, old evidence or part selection was changed.

## Result

The bounded primary-source search did **not** close the exact selected TTC blade/post/seat tolerances,
the selected hat socket's admissible contact range, or the selected Deep Sea brown switch's controlled
manufacturer drawing/MPN linkage. These remain unknown, not zero-tolerance fits or newly discovered
dimensional failures. No seller was contacted and no order was placed.

## TTC selected listing

The user selected [AliExpress item 1005012442816250](https://ko.aliexpress.com/item/1005012442816250.html).
Its [seller image](https://ae-pic-a1.aliexpress-media.com/kf/Sd76e89944bdc4bf2881f9a82ffc9d9b5z.jpg),
re-inspected locally as `.codex-tmp/selected-ttc-0.jpg`, identifies Bluish White, tactile/silent,
3-pin, operating force 42 ± 5 gf, tactile force 50 ± 5 gf, pretravel 2.0 ± 0.4 mm and total travel
3.5 ± 0.4 mm. It shows two electrical contacts and one plastic center post, not a dimensioned drawing.
Raw image SHA-256: `faa5dfdca7bc4e5258707617f1183e0d1f4be8e548b13f78eef98a6a620eb799`.

The [TTC manufacturer Bluish White page](https://en.ttc9.com/product/122.html) was fetched successfully
with direct HTTP after the browser tool failed. Its product text/table gives 42 ± 5 gf operating force,
58 ± 5 gf tactile force, 2.0 ± 0.3 mm pretravel and 3.5 ± 0.3 mm total travel. Those tactile-force and travel
tolerances differ from the seller image. The inspected product text and links provide no controlled
blade cross-section, exposed blade length, center-post diameter/length or board/plate seating datum.
No exact manufacturer order code ties that manufacturer's page revision to this AliExpress lot.
Do not silently substitute the manufacturer's narrower travel tolerance or infer a V2 revision.

The seller's stated travel has an upper end of 3.9 mm. This can bound a travel-only engineering
scenario; it does not establish a keycap underside or socket engagement depth.

## Selected hat socket

The selection is [AliExpress item 1005010364025678](https://ko.aliexpress.com/item/1005010364025678.html),
hat style. The [seller section drawing](https://ae-pic-a1.aliexpress-media.com/kf/S4b47dab427cd4b539a50618bf16a62d9J.jpg)
was visually re-inspected from `.codex-tmp/hat-seller-3.jpg`; raw SHA-256
`0bdb35b93473ce078fcd53aafcb68abb7cc7c5bdea75106ccb31a1afc4d260fc`.
It shows 3.00 mm overall length, 1.45 mm barrel OD, 2.00 mm flange OD, 0.20 mm flange thickness,
an internal claw spring and open bottom. It gives no bore diameter, spring throat dimension,
contact working depth, insertion force, rectangular-blade acceptance range or tolerances.

The same image also shows a different hatless 3.50 mm / 1.50 mm OD variant. It is not selected.
Neither a genuine Mill-Max family specification nor the previously downloaded closed-bottom
4 mm socket drawing can establish contact acceptance for this untraceable hat-compatible part.
No controlled manufacturer part identity for the selected hat was found in the inspected sources.

## Kailh selected brown listing

The user selected the brown option of [AliExpress item 1005008743343263](https://ko.aliexpress.com/item/1005008743343263.html).
Cached seller photographs `.codex-tmp/kailh-selected-main.jpg`, `kailh-selected-second.jpg` and
`kailh-selected-last.jpg` were visually re-inspected. They show the low-profile blue-base product,
brown circular-wall cross stem, and a separate pink-stem option. They contain no dimension annotations
or readable manufacturer part code. Main image raw SHA-256:
`9b2a86dd47a460c159f2f768d14cd5e16e1b5c2874a36418b33bb98e89f53ed3`.

The [Kailh product datasheet index](https://www.kailh.net/pages/product-datasheet) separates normal-height
Deep Sea Silent Box from Choc V2. Its [Choc V2 product page](https://www.kailh.net/products/kailh-choc-v2-low-profile-switch-set)
lists brown `CPG135301D02` and links a [manufacturer datasheet](https://cdn.shopify.com/s/files/1/0657/6075/5954/files/SPEC-CPG135301D02_Kailh_Choc_V2_Low_Profile_Brown_Switch_828a8159-bda2-47ea-a12f-4da0c9767f5d.pdf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).
That link is a genuine family reference, but no inspected source binds its MPN to the selected
blue-base Deep Sea seller lot. Similarly, the normal-height Deep Sea Box/Pro data must not be applied
to this low-profile selection merely because the marketing names overlap.

## Search boundary and closure evidence

All three original AliExpress URLs failed in the browser reader on this pass; existing original seller
image caches were used explicitly. Manufacturer-domain searches in English and Chinese, the reachable
TTC product page, Kailh store product/datasheet pages, and the cached selected drawings/photos produced
no exact-part dimensional closure. This is a bounded search result, not a claim that unpublished supplier
drawings cannot exist.

Closure would require a controlled drawing tied to the supplied lot (TTC blade/post/seat; Kailh exact
low-profile brown geometry), and a hat socket specification covering both selected rectangular blades
and working engagement depth. Without these, keep nominal family CAD checks separate from actual-part
qualification and report the remaining contact/fit uncertainty explicitly.

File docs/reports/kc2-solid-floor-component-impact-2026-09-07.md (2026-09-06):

# Closed-floor component impact review

Requirements: `CON-ARCH-006`, `OPS-ARCH-007`, with preserved circuit/component constraints under `CON-ARCH-004` and physical power/RF gates under `CON-ARCH-007`/`REL-ARCH-001`.

This is an incremental independent component-impact review, not a claim that a closed shell thermally or physically qualifies unknown purchased parts. The current floor CAD/native review is separate; older open-bottom r3 housing evidence is not sufficient.

## Unchanged electronics and fabrication

A fresh raw-byte comparison against sealed r3 review bindings checked35 PCB/project/Gerber/drill/owned-footprint inputs and found zero differences. [Full input comparison](kc2-solid-floor-component-inputs-2026-09-07.json) lists every selected path and both hashes. No copper, physical pad center, polarity, controller/service pinout, socket footprint, matrix circuit or manufacturer component identity changes merely because the floor is added. The [r3 component-by-component review](kc2-v1-recess-component-review-2026-09-06.md) therefore remains electrical/part-orientation evidence for those identical bytes, but not proof of the new mechanical cavity.

## Inner-floor clearance is bounded, not assumed unlimited

PCB underside remains Z2.50 mm; inner floor is Z-1.00 mm. Available nominal depth is3.50 mm. The current SRS maximum permitted actual projection is2.90 mm, leaving0.60 mm nominal clearance. Reserving0.30 mm for engineering print error leaves0.30 mm residual clearance. This is an assembly limit to inspect after receipt, not a measured maximum of unknown headers, posts, wires or solder.

| Item | Existing dimensional evidence | Floor impact |
|---|---|---|
| Open-bottom hat socket | Nominal length3.00, flange0.20, PCB1.60 mm; nominal below-PCB projection1.20 mm | Nominal floor gap2.30 mm. PCB-only1.44..1.76 variation gives projection1.36..1.04 and minimum2.14 mm gap. Supplier socket dimensions remain nominal; solder is additional. |
| Choc socket | Current generator uses2.30 mm controlled maximum body depth +0.10 mm assembly allowance =2.40 mm modeled projection | Modeled floor gap1.10 mm (3.50-2.40), not the historical2.20 mm bare-body reference's1.30 mm gap. Selected-lot body/contact qualification remains separate. |
| SOD-123 diode | Controlled body height limit1.35 mm +0.30 mm solder-fillet depth allowance =1.65 mm modeled projection | Modeled floor gap1.85 mm (3.50-1.65). The bare-body-only2.15 mm result excludes the modeled solder allowance and is not the assembled clearance. |
| Switch pins, locator posts, controller socket tails, service pins | No complete exact-lot protrusion inventory | Require every actual rigid projection and solder accumulation to remain<=2.90 mm below PCB. A nominal reference switch-pin analysis is not selected-part measurement. |
| Battery leads/insulation | Battery lead slot and controller/battery placement unchanged | Wire loops now enter an internal cavity. Route and restrain without pinching against floor, screw, post or split; do not infer fit from copper clearance. |

These assembled-envelope values follow `CHOC_SOCKET_OFFICIAL_BODY_DEPTH_MAX_MM`, `CHOC_SOCKET_ASSEMBLY_ALLOWANCE_MM`, `DIODE_OFFICIAL_BODY_DEPTH_MAX_MM` and `DIODE_SOLDER_FILLET_DEPTH_ALLOWANCE_MM` in [the current housing generator](../../tools/generate_kc2_x3_v2_housings.py). Its `closed_floor_parameters().nominal_clearance_by_component_mm` and [the housing contract verifier](../../tools/verify_kc2_mx_housing_contract.py) agree on Choc1.10/diode1.85/hat2.30 mm. The separate0.30 mm engineering print reserve would leave0.80/1.55/2.00 mm respectively under those modeled projections; it does not establish actual supplier tolerances or solder dimensions.

Remove the PCB before soldering or trimming permissible bare lead tails; do not solder through the closed floor. Do not grind a functional switch/socket body or force an overlong component to fit. If an actual part exceeds the projection limit, stop closure and revise the selected stack/part with measured evidence. Do not use screw preload to compress wires, solder joints or a battery.

The floor is below the existing support-foot ends; it does not move PCB support, receiver entry, pilot end or recessed head bearing. The7.50 mm under-head screw remains the nominal contract:2.20 mm insertion and0.60 mm receiver-tip reserve. Additional outside floor thickness is not permission to lengthen screws. Exact screw length tolerance and printed-thread strength remain unqualified.
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

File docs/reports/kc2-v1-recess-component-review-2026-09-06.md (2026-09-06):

# V1 / recessed-lid revision: independent component and circuit review

Requirements: `CON-ARCH-004`, `CON-ARCH-006`, `CON-ARCH-007`, `OPS-ARCH-007` (current evolving requirements queried through SpecKiwi). This is a fresh read-only review of the promoted canonical PCBs, not a reuse of the r2 board verdict and not final fabrication approval. KiCad skill instructions were followed; no installed `kc2-pcb-preflight` skill was available. No canonical PCB, CAD, or sealed package was changed by this review.

## Bound evidence

The [actual-pad inventory and analyses](kc2-v1-recess-component-data-2026-09-06.json) include every footprint and pad: reference, value, library identity, assembly side, orientation, coordinate, net, pad/drill size, and declared layer set. Twenty-two raw-SHA source bindings cover both PCBs, DRC reports, checker sources, firmware configuration/build evidence, generation manifest, and both UF2 files. All source hashes were identical before and after collection.
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

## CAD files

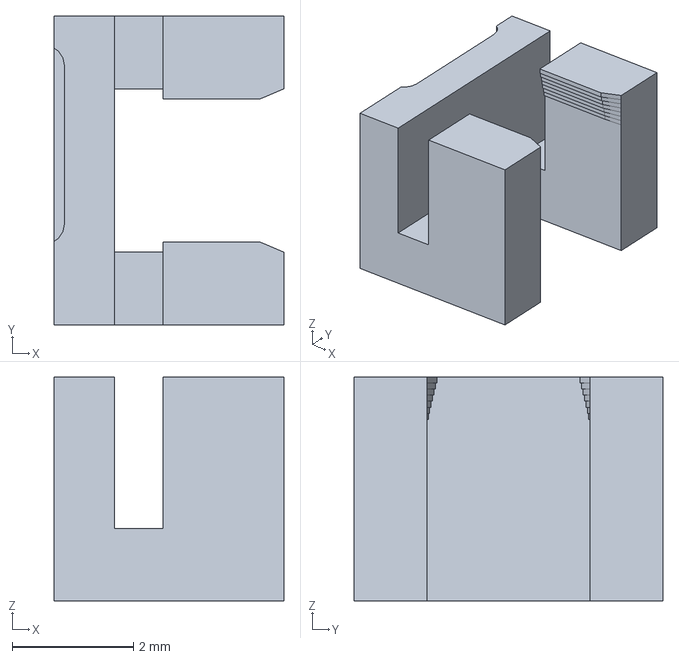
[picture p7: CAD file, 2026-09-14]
docs/reports/registered-housing-fit-20260913/evidence/central/right-central-y95.step
3.80 x 5.10 x 3.70 mm

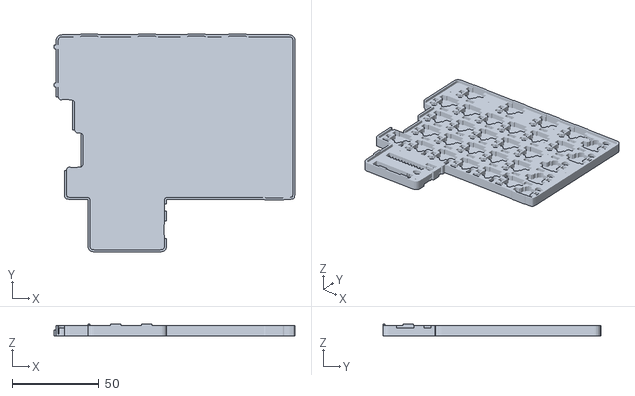
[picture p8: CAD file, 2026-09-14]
docs/reports/registered-housing-fit-20260913/evidence/lower-development/left-central-inputs/left-magnetic/kc2_left_lower_housing_magnetic.stl
139.3 x 125.8 x 7.20

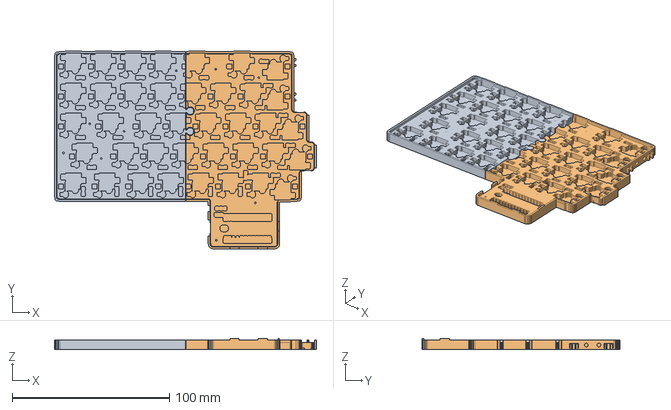
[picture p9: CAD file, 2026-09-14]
docs/reports/registered-housing-fit-20260913/evidence/lower/right-magnetic/kc2_right_lower_housing_magnetic.native-readback.step
166.7 x 125.8 x 7.20 mm

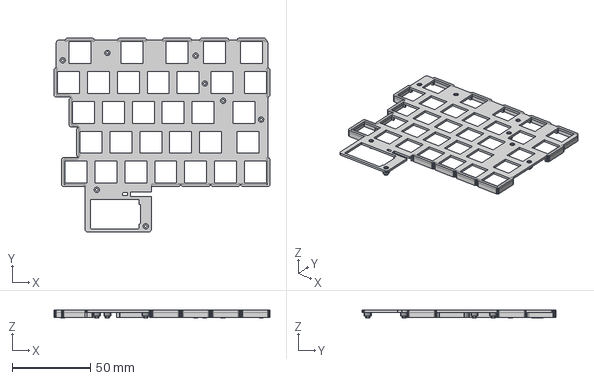
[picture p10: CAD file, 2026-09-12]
docs/reports/reinforced-covers-20260913/native-check-left_mx_upper.step
137.7 x 123.7 x 5.20 mm

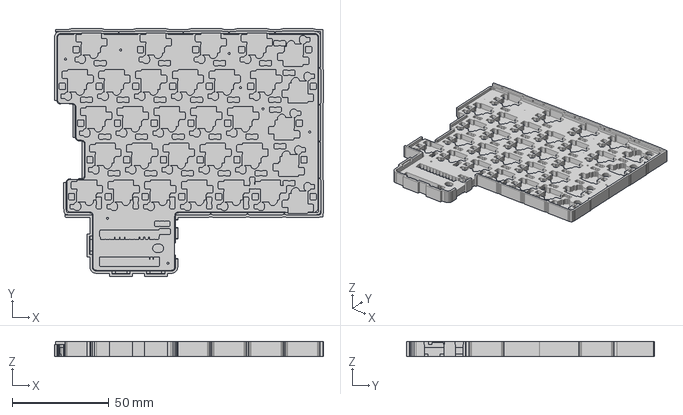
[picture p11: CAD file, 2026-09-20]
docs/reports/wrap-housings-20260920/lower/left-magnetic/kc2_left_lower_housing_magnetic.native-readback.step
139.4 x 128.3 x 7.80 mm

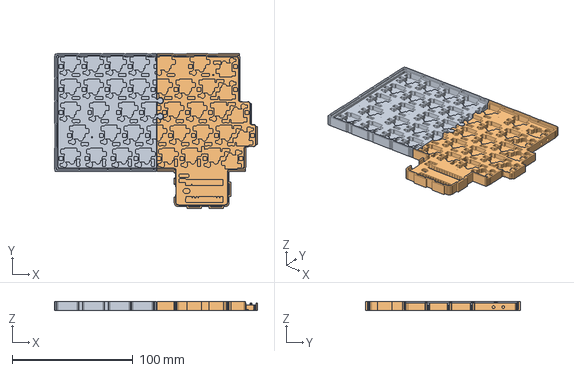
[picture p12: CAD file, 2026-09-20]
docs/reports/wrap-housings-20260920/lower/right-magnetic/kc2_right_lower_housing_magnetic.native-readback.step
168.0 x 128.3 x 7.80 mm

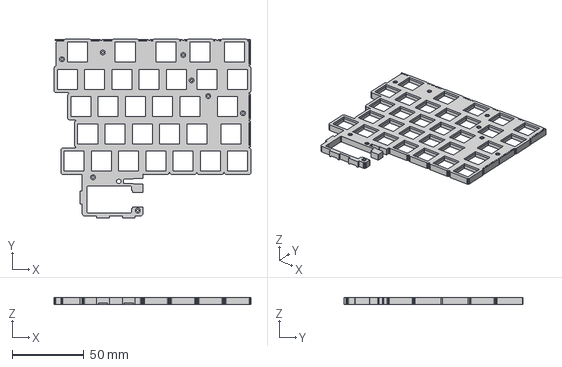
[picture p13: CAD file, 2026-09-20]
docs/reports/wrap-housings-20260920/upper/left-mx/kc2_left_mx_upper_housing.native-readback.step
137.7 x 125.3 x 5.20 mm

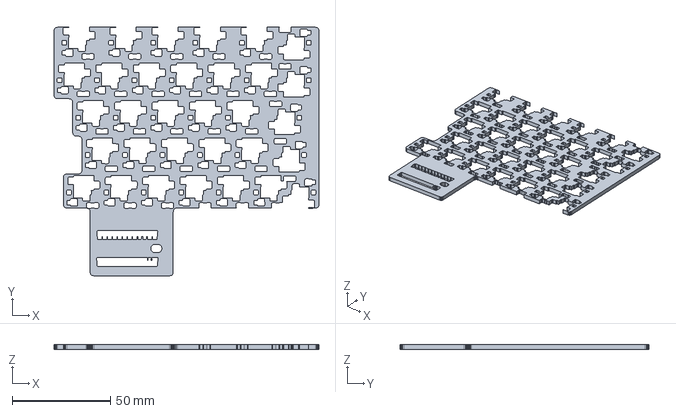
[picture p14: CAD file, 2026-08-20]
hardware/case/draft/x3-v2/kc2_left_x3_v2_lower_housing.step
134.9 x 126.6 x 2.50 mm

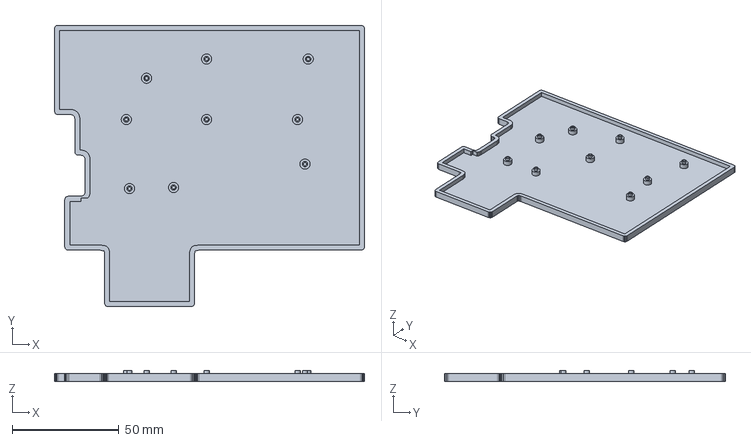
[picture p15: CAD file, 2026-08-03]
hardware/case/kc2_left_lower_housing.step
145.5 x 132.1 x 5.10 mm

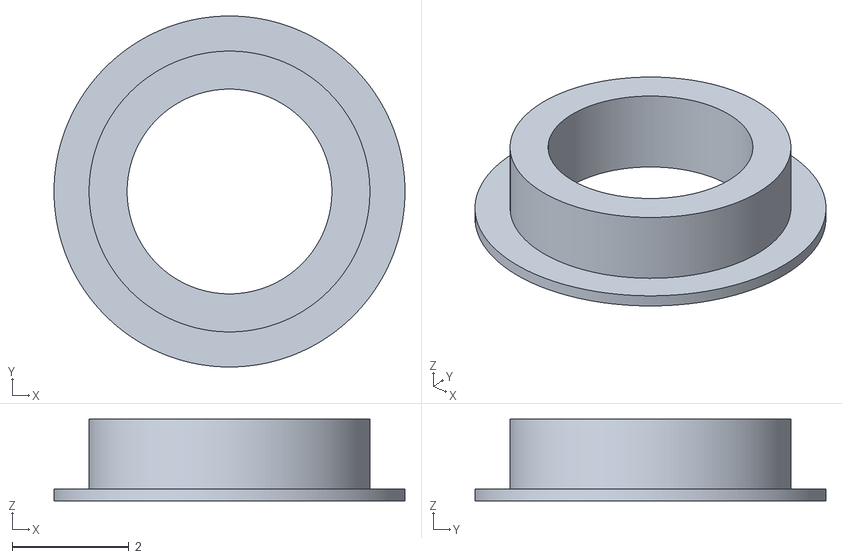
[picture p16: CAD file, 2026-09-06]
hardware/MODELS/adapters/kc2_v1_ring_cap_020.stl
6.00 x 6.00 x 1.40

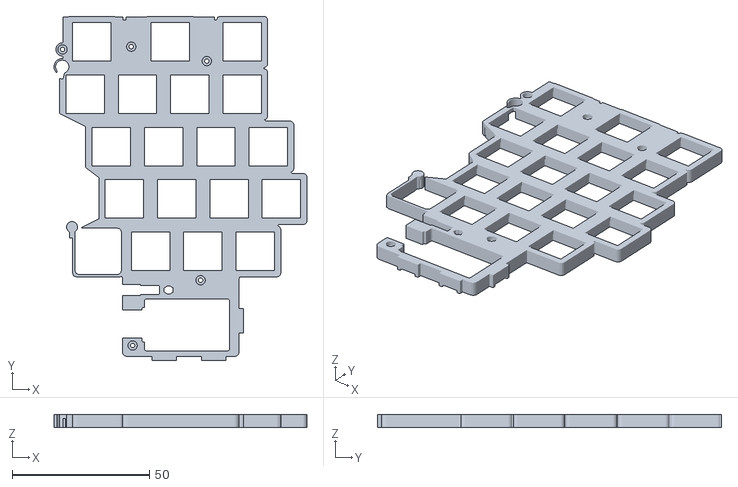
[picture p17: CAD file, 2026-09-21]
hardware/MODELS/kc2_right_mx_upper_housing_part_b.stl
92.1 x 125.3 x 4.90

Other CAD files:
docs/reports/registered-housing-fit-20260913/evidence/lower-development/left-central-inputs/left-normal/kc2_left_lower_housing.stl
docs/reports/registered-housing-fit-20260913/evidence/lower/left-magnetic/kc2_left_lower_housing_magnetic.native-readback.step
docs/reports/registered-housing-fit-20260913/evidence/lower/left-normal/kc2_left_lower_housing.native-readback.step
docs/reports/registered-housing-fit-20260913/evidence/lower/right-normal/kc2_right_lower_housing.native-readback.step
docs/reports/wrap-housings-20260920/lower/left-normal/kc2_left_lower_housing.native-readback.step
docs/reports/wrap-housings-20260920/lower/right-normal/kc2_right_lower_housing.native-readback.step
hardware/MODELS/STL_FROM_FUSION_20260921/kc2_left_lower_housing.stl
docs/reports/local-covers-20260910/native-check-left_lower.step
docs/reports/local-covers-20260910/native-check-left_lower_magnetic.step
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

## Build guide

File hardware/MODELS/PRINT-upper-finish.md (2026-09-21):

# 상판 내부 틈·공면 하부 개정 인쇄 안내

요구사항: `CON-ARCH-006`, `OPS-ARCH-006`.

게시 완료 여부는 `kc2_upper_finish_manifest.json`과 아래 명령으로 확인합니다.
manifest가 없거나 검증이 실패하면 새 상판 게시가 아직 끝나지 않은 상태입니다.

```powershell
python -B -m tools.publish_kc2_upper_finish
```

MX, Choc V1, Deep Sea Mini 상판을 함께 수정했습니다. 외벽 안쪽의 닫힌 비기능
틈만 연속 재료로 메웠고, 스위치·소켓·나사·서비스·상하판 결합 공간은 보호했습니다.
오른쪽 중앙 A/B 분할 간격은 필요한 기능 공간이므로 유지합니다.

기존 상판은 나사 랜드만 `Z=4.10..4.40`으로 0.30 mm 내려와 있었습니다. 새 상판은
그 국부 하향 돌출을 제거하여 모든 상판 부품의 최저면을 `Z=4.40` 하나로 맞췄습니다.
재료를 아래로 덧붙이지 않았습니다. `Z=4.40` 위의 넓은 나사 보스와 관통 보어는
변경하지 않았습니다.

## 인쇄 파일 선택

파일은 `hardware/MODELS` 바로 아래에 있습니다. 상판 한 종류와 하판 한 종류를
선택하고, 각 손의 왼쪽 한 파일과 오른쪽 A/B 두 파일을 각각 한 개 인쇄합니다.

| 부품 | 왼쪽 | 오른쪽 A | 오른쪽 B |
|---|---|---|---|
| MX 상판 | `kc2_left_mx_upper_housing.stl` | `kc2_right_mx_upper_housing_part_a.stl` | `kc2_right_mx_upper_housing_part_b.stl` |
| Choc V1 상판 | `kc2_left_choc_v1_upper_housing.stl` | `kc2_right_choc_v1_upper_housing_part_a.stl` | `kc2_right_choc_v1_upper_housing_part_b.stl` |
| Deep Sea Mini 상판 | `kc2_left_deep_sea_upper_housing.stl` | `kc2_right_deep_sea_upper_housing_part_a.stl` | `kc2_right_deep_sea_upper_housing_part_b.stl` |
| 일반 하판 | `kc2_left_lower_housing.stl` | `kc2_right_lower_housing_part_a.stl` | `kc2_right_lower_housing_part_b.stl` |
| 자석형 하판 | `kc2_left_lower_housing_magnetic.stl` | `kc2_right_lower_housing_part_a_magnetic.stl` | `kc2_right_lower_housing_part_b_magnetic.stl` |

상판은 `Z=4.40` 공면이 베드에 닿도록 놓는 방향을 권장합니다. 단위는 mm, 배율은
100%입니다. 오른쪽 STEP/F3D에는 A/B 두 몸체가 들어 있으므로 150 mm 프린터에서는
분리된 A/B STL을 사용합니다.

디지털 검증은 실제 프린터의 첫 레이어 접착, 수축·팽창, 나사 토크, 장기 강도와
실장 PCB의 최종 조립 감각을 확정하지 않습니다. 먼저 한 조합을 시험 출력하십시오.
이전 `PRINT-wall-gap-fix.md`와 그 manifest는 이번 공면 개정 전 이력입니다.

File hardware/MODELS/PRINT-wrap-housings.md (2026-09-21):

# PCB 위로 올라오는 연속 외벽 — 인쇄·조립 안내

> 이 문서는 틈 보강 이전 형상의 이력입니다. 후속 개정은 [틈 보강 안내](PRINT-wall-gap-fix.md)를 따르십시오. 후속 manifest 검증이 통과하기 전에는 인쇄를 보류합니다. 아래 검증은 이전 개정만 확인하며 새 canonical 파일의 검증을 대체하지 않습니다.

<!-- kc2-wrap-guide: ready -->

요구사항: `CON-ARCH-006`, `CON-ARCH-007`, `OPS-ARCH-006`.

현재 외벽 개정은 `kc2_wrap_housing_manifest.json`으로 식별합니다.
파일명이 이전과 같으므로, 아래 검증이 통과한 파일만 시험 인쇄하십시오.
manifest가 없거나 검증이 실패하면 인쇄를 보류합니다. 실물 끼움·강도 합격은 별도입니다.

```powershell
python -B -m tools.publish_kc2_wrap_housings
```

저장소 루트에서 실행합니다. 검증에는 Git 기준 커밋과 게시된 검증 자료가 필요합니다.
`.codex-tmp`는 배포 위치가 아닙니다. 이전 smooth-central/registered 검증 결과를
이번 외벽 개정의 합격 증거로 대신 사용하지 않습니다.

## 달라진 구조

PCB는 기존 하판 받침에 올립니다. PCB 바닥 Z2.50, 두께 1.60 mm, 윗면 Z4.10은 그대로입니다.
새 외벽 상단은 Z5.60으로 PCB 윗면보다 **1.50 mm 높고**, 상판 아래쪽과 **1.20 mm 겹칩니다**.
외벽은 상판 전체 높이를 감싸는 형태가 아닙니다. 기존 세 개의 짧은 위치맞춤 돌기만으로
정렬하는 구조에 연속 외벽을 추가한 것입니다.

새 벽 두께는 1.20 mm, 새 외벽과 대응 외곽의 명목 한쪽 여유는 0.30 mm입니다.
기존 위치맞춤 돌기와 홈의 국소 여유 0.25 mm는 별도입니다. 상판 외곽뿐 아니라
실제 PCB 윤곽과 명목 키캡 외형을 함께 고려하여 새 벽을 배치했습니다.
1.20 mm는 하판의 새 외벽 두께입니다. 상판에 추가된 외곽 립의 두께가 모두
1.20 mm라는 뜻은 아닙니다. 실제 왼쪽 MX의 Y80 mm 단면에는 약 0.90 mm 립이
있으며, 기존 상판 재료는 유지됩니다. 이 립과 연결부의 슬라이서 경로·출력 강도를
확인하십시오. 단일 솔리드와 간섭 검사 통과를 실제 강도 합격으로 간주하지 않습니다.
새 상판과 하판을 함께 사용하고 구형 인쇄물과 섞지 마십시오.

중앙 맞댐면은 반대쪽 하우징과 가까운 구간에서 높은 새 벽을 생략합니다.
USB·전원·리셋 등 필요한 서비스 개구부도 남깁니다. 따라서 문자 그대로 사방이
완전히 닫힌 테두리는 아닙니다. 기존 강화 소켓 가림벽, 나사 받침, PCB 지지점은 유지합니다.
좌우 전체 키보드 사이에는 새 잠금 요철을 만들지 않습니다.

## 인쇄 파일 선택

아래 표의 상판 중 한 행, 하판 중 한 행을 선택해 각 파일을 한 개씩 인쇄합니다.
총 여섯 개입니다. 파일은 모두 이 디렉터리에 바로 있습니다.

| 상판 | 왼쪽 | 오른쪽 A | 오른쪽 B |
|---|---|---|---|
| MX | [STL](kc2_left_mx_upper_housing.stl) | [STL](kc2_right_mx_upper_housing_part_a.stl) | [STL](kc2_right_mx_upper_housing_part_b.stl) |
| Choc V1 | [STL](kc2_left_choc_v1_upper_housing.stl) | [STL](kc2_right_choc_v1_upper_housing_part_a.stl) | [STL](kc2_right_choc_v1_upper_housing_part_b.stl) |
| Deep Sea Mini | [STL](kc2_left_deep_sea_upper_housing.stl) | [STL](kc2_right_deep_sea_upper_housing_part_a.stl) | [STL](kc2_right_deep_sea_upper_housing_part_b.stl) |

| 하판 | 왼쪽 | 오른쪽 A | 오른쪽 B |
|---|---|---|---|
| 일반형 | [STL](kc2_left_lower_housing.stl) | [STL](kc2_right_lower_housing_part_a.stl) | [STL](kc2_right_lower_housing_part_b.stl) |
| 자석형 | [STL](kc2_left_lower_housing_magnetic.stl) | [STL](kc2_right_lower_housing_part_a_magnetic.stl) | [STL](kc2_right_lower_housing_part_b_magnetic.stl) |

STEP/F3D는 확인·편집용입니다. 오른쪽 STEP/F3D는 두 몸체를 포함하므로 150 mm 프린터에서는
A/B로 분리된 STL을 사용합니다. 기존 [링 어댑터 안내](adapters/README.md)는 유지합니다.
STEP는 형상 토큰을 바꾸지 않고 줄 끝 공백만 정리했습니다. 검증에 사용한 원본 STEP와
Fusion 재열기 STEP는 보고서에 별도로 보관하며 manifest가 원본과 편집용 파일을 연결합니다.
Choc V1은 기존 0.20 mm 테두리 링을 사용하는 높이 조건을 유지합니다.
`deep_sea`는 저상형 Deep Sea Mini 가족 도면 기준이며 일반 높이 Deep Sea Box용이 아닙니다.
수령 갈축 로트와 가족 도면의 동일성은 아직 실측 확인되지 않았습니다.

## 출력과 조립

- 단위 mm, 배율 100%. 전체 크기를 줄여 끼움을 조정하지 마십시오.
- 하판은 평평한 바닥면을 베드에 놓습니다. 외벽의 실제 연속 경로와 자석 입구 등의 브리지를 슬라이서에서 확인합니다.
- 상판은 넓은 판 윗면을 아래로 놓는 방향을 검토합니다. V1/Deep Sea의 나사 보스는 판보다 각각 0.10/0.35 mm 높으므로 공중에서 시작하는 판 부분의 지지가 필요할 수 있습니다.
- 내부까지 채운 출력을 원하면 100% 인필을 사용하고 실제 경로를 확인합니다. CAD 솔리드라는 사실만으로 인필이 자동으로 100%가 되지는 않습니다.
- 오른쪽 A/B는 기존 맞물림 위치에 맞춰 Z 방향으로 조립합니다. 명목 분할 여유는 약 0.40 mm이며 좌우 전체 키보드의 중앙 맞댐 간격과는 다릅니다.
- PCB를 받침에 올린 뒤 상판을 수직으로 내려 외벽 안쪽에 맞춥니다. 들뜸이 남으면 첫 층 눌림·실뭉침·부품·배선을 확인하고, 나사 힘으로 강제로 끌어당기지 않습니다.

MX 나사는 명목 M1.4×7.50 mm, 저상형은 M1.4×5.00 mm이며 길이는 머리 아래부터 측정합니다.
통과 홀 Ø1.60 mm, 머리 포켓 Ø3.40 mm, 설계 머리 범위는 최대 Ø3.00×높이 1.20 mm입니다.
MX용 긴 나사를 저상형에 사용하지 마십시오.

자석형은 기존 두 쌍만 유지합니다. 자석은 Ø2.00×두께 1.00 mm, 원래 블라인드 홈은
Ø2.40×깊이 1.20 mm입니다. 외부 접근 통로와 원래 홈을 혼동하지 말고 안쪽 홈에 안착시킵니다.
컨트롤러 쪽 세 번째 자석은 없습니다. 접착 전에 좌우 극성을 확인합니다.

디지털 검증은 실제 출력물의 끼움·강도·피로·나사 토크·자석 흡착력 보증이 아닙니다.
구매 부품과 납땜 돌출, 배선, 키캡 전체 눌림, USB/PWR/RST 접근은 조립 후 직접 확인합니다.
실리콘 발은 사용자 지시에 따라 이번 검토에서 제외합니다. 주문된 PCB와 거버는 변경하지 않습니다.

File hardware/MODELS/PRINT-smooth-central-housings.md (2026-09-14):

# 중앙 요철 자리를 메운 최신 하판

요구사항: `CON-ARCH-006`, `CON-ARCH-007`, `OPS-ARCH-006`.

기존 요철 중심 Y=95,117 mm에서 남아 있던 파임을 메웠습니다. 주변과 같은 외벽 두께 1.20 mm, 바닥 Z=-2.20..-1.00 mm를 사용하여 요철 자리가 매끄럽게 이어집니다. 벽 밖으로 돌출시키거나 좌우 위치를 바꾸지 않았습니다.

하판은 아래 두 종류 중 하나의 세 파일을 인쇄하십시오. 모두 이 디렉터리에 있습니다.

| 종류 | 왼쪽 | 오른쪽 A | 오른쪽 B |
|---|---|---|---|
| 일반형 | [STL](kc2_left_lower_housing.stl) | [STL](kc2_right_lower_housing_part_a.stl) | [STL](kc2_right_lower_housing_part_b.stl) |
| 자석형 | [STL](kc2_left_lower_housing_magnetic.stl) | [STL](kc2_right_lower_housing_part_a_magnetic.stl) | [STL](kc2_right_lower_housing_part_b_magnetic.stl) |

자석형은 기존 두 쌍(Y=103,111 mm), Ø2 mm × 1 mm 자석과 Ø2.4 mm × 1.2 mm 홈을 사용합니다. 컨트롤러 쪽 세 번째 홈은 없습니다. 접착 전에 좌우 극성을 맞추십시오.

단위 mm, 배율 100%, 평평한 바닥면을 베드에 놓습니다. 상판은 기존 MX/Choc V1/Deep Sea Mini 중 실제 스위치에 맞는 종류를 사용합니다. PCB는 하판 받침 위에 올립니다. 상판별 나사·출력 조건은 [상판 조립 안내](PRINT-registered-housings.md)를 참고하되 하판 파일과 현재 검증은 이 문서를 따르십시오.

```powershell
python -B -m tools.publish_kc2_smooth_central_seam --verify
```

상태는 `digitally_verified_physical_pending`입니다. 실제 출력 강도와 끼움·자석 고정력은 출력 후 확인해야 합니다.

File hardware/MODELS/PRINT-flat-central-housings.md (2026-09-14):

# 평평한 중앙 이음 하우징 인쇄 안내

요구사항: `CON-ARCH-006`, `CON-ARCH-007`, `OPS-ARCH-006`.

## 이번 개정

- 좌우 키보드 중앙 이음의 요철 두 쌍(`Y=95, 117 mm`)을 일반형·자석형 하판에서 모두 제거했습니다.
- 중앙 면은 잠금이나 억지 끼움이 없는 평평한 비접촉 면입니다.
- 기존 소켓 가림벽, PCB 받침, 바닥, 70개 키 지지부, 17개 나사 위치, 우측 A/B 결합부와 상·하판 위치맞춤 구조는 유지했습니다.
- 자석형의 기존 두 자석 쌍(`Y=103, 111 mm`)은 그대로입니다.
- 컨트롤러 쪽 세 번째 자석 쌍은 추가하지 않았습니다. 가장 가까운 후보도 필요한 잔여 재료가 부족했고, 안전한 후보는 자석 면 사이가 약 `31.91 mm`라 실질적인 흡착 위치가 아니었습니다. 벽 확장은 사용자가 금지했으므로 무리하게 넣지 않았습니다.

## 인쇄 파일

하판은 일반형 또는 자석형 중 하나만 인쇄합니다.

| 종류 | 왼쪽 1개 | 오른쪽 2개 |
|---|---|---|
| 일반형 | `kc2_left_lower_housing.stl` | `kc2_right_lower_housing_part_a.stl`, `kc2_right_lower_housing_part_b.stl` |
| 자석형 | `kc2_left_lower_housing_magnetic.stl` | `kc2_right_lower_housing_part_a_magnetic.stl`, `kc2_right_lower_housing_part_b_magnetic.stl` |

상판은 실제 스위치에 맞춰 MX, Choc V1, Deep Sea Mini 중 하나만 고릅니다. 오른쪽은 항상 A/B 두 STL을 인쇄합니다.

## 기본 설정과 조립 확인

- 단위 mm, 배율 100%로 슬라이싱합니다.
- 오른쪽 A/B는 서로 다른 부품이므로 각각 평평한 바닥면을 베드에 놓습니다.
- 중앙의 평평한 면을 서포트처럼 인식해 얇은 구조가 생기지 않는지 미리보기를 확인합니다.
- 자석형은 지름 2 mm, 두께 1 mm 원통형 자석을 기존 지름 2.4 mm, 깊이 1.2 mm 홈에 접착 고정합니다. 좌우 극성을 먼저 맞춥니다.
- 세 번째 자석 홈을 수작업으로 추가하거나 기존 홈을 넓히지 마십시오.
- PCB를 하판 받침 위에 올린 뒤 선택한 상판을 덮고 지정 나사를 조입니다. 나사로 억지 정렬하지 마십시오.
- 처음에는 시험 출력으로 중앙 간격, 오른쪽 A/B 결합, PCB 안착, 소켓·배선 간섭을 확인합니다.

검증 명령:

```powershell
python -B -m tools.publish_kc2_flat_central_housings --verify hardware/MODELS/kc2_flat_central_housing_manifest.json
```

현재 manifest의 상태는 `digitally_verified_physical_pending`입니다. 출력 팽창·수축, 자석 유지력과 실제 조립 감각은 시험 출력 후 확인해야 합니다.

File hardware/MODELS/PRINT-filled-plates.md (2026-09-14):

# Superseded housing guide

Use [the current registered-housing guide](PRINT-registered-housings.md).

This guide is not current verification evidence. Historical content: Git 5b99bcb4567ea1c6bb4f17e54887d4de7614cd03:hardware/MODELS/PRINT-filled-plates.md.

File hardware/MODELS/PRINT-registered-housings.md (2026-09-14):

# 위치맞춤 외벽 하우징 — 인쇄·조립 안내

요구사항: `CON-ARCH-006`, `CON-ARCH-007`, `OPS-ARCH-006`.
인쇄 전에 아래 검증을 통과해야 합니다. manifest가 없거나 검증이 실패하면 게시가 완료되지 않았거나 파일이 변경된 것이므로 인쇄를 보류하세요. 디지털 검증은 출력물의 실제 끼움·강도 승인이 아닙니다.

```powershell
python -B -m tools.publish_kc2_registered_housings --verify hardware/MODELS/kc2_registered_housing_manifest.json
```

저장소 루트에서 실행합니다. 과거 원본의 바이트를 확인하므로 Git 저장소와 기준 커밋 `5b99bcb4567ea1c6bb4f17e54887d4de7614cd03`의 객체가 필요합니다. 현재 파일과 검증 자료가 있으면 `.codex-tmp` 없이 검증할 수 있습니다.

Python 3.12를 사용합니다. 전체 CAD 검사·회귀시험의 의존성은 저장소 `requirements-cad.txt`를 참고하세요. 검증 환경에 필요한 의존성이 없으면 이를 건너뛰어 합격으로 간주하지 마세요. CAD를 다시 생성할 때는 [격리 재생성 절차](../../docs/reports/registered-housing-fit-20260913/REPRODUCE.md)를 따르세요. 게시 후 메인 폴더에서 생성기를 바로 실행하면 새 모델을 구형 기준 입력으로 잘못 사용할 수 있습니다.

게시된 편집용 STEP는 구문 밖의 줄 끝 공백만 정리한 파일입니다. 검증 당시의 원본 STEP는 증거 폴더의 `.step.raw`로, Fusion 재출력본도 원래 바이트 그대로 보존합니다. 검증 명령은 원본에서 게시본을 다시 계산해 숫자·문자열·주석·줄바꿈이 바뀌지 않았는지 확인합니다. `.raw`는 인쇄 파일이나 별도 활성 모델이 아닙니다.

## 부품 선택

상판은 MX, Choc V1, Deep Sea Mini 중 실제 스위치에 맞는 한 종류만 선택합니다. 각 종류의 왼쪽 STL 한 개와 오른쪽 `part_a`, `part_b` STL 각 한 개를 인쇄합니다. 하판은 무자석 또는 파일명에 `magnetic`이 있는 자석형 중 한 종류를 선택하여 같은 방식으로 세 개를 인쇄합니다. 총 상판 세 개와 하판 세 개입니다. 새 상판과 새 하판을 함께 사용하고 구형 부품을 섞지 마세요.

최종 게시 위치는 `hardware/MODELS`입니다. `.step`과 `.f3d`는 확인·편집용이며 오른쪽은 두 솔리드를 포함합니다. 150 mm 프린터에서는 반드시 분할 STL을 사용하세요. PCB와 이미 주문한 거버는 변경하지 않습니다.

`deep_sea`는 저상형 Deep Sea Mini 가족 도면 기준이며 일반 높이 Deep Sea Box용이 아닙니다. 구매 갈축 로트와 도면의 동일성은 아직 확인되지 않았습니다. Choc V1의 기존 0.20 mm 테두리 링 조건과 어댑터 안내는 유지합니다.

## 외벽과 조립

PCB는 종전처럼 하판 받침 위에 올립니다. PCB 바닥 Z2.50, 윗면 Z4.10이며, 외벽에 PCB를 압입하는 구조가 아닙니다. 기존 강화 소켓 가림벽을 유지합니다. 새 일반 외벽 상단은 Z4.10이고 넓은 상판 밑면 Z4.40과 명목 0.30 mm 여유가 있습니다.

각측 세 곳의 위치맞춤 돌기는 Z5.00까지 올라가며 상판의 외측 개방 홈에 들어갑니다. 홈 천장은 Z5.20, 안쪽면·양끝 여유는 한쪽 0.25 mm입니다. 돌기가 나사를 조이기 전 위치를 잡아주지만 나사 체결을 대신하지 않습니다. 중앙에는 위치맞춤 홈을 두지 않습니다. 공간이 부족한 중앙 세 구간에서는 새 상승벽만 국소 생략하고 기존 소켓 가림을 남깁니다.

오른쪽 A/B는 XY 방향으로 강제로 밀어 끼우지 말고 서로 맞물리는 위치에 높이를 달리해 놓은 뒤 Z 방향으로 내려 조립합니다. 명목 분할 여유는 약 0.40 mm입니다. 상판 맞물림은 머리 Ø4.00/목 2.00 mm, 하판은 머리 Ø4.50/목 2.00 mm입니다. 이는 좌우 키보드를 붙이는 중앙 결합부와 다른 구조·공차입니다.

오른쪽 하판의 두 결합부는 두께 1.20 mm의 바닥 구간에서 맞물립니다. 수용부 주위의 바닥 재료 폭은 1.20 mm를 확보하고, 그 위의 부러지기 쉬운 얇은 끝부분은 반경 0.60 mm 기준으로 정리합니다. 위쪽을 빈틈없이 압입시키는 구조가 아닙니다. 바닥 결합부의 실제 강도와 첫 층 눌림에 따른 끼움은 시험 출력으로 확인하고, 걸리지 않는다고 나사로 억지로 당기지 마세요.

0.40 mm는 상대 슬롯의 명목 여유이며 모든 모서리 틈의 균일한 최대 폭이 아닙니다. 현재 MX 실제 CAD 검증에서는 최소 간격 약 0.40003 mm와 요철 연결 모서리의 국소 틈 약 0.525 mm를 확인했습니다. 이 국소 수치를 V1/Deep Sea의 실측값으로 확대 적용하지 않습니다. 실제 출력물의 마찰과 끼움 감촉은 별도 확인 대상입니다.

좌우 전체 키보드는 중앙의 안내 혀 두 곳을 맞춰 수평으로 접근시킵니다. 중앙은 잠금 장치가 아니라 분리 가능한 국소 접촉 구조입니다. 끝부분의 명목 접촉량 0.02 mm는 실제 끼움 힘을 보증하는 값이 아닙니다. 출력 편차에 따라 헐겁거나 빡빡할 수 있으므로 힘으로 밀어 넣지 마세요.

왼쪽의 새 외벽·바닥 추가분도 오른쪽 안내부를 피하도록 국소적으로 비워 둡니다. 기존 소켓 가림벽과 안내 혀는 유지합니다. 안내 혀 부근의 명목 주행 간격은 0.15 mm이고, 그 밖의 새 바닥과 상대 받침 사이에는 0.30 mm 여유를 둡니다. 모든 부위의 간격이 0.30 mm라는 의미는 아닙니다.

## 출력과 물리 확인

- 단위 mm, 배율 100%. 전체 축척을 줄이면 스위치와 나사 위치가 PCB와 달라집니다.
- 하판은 평평한 바닥을 아래로 놓습니다. 새 중앙 탄성부의 빈 공간은 의도된 공간이므로 인필이나 접착제로 메우지 마세요.
- 왼쪽과 오른쪽 모두 중앙 두 곳에 길이 5.70 mm의 국소 브리지가 있습니다. 왼쪽의 남은 윗벽은 명목 폭 1.20 mm·높이 2.30 mm입니다. 해당 브리지와 탄성부 주변의 실제 슬라이서 경로를 확인해야 합니다. 지지 없이 반드시 인쇄된다는 보증은 아닙니다.
- 상판은 넓은 판 윗면을 아래로 놓는 방향을 검토합니다. V1 나사 보스는 판보다 0.10 mm, Deep Sea 보스는 0.35 mm 높아 뒤집었을 때 판 밑에 얕은 공중 시작 영역이 생깁니다. 빌드플레이트 연결 서포트 등으로 첫 층부터 지지되는지 확인하세요.
- 명목 1.20 mm 가림벽에 실제 연속 경로가 충분히 생성되는지 확인합니다. CAD가 솔리드여도 슬라이서는 인필을 만들 수 있으므로 내부까지 꽉 채운 출력물이 목적이라면 100% 인필을 사용하고 실제 경로를 별도로 확인하세요.
- 첫 층 눌림, 실뭉침, 브리지 처짐은 결합을 막을 수 있습니다. 중앙 끼움·A/B·위치맞춤 홈과 자석 입구를 먼저 시험 출력하여 확인하는 것이 좋습니다. 디지털 검증만으로 재료 강도·마찰·피로·흡착력은 확정할 수 없습니다.

## 나사와 자석

MX는 명목 M1.4×7.50 mm, 저상형은 M1.4×5.00 mm입니다. 길이는 머리 아래부터 측정합니다. MX 나사를 저상형에 사용하지 마세요. 통과 홀 Ø1.60 mm, 머리 포켓 Ø3.40 mm이며 설계 머리 범위는 최대 Ø3.00×높이 1.20 mm입니다. 나사 힘으로 들뜸이나 휨을 눌러 맞추지 마세요.

자석형은 Ø2×두께 1 mm 원통 자석용 기존 Ø2.40×깊이 1.20 mm 홈을 유지합니다. 새 외벽에 동축 Ø2.40 mm 삽입 통로를 추가하므로 바깥 입구에서 홈 뒷면까지는 2.80 mm입니다. 이 값은 자석을 받는 기존 홈 자체의 깊이와 다릅니다. 자석은 새 외벽의 통로를 지나 원래 안쪽 블라인드 홈에 안착시켜야 하며, 새 바깥 통로에 고정하지 마세요. 좌우 자석 극성을 먼저 확인하고 실제 끼움·접착·흡착력은 출력 후 확인하세요. 무자석형에는 삽입 통로가 없습니다.

기존 안쪽 홈에 두께 1.00 mm 자석을 깊이 1.20 mm까지 안착시키면 좌우 자석의 마주 보는 면 사이 명목 간격은 4.40 mm입니다. 새 외벽 사이의 0.80 mm 간격과는 다릅니다. 접착층과 실제 치수 편차는 이 명목값에 포함되지 않으며, 외벽이 가까워졌다고 흡착력이 강해졌다는 뜻은 아닙니다. 간격을 줄이려고 자석을 바깥 통로로 옮겨 고정하지 마세요.

실리콘 발의 배치와 접착 검토는 사용자 지시에 따라 이번 작업에서 보류했습니다.

조립 후 PCB 받침 접촉, 스위치 완전 안착·클립, 전원/리셋/USB 접근, 모든 키캡의 완전 눌림과 나사 머리 간섭을 직접 확인해야 합니다. 실제 납땜 돌출, 배선, 구매 부품 편차, 체결 토크 및 RF는 별도 물리 확인 대상입니다.

## 정확한 인쇄 파일

상판은 아래 표에서 한 행만 선택해 각 파일을 한 개씩 인쇄합니다.

| 스위치 | 왼쪽 | 오른쪽 A | 오른쪽 B |
|---|---|---|---|
| MX | [STL](kc2_left_mx_upper_housing.stl) | [STL](kc2_right_mx_upper_housing_part_a.stl) | [STL](kc2_right_mx_upper_housing_part_b.stl) |
| Choc V1 | [STL](kc2_left_choc_v1_upper_housing.stl) | [STL](kc2_right_choc_v1_upper_housing_part_a.stl) | [STL](kc2_right_choc_v1_upper_housing_part_b.stl) |
| Deep Sea Mini | [STL](kc2_left_deep_sea_upper_housing.stl) | [STL](kc2_right_deep_sea_upper_housing_part_a.stl) | [STL](kc2_right_deep_sea_upper_housing_part_b.stl) |

하판도 한 행만 선택합니다. 무자석형과 자석형을 혼용하지 마세요.

| 하판 | 왼쪽 | 오른쪽 A | 오른쪽 B |
|---|---|---|---|
| 무자석 | [STL](kc2_left_lower_housing.stl) | [STL](kc2_right_lower_housing_part_a.stl) | [STL](kc2_right_lower_housing_part_b.stl) |
| 자석형 | [STL](kc2_left_lower_housing_magnetic.stl) | [STL](kc2_right_lower_housing_part_a_magnetic.stl) | [STL](kc2_right_lower_housing_part_b_magnetic.stl) |

기존 [어댑터 인쇄 안내](adapters/README.md)를 확인하세요. 필요한 경우에만 [MX 링](adapters/kc2_mx_ring_cap_020.stl) 또는 [Choc V1 링](adapters/kc2_v1_ring_cap_020.stl)을 사용합니다. 기존 어댑터 파일은 이번 게시에서 변경하지 않습니다.

<!-- kc2-release-guide {"status":"final_release_payload","physical_qualified":false,"silicone_feet":"deferred_by_user","bridge_mm":5.7,"low_profile_plate_support_required":true,"scale_percent":100,"solid_print_infill_percent":100,"pcb_bottom_z_mm":2.5,"pcb_top_z_mm":4.1,"magnet_diameter_mm":2,"magnet_thickness_mm":1,"magnet_original_pocket_depth_mm":1.2,"magnet_external_seat_depth_mm":2.8} -->

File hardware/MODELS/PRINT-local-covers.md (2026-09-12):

# 보강된 국소 가림벽 하우징 인쇄·조립 안내

이 문서는 Git `d9d3729`의 이전 상판 개정 기록입니다. 현재 인쇄 파일 선택 및 검증은 [내부 충전형 안내](PRINT-filled-plates.md)를 사용하세요. 아래 이전 상판 검증 명령은 현행 충전형에 적용하지 않습니다.

요구사항: `CON-ARCH-006`, `CON-ARCH-007`, `OPS-ARCH-006`. 기준: 기존 r5 (`cc854a3`).

이 개정은 하판 위에 PCB를 올리는 기존 구조를 유지합니다. PCB를 새로운 외벽 안에 끼워 넣거나, 상판을 새 하판 벽에 안착시키는 구조가 아닙니다.
이전의 전체 외벽·확대된 좌우 간격 개정(`2268492`)은 철회됐습니다.

## 파일 확인

인쇄 전 저장소 루트에서 다음 검증이 통과해야 합니다. 게시 manifest가 없거나 실패하면 아직 최종 게시 전이거나 파일이 변경된 상태입니다.

```powershell
python -B -m tools.publish_kc2_local_covers --verify
```

검증은 설계 형상과 파일의 일치 여부를 확인합니다. 실제 출력 강도, 구매한 부품 및 키캡의 적합성은 별도 실물 확인이 필요합니다.

## 인쇄할 세트

하판은 무자석 또는 `_magnetic` 중 한 열만 골라 각 1개씩 인쇄합니다.

| 부품 | 무자석 | 자석 홈 |
|---|---|---|
| 왼쪽 하판 | [STL](kc2_left_lower_housing.stl) | [STL](kc2_left_lower_housing_magnetic.stl) |
| 오른쪽 하판 A | [STL](kc2_right_lower_housing_part_a.stl) | [STL](kc2_right_lower_housing_part_a_magnetic.stl) |
| 오른쪽 하판 B | [STL](kc2_right_lower_housing_part_b.stl) | [STL](kc2_right_lower_housing_part_b_magnetic.stl) |

공통 MX 상판은 다음 3개를 각 1개씩 사용합니다. 하판과 합쳐 6개입니다.

- [왼쪽 MX 상판](kc2_left_mx_upper_housing.stl)
- [오른쪽 MX 상판 A](kc2_right_mx_upper_housing_part_a.stl)
- [오른쪽 MX 상판 B](kc2_right_mx_upper_housing_part_b.stl)

STEP과 Fusion F3D는 편집·확인용입니다. 오른쪽 전체 STEP/F3D에는 분할된 두 솔리드가 들어 있으므로 150 mm 프린터에는 분할 STL을 사용합니다.

## 그대로 유지하는 조립 구조

- 바닥 두께 1.20 mm, 외면 Z−2.20 / 내면 Z−1.00 mm.
- 기존 받침 위 PCB 아래·위 면 Z2.50 / 4.10 mm.
- MX 보강판 아래·위 면 Z7.80 / 9.30 mm.
- 기존 70개 스위치 위치, 왼쪽 8개·오른쪽 9개 체결 위치와 나사 받침.
- 기존 좌우 결합 위치와 명목 중앙 키캡 간격 1.80 mm. 확대된 6.40 mm 간격은 사용하지 않습니다.
- 명목 M1.4×7.50 mm 나사. 8/9/10 mm로 임의 대체하지 않습니다.
- 기존 오른쪽 분할 이음과 여유. 가림부가 이음에 걸리는 곳도 분리해서 인쇄합니다.

하판의 가림 대상은 왼쪽 5곳·오른쪽 7곳의 소켓 측면 개구부입니다. 소켓·납땜 여유 공간을 채우지 않고, 그 바깥에 얇은 가림부를 더합니다. 하판 가림부는 PCB 받침 높이 Z2.50을 넘지 않습니다.
무자석/자석 버전 모두 같은 국소 가림부를 사용하며 기존 자석 홈은 유지합니다.

MX 상판에는 주변 스위치 옆의 노출 구간을 가리는 분절된 가림부가 달립니다. 하판의 12곳만 복제한 형상도, PCB·컨트롤러 전체를 감싸는 상자도 아닙니다. 가림부 아래 끝은 Z4.40으로 PCB 윗면에서 0.30 mm 떨어져 있고, 기존 나사 받침이 상판 높이를 결정합니다.
스위치 몸체를 피해야 하는 곳만 국소적으로 돌출되며, 돌출부 위에도 같은 높이의 얇은 지붕을 연결해 상판을 뒤집어 출력할 때 연결되지 않은 벽이 시작되지 않도록 합니다. 컨트롤러 방향과 기능·조립에 필요한 개구부는 남깁니다. 지붕·가림부와 실제 키캡 안쪽의 적합성은 실물 확인 대상입니다.

## 출력과 조립 시 주의

하판은 바닥 외면을 베드에 놓습니다. 상판은 보강판 윗면을 베드에 놓고 받침이 위를 향하도록 뒤집습니다. mm 단위·100% 배율로 출력하며 전체 크기를 늘려 공차를 맞추지 않습니다.

2026-09-13 개정: 기존 약 0.40 mm 가림벽이 실제 출력에서 쉽게 부러진다는 사용자 보고에 따라 가림벽의 명목 두께를 1.20 mm로 늘리고, 바닥·상판 연결부의 겹침 폭을 0.80 mm로 보강합니다. 무자석·자석 하판과 공통 MX 상판 모두 대상입니다. 기존 얇은 벽의 디지털 검사 통과는 실제 강도 검증이 아니었습니다.

슬라이서 층 미리보기에서 벽과 연결부가 생략되거나 끊어지지 않는지 확인하세요. 프린터·노즐·선폭·재료가 지정되지 않았으므로 강도나 출력 성공을 보증하지 않습니다. 보강 후에도 재출력·조립 강도 확인이 필요하며, 좌우를 억지로 압입하지 마세요.

보강 후 기존 좌우 결합 위치에서 하우징 전체 외곽의 계산상 최소 여유는 0.446 mm입니다. 오른쪽 A/B 분할부는 기존 명목 0.20 mm 여유(형상상 약 0.19976 mm)를 유지합니다. 이 수치는 프린터의 실제 치수 오차를 포함한 측정값이 아닙니다. 이번 연결부 보강은 가림벽과 바닥·상판의 접합부이며 A/B 맞물림 돌기 재설계는 포함하지 않습니다.

PCB 납땜은 하판 밖에서 합니다. 기존 조건대로 PCB 아래 핀·납·부품 돌출이 최대 2.90 mm 이내인지 실측하고, 몸체나 접점을 깎거나 배터리를 압축해 맞추지 않습니다.
하판에 PCB를 올리고 기존 받침에 제대로 닿는지 확인한 다음 MX 상판을 장착합니다. 틈이 맞지 않을 때 나사 힘으로 강제로 누르지 마세요.

자석은 Ø2×1 mm이며 기존 Ø2.4×깊이 1.2 mm 홈과 공차 시험편을 사용합니다. 극성·접착·흡착력·이탈 방지는 실제 출력물로 확인해야 합니다.
실리콘 발은 기존 평평한 바닥의 접착 위치에 붙이고 이음과 모서리를 피합니다.

키캡 전체 이동, 실제 헤더·케이블·배터리·배선 간섭, 나사 토크와 반복 조립, 출력 변형·강도, 자석 흡착력 및 RF는 실물 확인 항목입니다. PCB·주문된 거버는 변경하지 않으며 이번 하우징 개정은 새 PCB 제작 승인이 아닙니다.

서비스 접근 검사에서 새 가림벽이 추가하는 간섭과 기존 구조의 겹침을 구분합니다. 기존 상판 일부는 보수적으로 잡은 USB 케이블·전원 조작·리셋 도구 접근 영역과 겹칩니다. 따라서 기존 형상을 유지했다는 결과를 모든 케이블·손가락·도구가 자유롭게 접근한다는 보증으로 해석하지 마세요. 실제 부품과 도구로 조작성을 확인해야 합니다.

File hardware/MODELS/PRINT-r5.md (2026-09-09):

# 하판 연속 지지 구조 개정 — 2026-09-08

이 문서는 Git `cc854a3`의 과거 r5 형상 설명입니다. 현재 파일에는 국소 가림부가 추가되므로 [현재 인쇄 안내](PRINT-local-covers.md)를 우선합니다. 아래의 과거 검사 수치는 추가된 가림부의 검증을 뜻하지 않습니다.

요구사항: `CON-ARCH-006`, `OPS-ARCH-007`.

이 안내는 이전 r4 하판 설명을 대체합니다. 검사 결과는
[r5 검사 디렉토리](../../docs/reports/continuous-web-20260908-r5/)에 기록합니다.
최종 디지털 검사와 회귀 테스트 63개가 통과했습니다. 실제 부품·출력물의 물리적 적합성은 아래 조건을 확인해야 합니다.

## 변경 내용

바닥 위의 1 mm 빈 틈을 없애고 지지 구조 전체를 바닥에 연결합니다.
부품을 피하는 홈은 위로 열린 공간으로 남깁니다. 홈까지 전부 메우지는 않습니다.
바닥은 1.2 mm, 전체 하판 높이는 4.7 mm입니다.
PCB 받침 높이·나사 위치·공칭 M1.4×7.5 mm 나사는 그대로입니다.

## 인쇄

- [왼쪽 하판](kc2_left_lower_housing.stl): 1개.
- [오른쪽 하판 A](kc2_right_lower_housing_part_a.stl): 1개.
- [오른쪽 하판 B](kc2_right_lower_housing_part_b.stl): 1개.

각 파일은 바닥과 지지부가 합쳐진 한 덩어리입니다. 150 mm 인쇄 범위에 맞춘
기존 오른쪽 A/B 분할은 유지합니다. 오른쪽 전체를 단일 부품으로 바꾸지는 않았습니다.
평평한 바닥 외면을 베드에 놓고 mm 단위·100% 축척으로 인쇄합니다.
지지부 아래의 공중 틈을 위한 내부 서포트는 필요하지 않습니다.
접착·뒤틀림·강도·치수 오차는 프린터와 재료로 확인해야 합니다.
상판과 어댑터 선택은 [hardware 안내](../README.md)를 따릅니다.
하판 아래에는 기존 Ø8 mm 실리콘 발 접착 위치를 사용합니다.

## 실장 후 확인

PCB 아래 면에서 핀·납·부품의 돌출 길이는 최대 2.9 mm 이내여야 합니다.
이때 바닥까지 명목상 0.6 mm 여유가 있습니다. 실제 구매품 측정 결과가 아니라 조립 허용 한계입니다.
기능성 소켓·스위치 몸체를 깎거나 나사 힘으로 부품을 누르지 마세요.
납땜은 PCB를 하판에서 빼서 진행합니다.

MX hat 소켓과 Choc 소켓은 동일 키에 동시에 실장하지 않습니다.
정확한 배터리·헤더·배선·키캡 치수가 없는 부분은 실물 간섭 없음으로 보증하지 않습니다.
배터리와 배선을 핀·나사·하판 사이에 끼우지 말고 키캡은 끝까지 눌러 확인하세요.

## 주문 파일

`hardware/PCB`와 `hardware/GERBER`의 주문된 PCB는 변경하지 않습니다.
GERBER의 r4 봉인 검증은 당시 파일에 대한 기록이며 새 하판의 검증 기록이 아닙니다.
재주문이나 새 거버 패키지는 이 개정에 포함되지 않습니다.

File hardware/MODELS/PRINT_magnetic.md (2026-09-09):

# 자석 홈 옵션 — 무자석/자석 두 하판 옵션 유지

요구사항: `CON-ARCH-006`, `OPS-ARCH-006`. 2026-09-08.

자석은 원통형 **지름 2 mm × 두께 1 mm**, 좌우 각각 2개로 총 4개입니다.
자석 홈 자체는 기존 벽을 두껍게 하거나 외곽을 늘리지 않고 뺀 형상입니다. 2026-09-10 국소 가림부는 자석 홈과 떨어진 소켓 노출 구간에만 두 옵션 공통으로 추가합니다. [현재 인쇄 안내](PRINT-local-covers.md)와 게시 검증이 우선하며, 아래 과거 자석 검증만으로 새 가림부를 승인하지 않습니다.
자석 없는 파일과 `_magnetic` 파일 중 하판 한 세트만 선택하세요.

## 인쇄 파일

| 부품 | 무자석 옵션 | 자석 홈 옵션 |
|---|---|---|
| 왼쪽 하판 | [기존 STL](kc2_left_lower_housing.stl) | [magnetic STL](kc2_left_lower_housing_magnetic.stl) |
| 오른쪽 하판 A | [기존 STL](kc2_right_lower_housing_part_a.stl) | [magnetic STL](kc2_right_lower_housing_part_a_magnetic.stl) |
| 오른쪽 하판 B | [기존 STL](kc2_right_lower_housing_part_b.stl) | [magnetic STL](kc2_right_lower_housing_part_b_magnetic.stl) |

선택한 열의 하판 3개를 각각 1개 인쇄합니다. 오른쪽은 A/B를 조립합니다.
오른쪽 홈 2개는 B에 있으며 A는 같은 세트를 찾기 쉽도록 `_magnetic` 이름으로 제공합니다.
두 옵션의 MX 상판은 공통입니다. 아래 3개도 각각 1개 사용합니다.

- [왼쪽 MX 상판](kc2_left_mx_upper_housing.stl)
- [오른쪽 MX 상판 A](kc2_right_mx_upper_housing_part_a.stl)
- [오른쪽 MX 상판 B](kc2_right_mx_upper_housing_part_b.stl)

편집·확인용: [왼쪽 STEP](kc2_left_lower_housing_magnetic.step), [오른쪽 STEP](kc2_right_lower_housing_magnetic.step), [왼쪽 Fusion](kc2_left_lower_housing_magnetic.f3d), [오른쪽 Fusion](kc2_right_lower_housing_magnetic.f3d).
PCB와 주문한 거버는 변경하지 않았으며 재주문이 필요하지 않습니다.

## 홈 치수와 위치

| 항목 | 명목값 |
|---|---|
| 홈 지름 / 벽 안쪽 깊이 | Ø2.40 / 1.20 mm |
| 자석 대비 여유 | 지름 +0.40 mm(반경 +0.20 mm), 깊이 +0.20 mm |
| 홈 중심 간격 | 8.00 mm, 양쪽 각각 2개 |
| CAD 로컬 중심 | 왼쪽 X0.10, 오른쪽 X149.30; 양쪽 Y103.00 및111.00, Z0.75 mm |
| 홈 축 | 왼쪽은 +X, 오른쪽은 −X 방향으로 벽 안쪽 |
| 홈 위·아래 남는 지지부 | 각각 0.55 mm |
| 홈 뒤쪽 남는 플라스틱 | 최소 0.60 mm |
| 하판 바닥 두께 | 기존 1.20 mm 유지 |

좌표는 기존 STEP의 **X 반사된 하판 로컬 좌표**입니다. PCB 좌표와 혼동하지 마세요.
홈은 좌우 키보드 사이의 안쪽 벽에 있으며 오른쪽 A/B 퍼즐 연결부용이 아닙니다.
기존 위·아래 면, 나사홀과 지지대, 실리콘 발 접착면은 유지합니다.

## 출력·끼움 확인

먼저 [작은 공차 시험편 STL](kc2_magnet_fit_coupon_magnetic.stl)을 같은 재료·방향·설정으로 인쇄하세요.
시험편은 4 ×24 ×4.7 mm이며, 측면 구멍이 CAD +Y 순서로 Ø2.2 /2.3 /2.4 /2.5 mm입니다.
중심 Y는 각각4 /9 /14 /19 mm, 깊이는 모두1.2 mm입니다. 작은 지름 쪽을 베드에서 떼기 전에 펜으로 표시하면 구별하기 쉽습니다.
시험편 결과가 맞지 않으면 본체를 강제로 끼우거나 전체 배율을 바꾸지 말고 홈 치수를 재조정해야 합니다.

하판과 시험편 모두 평평한 바닥 외면을 베드에 놓고, **mm 단위·100% 축척**으로 출력합니다.
모델 바닥 Z는−2.2 mm이므로 슬라이서의 베드에 놓기 기능을 사용합니다. 모델을 뒤집어 홈 축을 수직으로 세우지 않습니다.
층 높이0.20 mm를 시작점으로 사용할 수 있지만 실제 프린터 설정은 시험편으로 확인하세요.
측면 원형 구멍 위쪽에는 최대2.4 mm 폭의 짧은 브리징/오버행이 생깁니다(시험편 최대2.5 mm).
슬라이서 층 미리보기에서 구멍이 막히지 않는지 확인하세요. 작은 막힌 홈에 제거 불가능한 서포트를 채우지 마세요.
이 홈의 출력성은 기존 무자석 r5의 연속 지지부 검증과 별개이며, 출력 성공을 보장한 상태는 아닙니다.

## 자석 조립과 흡착력 한계

두 평평한 원형 면이 N/S인 **두께 방향 착자** 자석을 사용하고, 마주 보는 좌우 자석의 극성이 서로 반대인지 접착 전에 확인하세요.
같은 2개짜리 극성 배치를 좌우에 무심코 복제하면 밀어낼 수 있습니다.
홈은 압입용이 아닙니다. 인쇄물과 자석 코팅에 적합한 접착제를 소량 사용하고 충분히 경화시킵니다.
자석이 안 들어가면 억지로 눌러 얇은 벽을 깨뜨리지 마세요. 접착 후 이탈 여부를 확인한 뒤 PCB를 올립니다.
떨어진 자석은 전도성 이물이 될 수 있으므로 전원 연결 전에 내부를 확인하고, 작은 자석은 어린이에게서 격리하세요.

현재 키 간격을 유지한 조립 위치에서 이 벽 사이 간격은 약4.0 mm입니다.
두께1.0 mm 자석을 깊이1.2 mm 홈 바닥에 붙이면 각 면이0.2 mm 들어가므로 자석 면 간격은 약**4.4 mm**입니다(접착제 두께 제외).
따라서 “착” 하고 강하게 붙거나 위치를 고정할 만큼의 힘은 보장하지 않습니다.
벽 두께·외곽을 늘리지 않는 조건을 우선했으며 실제 흡착력은 조립 시험이 필요합니다.

납땜·나사·실리콘 발·링 어댑터 주의사항은 [기존 r5 안내](PRINT-r5.md)를 함께 따르세요.
과거 자석 개정의 디지털 검증과 실물 미검증 항목은 [검증 보고서](../../docs/reports/magnetic-20260908/README.md)에 기록합니다. 새 가림부 검증은 [현재 기록](../../docs/reports/local-covers-20260910/README.md)을 확인하세요.

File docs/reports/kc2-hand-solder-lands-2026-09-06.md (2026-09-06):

# Enlarged hand-solder lands: partial implementation

Requirements: CON-ARCH-004 AC-3/AC-10; CON-ARCH-007 AC-2.

This is development evidence, not fabrication approval. All corresponding acceptance criteria remain open.

## Independent-review correction

The initial three-test PASS below was insufficient: creating the controller mutated KiCad's shared `LSET.AllCuMask()` value, which made subsequent in-process mask checks pass and caused wildcard serialization to omit explicit mask layers on saved PTHs. A fresh isolated process read the saved U1, POWER and battery pads with no mask openings. Treat the initial mask claim as disproven until saved-board fresh-process tests pass after repair.

The generator and MX updater now copy the copper layer set before adding mask layers. New tests first reproduced both static-set mutation and missing saved-board masks. PCB repair is restoring explicit masks along with route detours; current completion must be established from new reports, not the earlier test result.

Subsequent verification: all eight `tools.test_kc2_hand_solder_pads` tests now pass, including isolated-process reads of saved canonical U1 masks. The combined source-footprint, hand-solder, dimensional-manifest and MX-evidence tests ran 31 tests with an `OK` result (`.codex-tmp/mx-focused-regressions.log`). This restores confidence in the specific pad/mask checks; routing, housing support wear clearance and complete release verification remain unfinished.

The independent review also added a separate MX receptacle physical-evidence gate, integrated with typed hashed specification documents, actual switch/coupon identity, three-key/two-contact coverage, replacement-cycle records and numeric contact limits. Fifteen focused gate tests pass with synthetic test data only. No physical measurements have been supplied. The existing positive legacy physical fixture now fails because it lacks the new evidence; it is not valid receptacle qualification.

## Implemented geometry

Both canonical boards and their source footprints now use:

| Contact | Copper land (mm) | Drill (mm) | Mask |
|---|---|---|---|
| Controller U1, 24 per half | 1.80 x 2.40 oval | 0.95 | Explicit F.Mask and B.Mask, no paste |
| MX, two per key / 70 keys | 2.50 x 3.20 oval | 1.60 trial | Explicit F.Mask and B.Mask, no paste |

Oval elongation is footprint-local Y. Centers and net identities are unchanged. Duplicate-number Choc SMD contacts remain unchanged. The controller generator retains the enlarged lands and mask openings for x3-v2 only. Previously U1 pads specified copper layers without mask openings; copper enlargement alone would not correct that defect.

The selected socket nominal dimensions and qualification gates are recorded in CON-ARCH-004. The 1.60 mm hole is a coupon starting value, not a qualified finished plated-hole fit. CON-ARCH-007 now accounts for the reduced nominal battery-to-controller copper gap.

## Verification

Command: `"C:/Program Files/KiCad/10.0/bin/python.exe" -B -m unittest tools.test_kc2_hand_solder_pads`

Result: three tests pass. Tests were added before implementation and initially failed on the old pad sizes/mask layers. Coverage includes controller generation, controller source/placed pads, and all 70 switch locations plus source footprint. This does not verify routes, plotted mask output, physical fit or hand-solder performance.

KiCad 10 DRC with zone refill, exclusions included, save_board=false:

| Result | Left | Right |
|---|---:|---:|
| Shorting items | 8 | 10 |
| Copper clearance errors | 17 | 32 |
| Hole clearance errors | 0 | 1 |
| Library footprint mismatch warnings | 1 | 1 |
| Unconnected items | 0 | 0 |

Raw reports: `docs/reports/kc2-hand-solder-left-2026-09-06.drc.json` and `docs/reports/kc2-hand-solder-right-2026-09-06.drc.json`.

The enlarged pads intersect existing routes. These errors are unresolved. The earlier zero-error baseline does not apply to these modified boards. Project ignored checks are listed in the raw reports and are not manufacturing signoff.

## Remaining work

Repair affected routing and drill spacing; resolve library mismatches; rerun all electrical/net/physical-component checks and inspect mask plots. Qualify socket tolerances and MX blade contact on coupons, controller/switch solderability and battery insulation. Regenerate dependent artifacts only from a validated board. No new fabrication package was generated and no order approval is given.

Edit backups are beside the boards/controller libraries (`*.bak-20260906-*`) and in `.codex-tmp/*-before-mx-lands-*.kicad_pcb`.

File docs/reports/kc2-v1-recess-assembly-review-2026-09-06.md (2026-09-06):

# Revised assembly and 1:1 review

Requirements: `CON-ARCH-004`, `CON-ARCH-006`, `OPS-ARCH-007`.

This is an engineering review of the revised nominal assembly, not measured switch contact, printed strength, or universal keycap qualification. The final release must additionally bind passing current CAD/native/output evidence.

## Interfaces preserved

The regenerated `hardware/case/kc2_first_order_1to1_manifest.json` records the actual current PCB coordinates and raw source hashes. Both full-size SVGs were rasterized and visually inspected: 31/39 switch openings, 24 controller pins per half, 8/9 mounting centers and the enlarged locator circles align with the same board-coordinate datum. The drawings use physical millimetres and a 50 mm calibration line; print at 100%, without fit-to-page. This is digital scale/registration evidence, not a claim that a particular printer has been calibrated.

The central rings retain one 0.20 mm flange layer, 4.80 mm barrel OD, 6.00 mm cap OD and 1.20 mm barrel length. V1 bore is 3.50 mm, MX bore is 4.10 mm. The flange is printed on the bed; total height is 1.40 mm (seven 0.20 mm layers), with only the cap occupying one layer. The smaller V1 bore is conservative for the CAD ring-material collision envelope; saved mesh topology and dimensions are checked separately. Do not force a switch into a poorly printed bore.

V1 uses the bottom Choc socket and its appropriate central ring, not the MX retention plate. MX uses two individual hat receptacles and the MX plate-lid. Choc V2 is the separate bottom-socket assembly. These alternatives are mutually exclusive at each switch; one plate is not claimed to retain all three switch families. V1 locator clearance has been corrected on all70 switches; the ring alone could not correct the old locator-hole conflict.

## Recessed screw stack

The reviewed nominal section has PCB bottom/top at Z2.50/4.10 mm and plate top at Z9.30 mm. Each head pocket is diameter3.40 mm and depth1.50 mm, with bearing Z7.80 mm. A conservative diameter3.00 mm, height1.20 mm head occupies Z7.80..9.00, leaving0.30 mm below the plate top. Unlike r2, the head no longer projects above the plate. This removes that additional obstacle for caps that otherwise clear the plate; no unprovided cap underside or swept volume is invented.

Upper collars are diameter4.60 mm from Z5.30 mm, retaining the existing diameter3.00 mm PCB contact landing at Z4.10..5.30. The bearing floor is2.50 mm thick and the nominal pocket wall0.60 mm. These dimensions are not material-strength or torque measurements. The right upper seam locally reserves the entire MH8 collar, preserving both captive joints. The generated BRep section checks must show all17 head envelopes clear, full collar-wall sections and no enlarged PCB contact landing.

For this lower receiver, nominal under-head-to-entry span is5.30 mm. A7.50 mm under-head screw gives2.20 mm insertion into a2.80 mm blind pilot, leaving0.60 mm nominal tip reserve. The [Monotaro40411061 supplier table](https://www.monotaro.com/p/4041/1061/) specifies M1.4, pitch0.30 mm, length7.50 mm, head diameter2.50(+0.05/-0.10) mm and height0.70±0.05 mm. That head fits within the conservative modeled envelope. Length/point tolerance and printed thread retention are not supplied or measured. The former9 mm candidate is obsolete; do not substitute8/9/10 mm without recalculating the complete actual stack. Do not bottom screws or use torque to pull an obstructed stack together.

## Explicit remaining receipt checks

- Hat receptacle barrel/flange nominal dimensions are specified, but exact barrel tolerances, permissible flat blade dimensions, contact spring depth and insertion/removal forces are unknown. A compatibility label is not a contact datasheet.
- The selected TTC and Kailh seller variants lack a controlled exact-part drawing link; the manufacturer TTC listing has different force/travel figures and cannot supply tighter assumed tolerances. See `kc2-selected-component-source-closure-2026-09-06.md`.
- V1 nominal pin protrusion after a0.20 mm flange and1.60 mm PCB is0.85 mm. This is not proof of sufficient engagement with the socket spring. Check unpowered seating/contact before soldering the full assembly.
- Align receptacles with the actual intended switch and plate, tack one joint, allow cooling, and confirm straight seating and removal before completing joints. Avoid excess solder entering the open contact cavity. The three documented same-net exposed-via exceptions may wick solder; they are not electrical shorts and are not falsely called tented.
- Verify printed aperture/clip/ring dimensions, both split joints, insulation, actual screw tip reserve, full key travel, torque/retention,2 N deflection and long-term contact performance on received parts. Verify battery polarity and POWER/RESET continuity before energizing; do not bridge an unqualified charge-boost option.

The first lot remains a product lot with explicit rework risk under OPS-ARCH-007. These pending physical tests are not represented as passed, and any newly discovered known incompatibility blocks the final release rather than being hidden in this list.

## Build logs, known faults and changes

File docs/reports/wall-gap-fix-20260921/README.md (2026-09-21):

# Same-body wall slit correction

Requirements: CON-ARCH-006, OPS-ARCH-006. Baseline Git revision:
`83ae5fcd998d95eea55aac33d42069e62d7d2aab`.

The former upper rim was clipped to a band too far from the original stock.
At the left Caps outer edge this left an approximately 0.20 mm x 16.25 mm
same-body slit. Similar upper slits and approximately 0.40 mm lower stock-to-wall
gaps were present elsewhere. These are distinct from the intentional 0.30 mm
upper/lower fitting clearance and right A/B print separation.

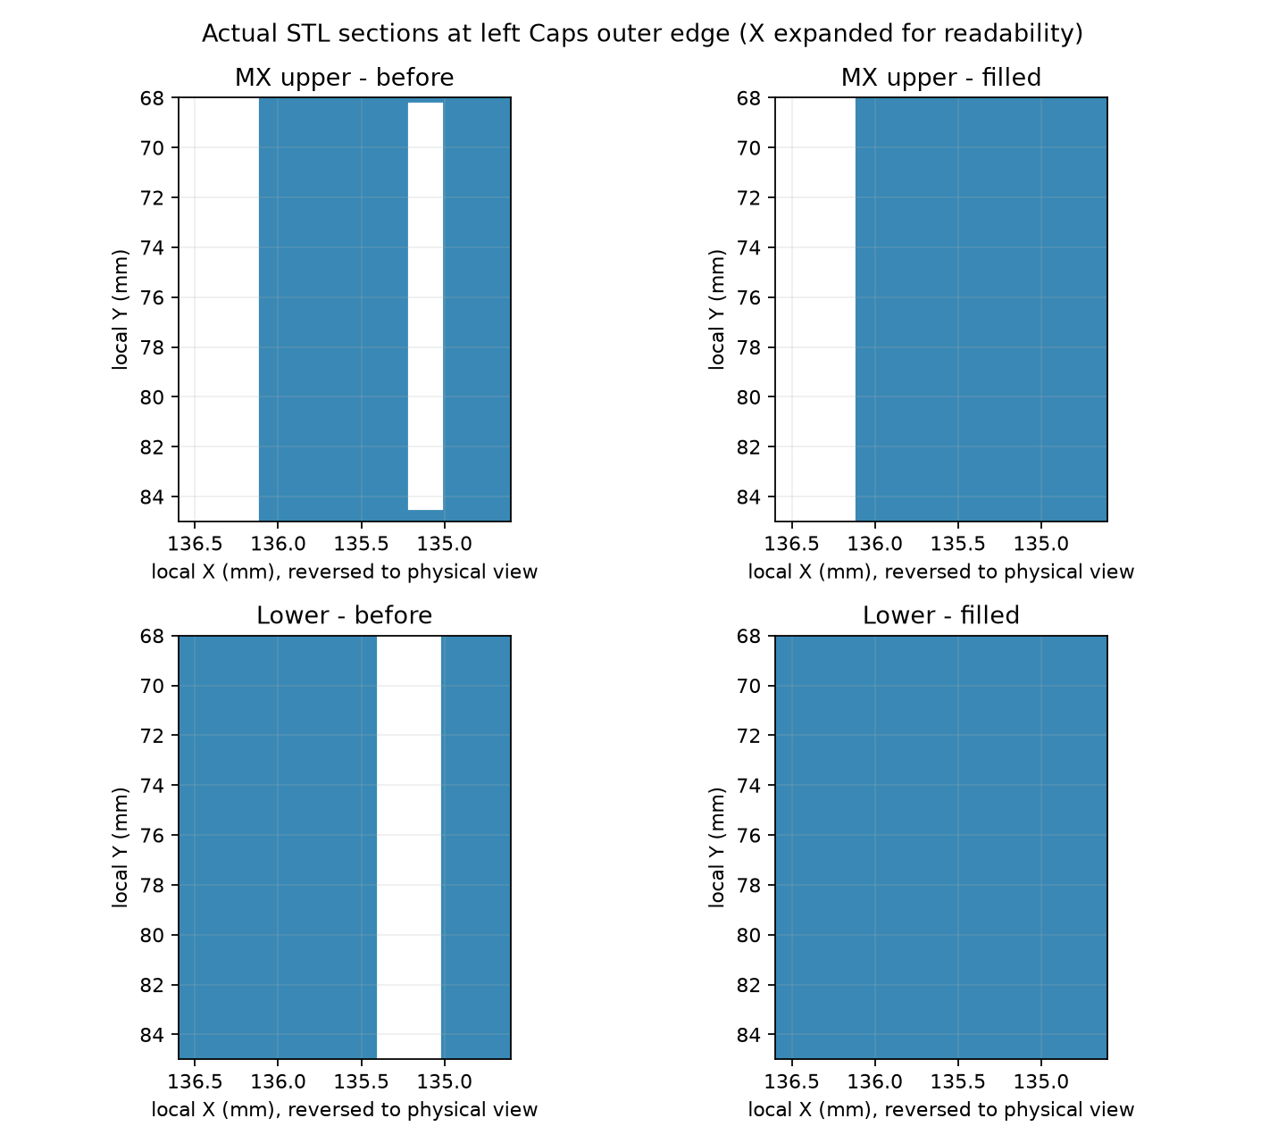
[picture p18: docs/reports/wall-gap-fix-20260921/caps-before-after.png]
Actual Caps-edge STL sections before and after


This comparison uses the baseline Fusion-reexported STL and the candidate STL
exported from the corrected, reopened Fusion archive. The horizontal scale is
expanded to make the narrow gap visible; this is a section comparison, not a
whole-assembly or physical-strength approval.

The correction adds local material; it does not subtract existing stock or
introduce the withdrawn screwless clip. The planner limits closure to narrow
same-body gaps in the perimeter band, subtracts explicit functional exclusion
regions, and respects per-body ownership. Lower additions stop at the existing
PCB support plane. Upper additions follow the original layer heights.

Right lower split-end coordinates extracted from STL required bounded precision
normalization before CAD union: a 0.0001 mm grid, at most 0.00008 mm Hausdorff
movement, and at most 0.05 mm2 changed patch area. Effective patch polygons and
measured errors are recorded in each affected generation record. The original
candidate plan is retained. Missing material is a failure, not waived as a
mesh or kernel artifact. Native/STL review checks the effective polygons.

The first full mesh review rejected the three right upper A/B gaps: the binary
STL projection measured 0.399894714 mm against the 0.3999 mm CAD threshold.
The initial failure is retained as `evidence/review-initial.json`. A separate
Fusion minimum-distance measurement reopens the actual F3D bodies. Acceptance
requires the CAD gap to meet 0.3999 mm (1e-7 mm kernel allowance), zero projected
overlap, and mesh/CAD disagreement no larger than the calculated binary-float32
coordinate rounding bound. Real CAD shortfalls and larger mesh differences are
rejected by regression tests; a blanket looser fit tolerance is not used.

## Evidence and limits

Published digital result: PASS. Ten CAD models, ten reopened real Fusion
archives and fifteen STL files are updated at the canonical model root.
Twenty-seven regression tests pass. All 123 checked fill/protection sections
report zero missing required area, zero protected-region obstruction and zero
off-plan added area. Twelve vertical assembly sweeps and six horizontal joined
assembly sweeps report zero overlap. Five A/B pairs pass source-CAD-backed
clearance checks. All sixteen ordered PCB/Gerber files remain byte-identical.
The portable publication verifier passes for all 35 CAD output files and their
source/evidence bindings. These are digital results, not physical qualification.

Publication is complete only when the canonical
`hardware/MODELS/kc2_wall_gap_fix_manifest.json` exists and its read-only verifier
passes. The `evidence` directory then contains the plan, ten CAD generation
records, ten real Fusion import/archive/reopen/native-STL records, actual STL
section/motion review, and test results. Do not infer completion from this text.

CAD Boolean checks require zero removed baseline material and zero unplanned
addition within stated kernel tolerances. Mesh checks independently inspect the
required fill at three heights per patch, functional exclusion regions, mm
units, topology and print envelope. Motion checks use actual prismatic mesh
layers for vertical upper insertion and full projections for right A/B and
left/right approach. Native output is made by Fusion, not renamed STEP files.

The PCB/Gerber hashes remain those of the previously ordered release.
Actual PLA+ strength, fatigue, manufacturing tolerance and populated physical
fit remain unqualified. No SRS criterion is marked physically verified here.

## Reproduction

Use an isolated checkout at the baseline above; bring the four new gap-fix tools,
their tests and `tools/fusion/KC2WallGapFix.py` from this revision into it. Do not
run the additive producer against already-corrected canonical models.

1. `python -B -m unittest tools.test_kc2_wall_gap_fix`
2. `python -B -m tools.kc2_wall_gap_fix plan`
3. Run `python -B -m tools.kc2_wall_gap_fix left:mx` and each of the other nine
   side/kind jobs: left/right with normal, magnetic, mx, choc_v1, deep_sea.
   For the two right lower jobs use
   `python -B -m tools.build_kc2_wall_gap_precision right:normal` and
   `python -B -m tools.build_kc2_wall_gap_precision right:magnetic` to apply the
   explicitly recorded precision normalization.
4. In Fusion's Python console load `tools/fusion/KC2WallGapFix.py`, set its `ROOT`
   and `STAGE` to the isolated checkout, and invoke `run()`. Explicit subsets
   can be supplied as a list; all ten records must pass before publication.
   Also run `tools/fusion/KC2WallGapClearance.py` for source-bound exact A/B
   measurements of all five right-side native archives.
5. Run `python -B -m tools.review_kc2_wall_gap_fix`, and the test modules recorded
   in `evidence/tests.json`. Generate a fresh test result record from the actual
   run; do not copy an old success record to approve changed sources.
6. Only after all checks pass, publish with
   `python -B -m tools.publish_kc2_wall_gap_fix --publish`.

For an already published checkout, run without `--publish`. Historical baseline
model bytes are read from Git; the read-only verifier does not require staging
directories or a live Fusion process.

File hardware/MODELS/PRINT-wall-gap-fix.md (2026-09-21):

# 동일 부품 내부의 외벽 틈 보강 — 인쇄 안내

요구사항: `CON-ARCH-006`, `OPS-ARCH-006`.

현재 파일의 게시 여부는 `kc2_wall_gap_fix_manifest.json` 및 아래 검증으로
확인합니다. manifest가 없거나 검증이 실패하면 아직 게시가 완료되지 않은 상태입니다.

```powershell
python -B -m tools.publish_kc2_wall_gap_fix
```

좌우 상판·하판의 기존 구조와 외벽 사이에 남은 불필요한 가느다란 틈을
재료로 채워 연결했습니다. 상판과 하판 사이의 0.30 mm 조립 여유, 오른쪽
A/B 분할 여유, 중앙 맞댐면, 기능상 필요한 스위치·소켓·나사·서비스 공간은
보존합니다. 외벽 높이는 Z5.60, PCB 윗면보다 1.50 mm 높은 상태를 유지합니다.
PCB 받침 높이와 1.60 mm PCB 두께도 그대로입니다.

이는 기존 나사식 구조의 보강입니다. 슬라이드 클립을 사용하지 않습니다.
일반형과 기존 좌우 결합용 자석형 하판 두 종류를 유지합니다.

## 파일 선택

STL, STEP, Fusion F3D는 모두 `hardware/MODELS` 바로 아래에 있습니다.
상판 한 종류와 하판 한 종류를 선택하고 각 행의 세 파일을 인쇄합니다.

| 부품 | 왼쪽 | 오른쪽 A | 오른쪽 B |
|---|---|---|---|
| MX 상판 | `kc2_left_mx_upper_housing.stl` | `kc2_right_mx_upper_housing_part_a.stl` | `kc2_right_mx_upper_housing_part_b.stl` |
| Choc V1 상판 | `kc2_left_choc_v1_upper_housing.stl` | `kc2_right_choc_v1_upper_housing_part_a.stl` | `kc2_right_choc_v1_upper_housing_part_b.stl` |
| Deep Sea Mini 상판 | `kc2_left_deep_sea_upper_housing.stl` | `kc2_right_deep_sea_upper_housing_part_a.stl` | `kc2_right_deep_sea_upper_housing_part_b.stl` |
| 일반 하판 | `kc2_left_lower_housing.stl` | `kc2_right_lower_housing_part_a.stl` | `kc2_right_lower_housing_part_b.stl` |
| 자석형 하판 | `kc2_left_lower_housing_magnetic.stl` | `kc2_right_lower_housing_part_a_magnetic.stl` | `kc2_right_lower_housing_part_b_magnetic.stl` |

총 15개 STL 중 사용 조합에 해당하는 6개를 선택합니다. 오른쪽 STEP/F3D는
A/B 두 몸체를 포함하므로 150 mm 프린터에서는 분리된 STL을 사용합니다.

## 인쇄와 조립

- mm, 배율 100%. 하판은 바닥면을 베드에 놓습니다.
- 상판은 넓은 판 윗면이 베드 쪽을 향하는 방향을 검토합니다. 저상형 나사
  보스 때문에 국소 지지가 필요한지는 슬라이서에서 확인합니다.
- PCB를 기존 받침에 얹고 상판을 수직으로 내려 조립합니다. 불필요한 내부 틈과
  서로 다른 부품 사이의 조립 여유를 혼동하여 강제로 눌러 끼우지 마십시오.
- MX 설계 나사는 M1.4×7.50 mm, 저상형은 M1.4×5.00 mm입니다.
  길이는 머리 아래부터이며 머리 범위는 Ø3.00×높이1.20 mm 이하인 둥근머리입니다.
  실제 나사 제품과 플라스틱 체결성 검증은 별도입니다.
- 기존 Choc V1 링 어댑터 높이와 Deep Sea Mini 가족 구분은 이전 안내와 같습니다.

STL은 수정된 STEP를 Fusion에 가져와 실제 F3D로 저장하고, 그 F3D를 다시
열어 mm 단위로 내보냅니다. 단일체·폐쇄 메시와 실제 단면, 조립 경로 검사는
출력물의 강도·피로·끼움 공차에 대한 실물 합격을 대신하지 않습니다.

이전 `PRINT-wrap-housings.md`와 wrap manifest는 보강 전 이력입니다.
보강 전 단순 재변환 폴더의 STL 대신 이 안내가 지정한 루트 STL을 사용합니다.
검증 근거는 `docs/reports/wall-gap-fix-20260921/`에 있습니다.

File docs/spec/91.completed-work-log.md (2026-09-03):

> This file is an append-only Completed Work Log summary. It is NOT a source of truth for completion; see each Requirement Block (Status, Acceptance Criteria, Verification Evidence, Change Notes).

## 7. Completed Work Log

| Date | Target | Scope | Requirement IDs | Summary | Report Paths |
|---|---|---|---|---|---|
| 2026-09-03 | kc2-x3-v2 | ARCH | OPS-ARCH-006 | Promoted the active X3 V2 KiCad, route, coupon, fabrication, mechanical, render, housing, evidence, and README artifacts to canonical paths/names; retired only the active V2 draft trees; recorded the Git-history policy in AGENTS.md; preserved zero-stabilizer and fail-closed order state. | docs/reports/kc2-x3-v2-jlcpcb-preflight-2026-09-02.md, docs/analysis/kiwi-srs-2026-09-03.kc2.x3-v2-canonical-promotion/implementation-evidence.json, docs/analysis/kiwi-srs-2026-09-03.kc2.x3-v2-canonical-promotion/konnect-mutation-evidence.json, docs/analysis/kiwi-srs-2026-09-03.kc2.x3-v2-canonical-promotion/semantic-comparison.json |

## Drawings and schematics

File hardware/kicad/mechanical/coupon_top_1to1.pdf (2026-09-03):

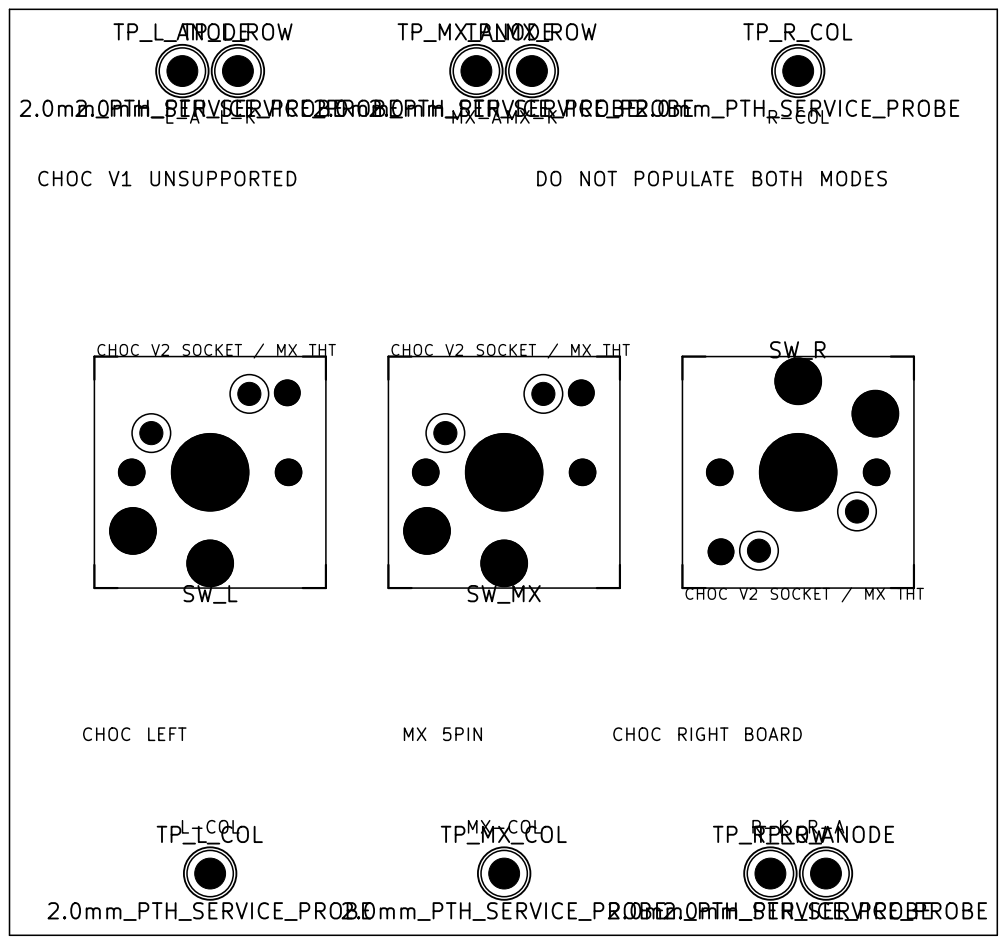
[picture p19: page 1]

CHOC V2 SOCKET / MX THT SW_L 2.0mm_PTH_SERVICE_PROBE

CHOC V2 SOCKET / MX THT SW_MX

CHOC V2 SOCKET / MX THT 2.0mm_PTH_SERVICE_PROBE

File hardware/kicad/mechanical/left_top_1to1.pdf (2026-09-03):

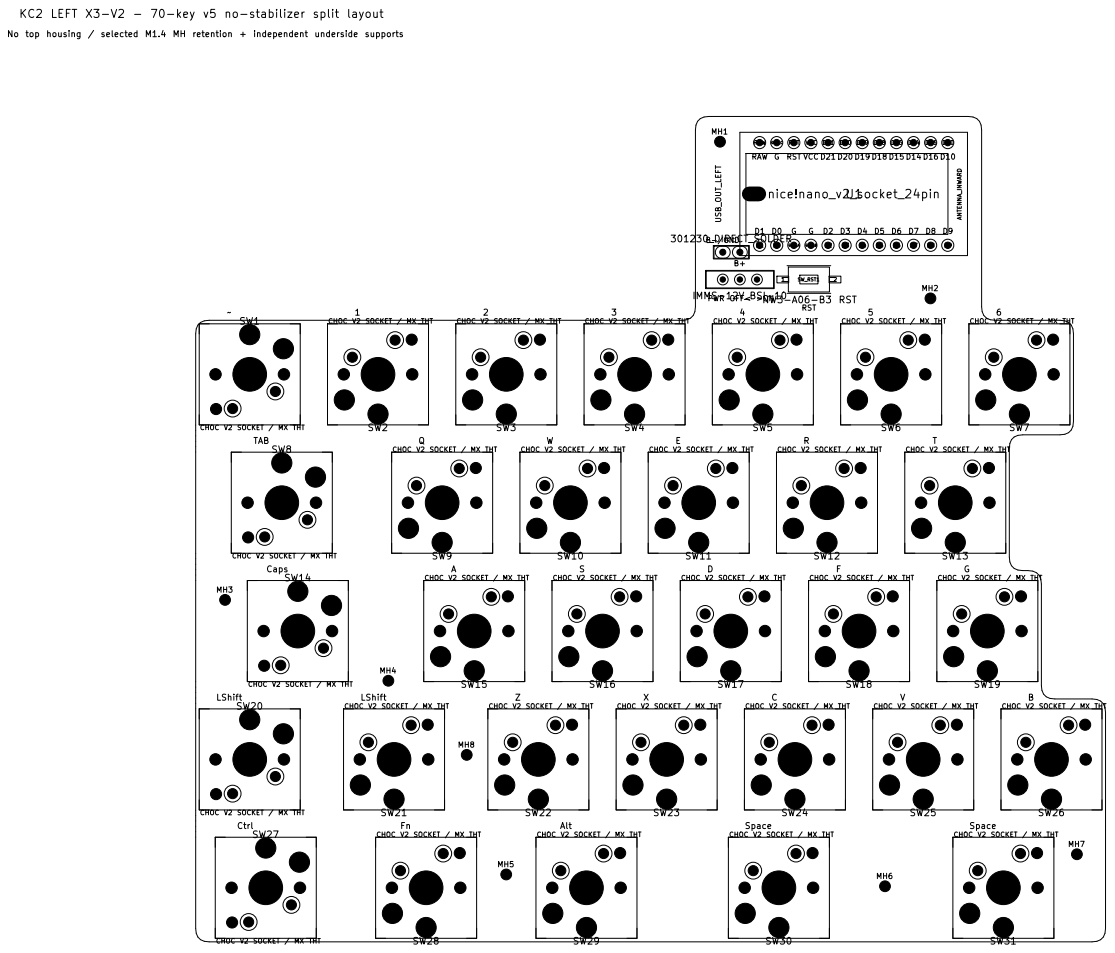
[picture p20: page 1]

CHOC V2 SOCKET / MX THT SW3

CHOC V2 SOCKET / MX THT SW2

CHOC V2 SOCKET / MX THT SW4

CHOC V2 SOCKET / MX THT SW5

CHOC V2 SOCKET / MX THT SW7

CHOC V2 SOCKET / MX THT SW10

CHOC V2 SOCKET / MX THT SW11

CHOC V2 SOCKET / MX THT SW12

CHOC V2 SOCKET / MX THT SW13

CHOC V2 SOCKET / MX THT SW15

CHOC V2 SOCKET / MX THT SW17

CHOC V2 SOCKET / MX THT SW18

CHOC V2 SOCKET / MX THT SW19

SpaceC
CHOC V2 SOCKET / MX THT SW24

CHOC V2 SOCKET / MX THT SW21

CHOC V2 SOCKET / MX THT SW22

CHOC V2 SOCKET / MX THT SW23

CHOC V2 SOCKET / MX THT SW25

CHOC V2 SOCKET / MX THT SW26

CHOC V2 SOCKET / MX THT

Space
CHOC V2 SOCKET / MX THT SW31

CHOC V2 SOCKET / MX THT SW28

CHOC V2 SOCKET / MX THT SW29

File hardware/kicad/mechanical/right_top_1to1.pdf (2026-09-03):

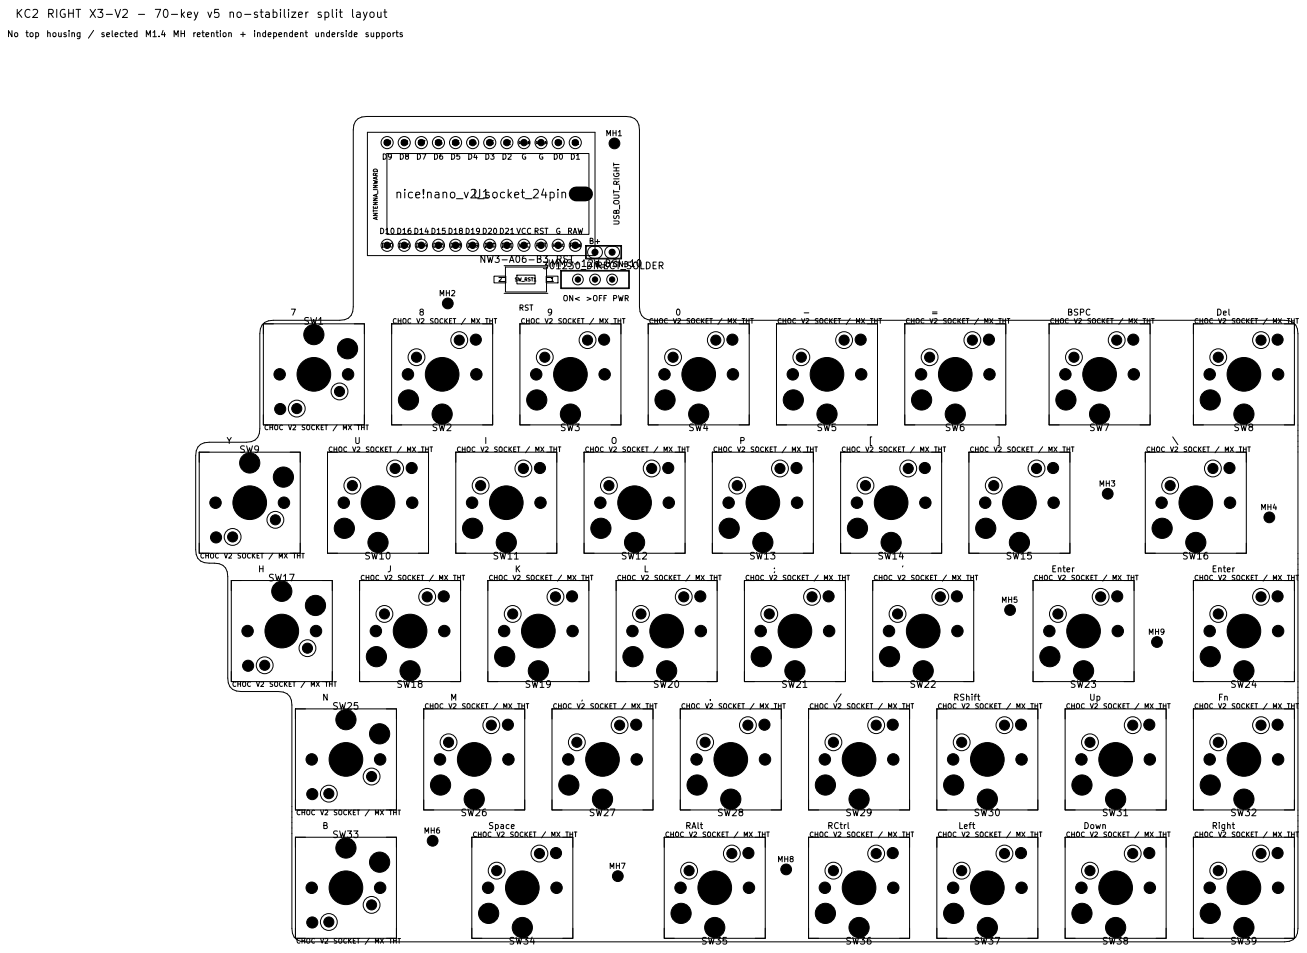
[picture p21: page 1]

CHOC V2 SOCKET / MX THT SW10 nice!nano_v2_socket_24pin

VCC
CHOC V2 SOCKET / MX THT SW4

CHOC V2 SOCKET / MX THT SW5

CHOC V2 SOCKET / MX THT SW6

CHOC V2 SOCKET / MX THT SW8

CHOC V2 SOCKET / MX THT SW3

CHOC V2 SOCKET / MX THT SW7

CHOC V2 SOCKET / MX THT SW11

CHOC V2 SOCKET / MX THT SW12

CHOC V2 SOCKET / MX THT SW13

CHOC V2 SOCKET / MX THT SW14

CHOC V2 SOCKET / MX THT SW15

CHOC V2 SOCKET / MX THT SW18

CHOC V2 SOCKET / MX THT SW20

CHOC V2 SOCKET / MX THT SW21

CHOC V2 SOCKET / MX THT SW23

CHOC V2 SOCKET / MX THT SW24

RShift Left
CHOC V2 SOCKET / MX THT SW30

CHOC V2 SOCKET / MX THT SW26

CHOC V2 SOCKET / MX THT SW27

CHOC V2 SOCKET / MX THT SW28

CHOC V2 SOCKET / MX THT SW29

CHOC V2 SOCKET / MX THT SW31

CHOC V2 SOCKET / MX THT SW32

RCtrl
CHOC V2 SOCKET / MX THT SW36

CHOC V2 SOCKET / MX THT SW34

CHOC V2 SOCKET / MX THT SW37

CHOC V2 SOCKET / MX THT SW38

CHOC V2 SOCKET / MX THT SW39

CHOC V2 SOCKET / MX THT

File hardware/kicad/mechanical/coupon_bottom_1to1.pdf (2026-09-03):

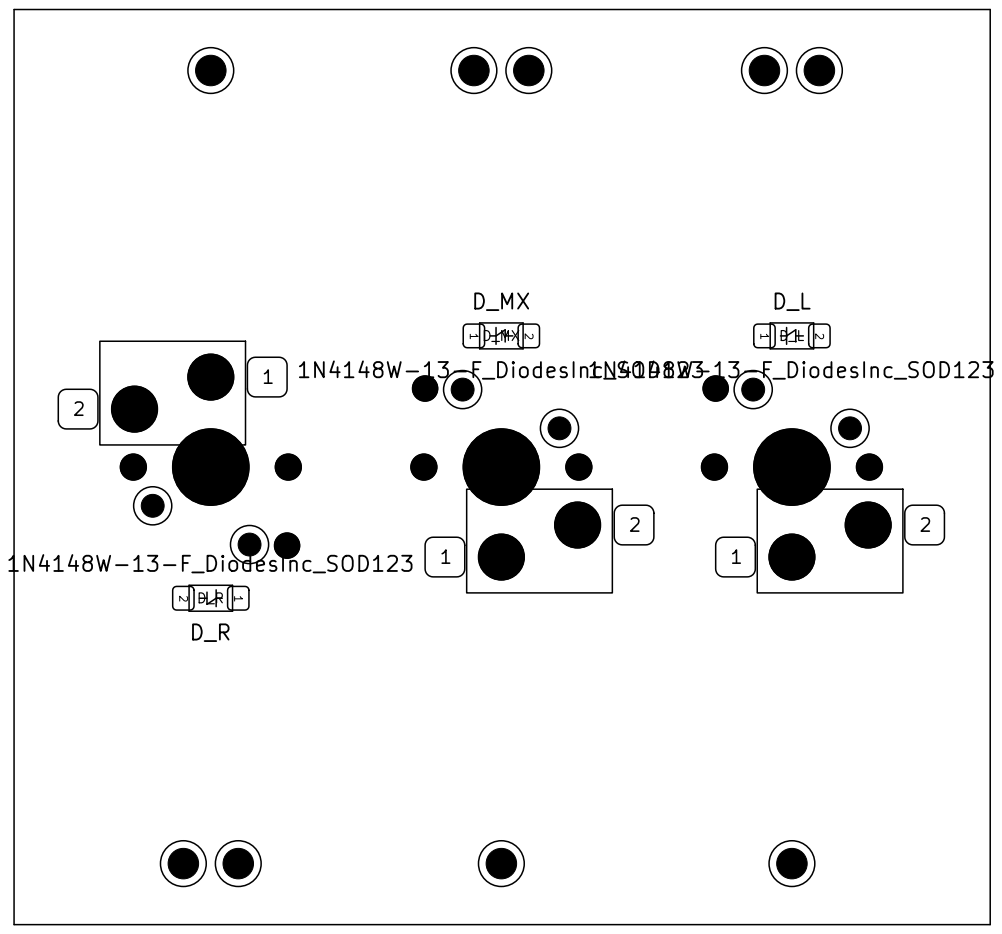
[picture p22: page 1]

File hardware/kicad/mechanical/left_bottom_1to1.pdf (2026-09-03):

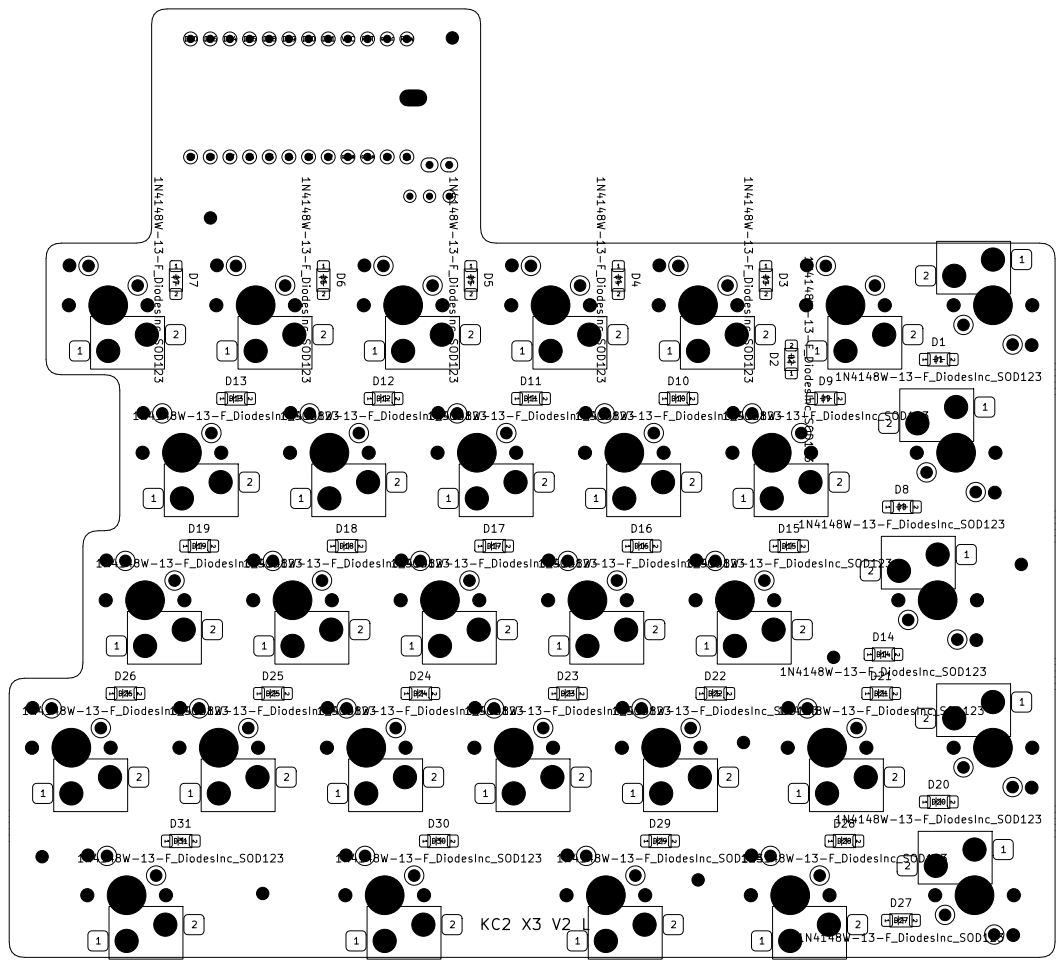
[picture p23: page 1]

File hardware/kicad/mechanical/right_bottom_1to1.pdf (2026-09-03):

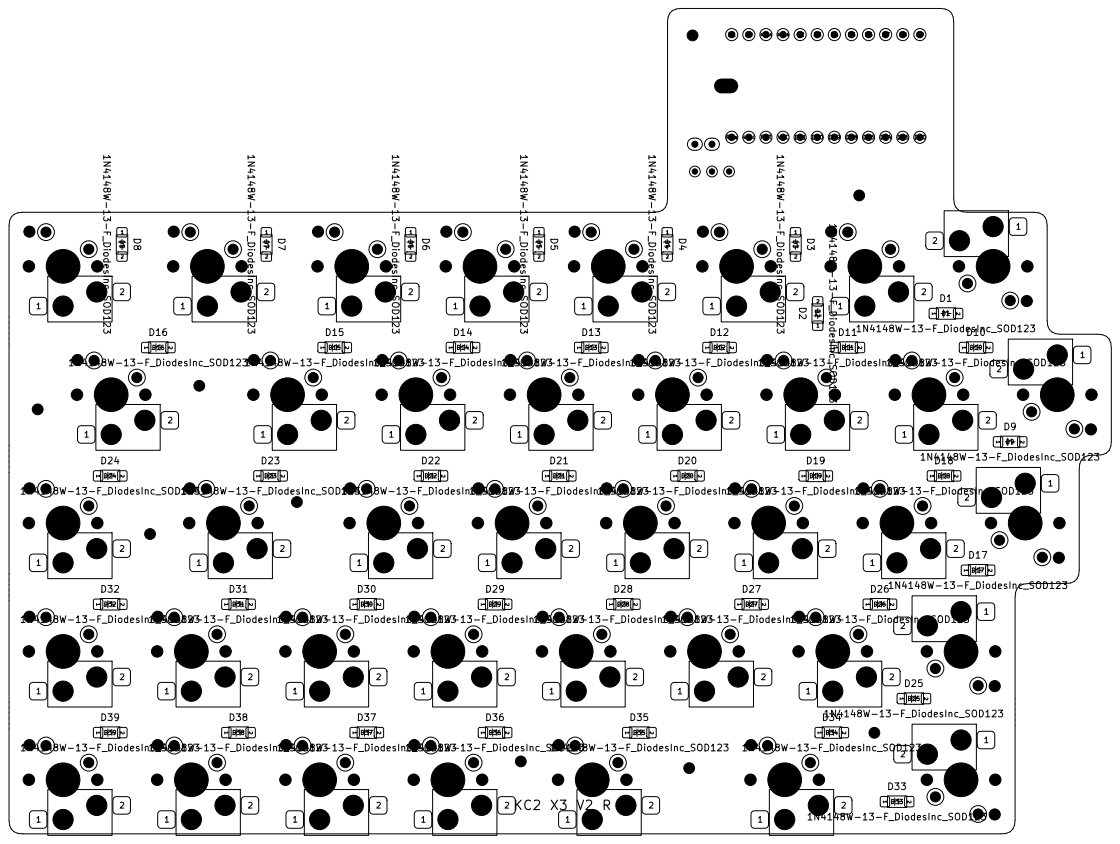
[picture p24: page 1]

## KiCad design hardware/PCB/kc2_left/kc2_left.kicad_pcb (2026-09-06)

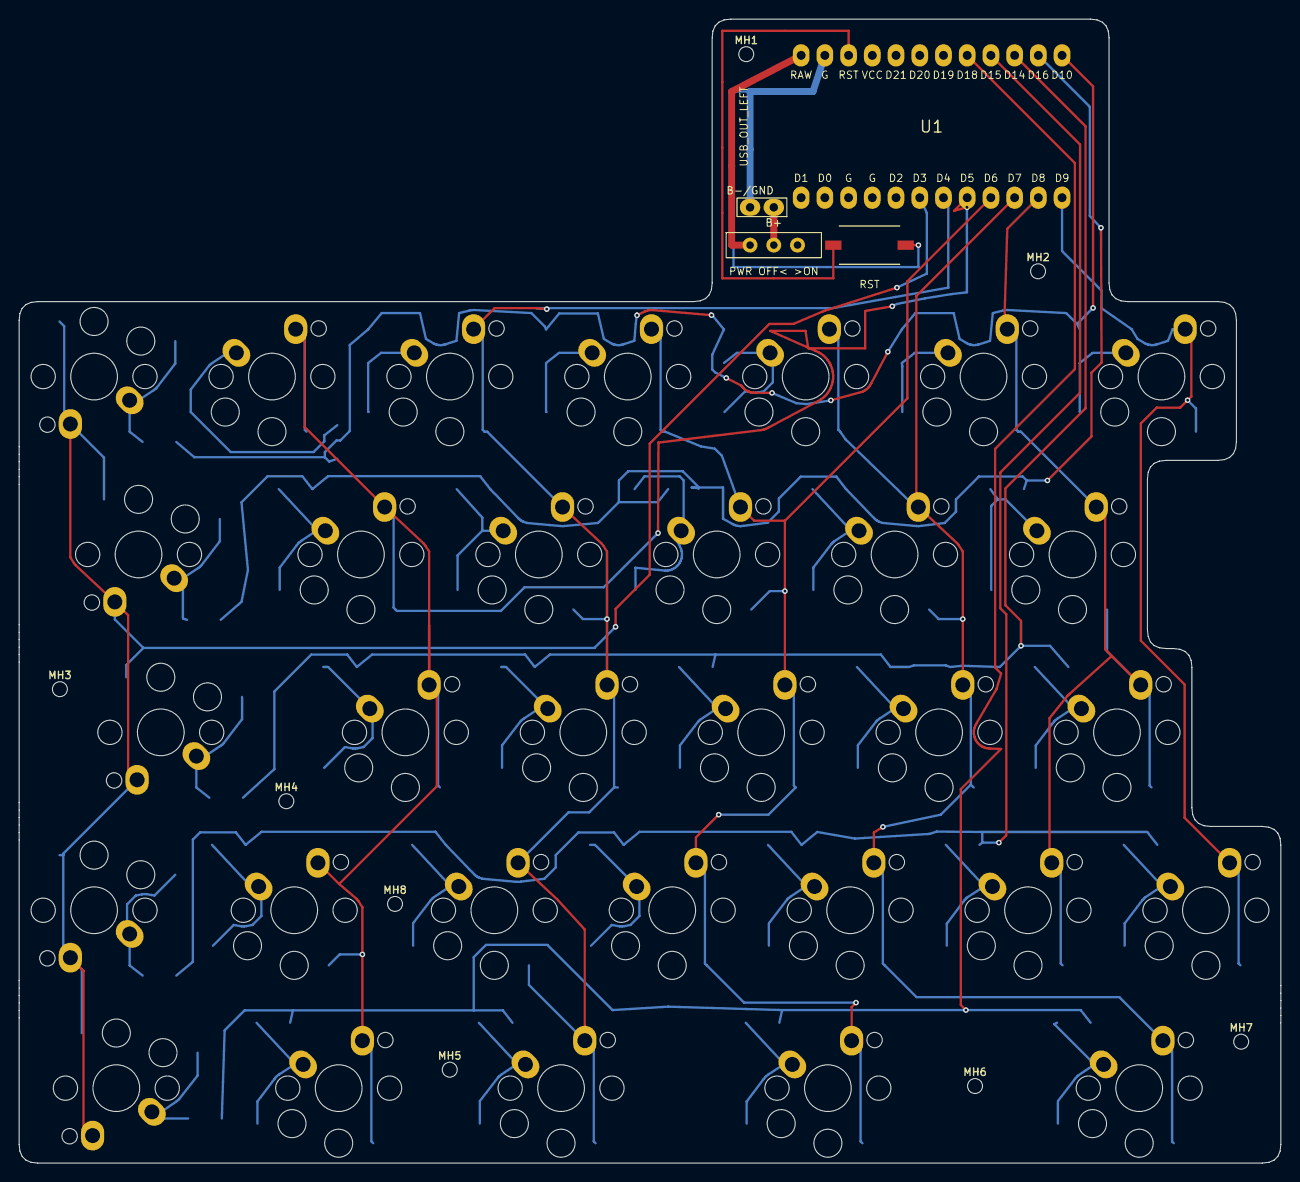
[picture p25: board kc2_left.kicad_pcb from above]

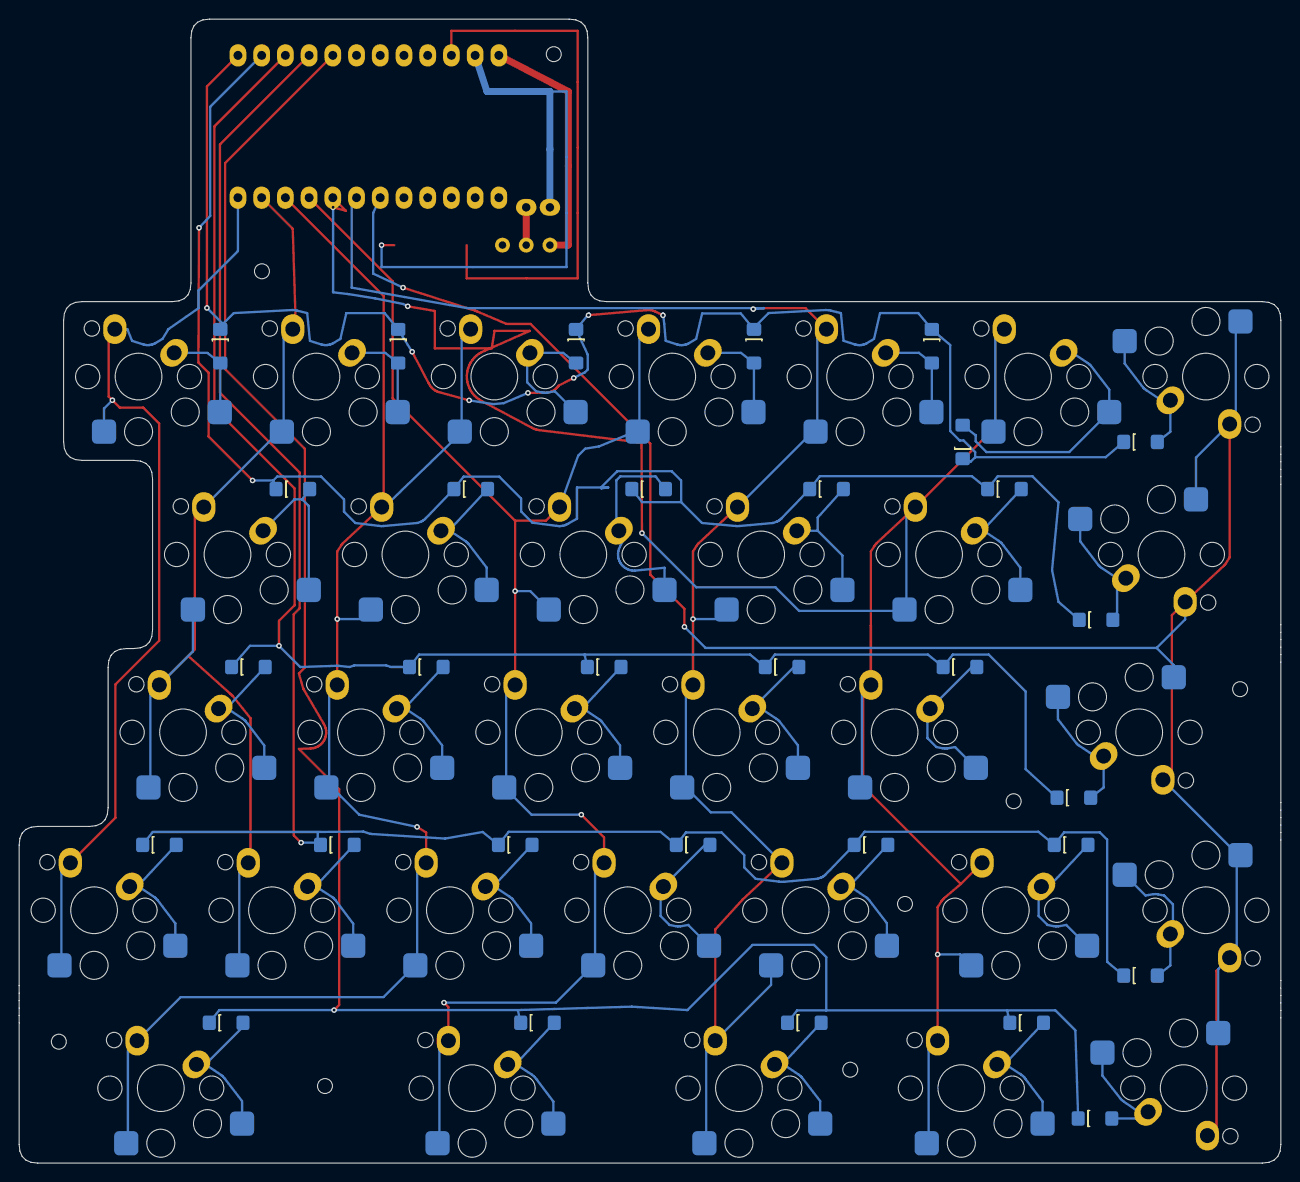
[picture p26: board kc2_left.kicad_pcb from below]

Board: 2 copper layers, 135.1 x 122.5 mm, 76 parts (31 on the bottom side), 47 nets.

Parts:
BAT1: 301230_3.7V_100mAh; BAT_301230_30x12mm
BAT_LEAD_SLOT1: BAT_LEAD_NPTH_SLOT_3.6x2.2
D1, D2, D3, D4, D5, D6, D7, D8, D9, D10, D11, D12, D13, D14, D15, D16, D17, D18, D19, D20, D21, D22, D23, D24, D25, D26, D27, D28, D29, D30, D31: 1N4148W-13-F_DiodesInc_SOD123; D_1N4148W_SOD123_HandSolder_DiodesInc
J_BAT1: 301230_DIRECT_SOLDER; BAT_2Pin_PTH_DirectSolder
MH1, MH2, MH3, MH4, MH5, MH6, MH7, MH8: M1.4_NPTH_1.60; MH_M1.4_NPTH_1.60
SW1: KEY_01; SW_Choc_V2_Socket_MX_THT
SW2: KEY_02; SW_Choc_V2_Socket_MX_THT
SW3: KEY_03; SW_Choc_V2_Socket_MX_THT
SW4: KEY_04; SW_Choc_V2_Socket_MX_THT
SW5: KEY_05; SW_Choc_V2_Socket_MX_THT
SW6: KEY_06; SW_Choc_V2_Socket_MX_THT
SW7: KEY_07; SW_Choc_V2_Socket_MX_THT
SW8: KEY_08; SW_Choc_V2_Socket_MX_THT
SW9: KEY_09; SW_Choc_V2_Socket_MX_THT
SW10: KEY_10; SW_Choc_V2_Socket_MX_THT
SW11: KEY_11; SW_Choc_V2_Socket_MX_THT
SW12: KEY_12; SW_Choc_V2_Socket_MX_THT
SW13: KEY_13; SW_Choc_V2_Socket_MX_THT
SW14: KEY_14; SW_Choc_V2_Socket_MX_THT
SW15: KEY_15; SW_Choc_V2_Socket_MX_THT
SW16: KEY_16; SW_Choc_V2_Socket_MX_THT
SW17: KEY_17; SW_Choc_V2_Socket_MX_THT
SW18: KEY_18; SW_Choc_V2_Socket_MX_THT
SW19: KEY_19; SW_Choc_V2_Socket_MX_THT
SW20: KEY_20; SW_Choc_V2_Socket_MX_THT
SW21: KEY_21; SW_Choc_V2_Socket_MX_THT
SW22: KEY_22; SW_Choc_V2_Socket_MX_THT
SW23: KEY_23; SW_Choc_V2_Socket_MX_THT
SW24: KEY_24; SW_Choc_V2_Socket_MX_THT
SW25: KEY_25; SW_Choc_V2_Socket_MX_THT
SW26: KEY_26; SW_Choc_V2_Socket_MX_THT
SW27: KEY_27; SW_Choc_V2_Socket_MX_THT
SW28: KEY_28; SW_Choc_V2_Socket_MX_THT
SW29: KEY_29; SW_Choc_V2_Socket_MX_THT
SW30: KEY_30; SW_Choc_V2_Socket_MX_THT
SW31: KEY_31; SW_Choc_V2_Socket_MX_THT
SW_PWR1: IMMS-12V_BSI-10; SW_IMMS_12V_BSI10_THT
SW_RST1: NW3-A06-B3 RST; SW_NW3_A06_B3_SMD
U1: nice!nano_v2_socket_24pin; NiceNanoV2_Socket_24Pin_USB_OUT_LEFT

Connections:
BAT+: J_BAT1.1, SW_PWR1.1
GND: J_BAT1.2, SW_RST1.2, U1.GND_C
LK01_D: D1.2, SW1.2
LK02_D: D2.2, SW2.2
LK03_D: D3.2, SW3.2
LK04_D: D4.2, SW4.2
LK05_D: D5.2, SW5.2
LK06_D: D6.2, SW6.2
LK07_D: D7.2, SW7.2
LK08_D: D8.2, SW8.2
LK09_D: D9.2, SW9.2
LK10_D: D10.2, SW10.2
LK11_D: D11.2, SW11.2
LK12_D: D12.2, SW12.2
LK13_D: D13.2, SW13.2
LK14_D: D14.2, SW14.2
LK15_D: D15.2, SW15.2
LK16_D: D16.2, SW16.2
LK17_D: D17.2, SW17.2
LK18_D: D18.2, SW18.2
LK19_D: D19.2, SW19.2
LK20_D: D20.2, SW20.2
LK21_D: D21.2, SW21.2
LK22_D: D22.2, SW22.2
LK23_D: D23.2, SW23.2
LK24_D: D24.2, SW24.2
LK25_D: D25.2, SW25.2
LK26_D: D26.2, SW26.2
LK27_D: D27.2, SW27.2
LK28_D: D28.2, SW28.2
LK29_D: D29.2, SW29.2
LK30_D: D30.2, SW30.2
LK31_D: D31.2, SW31.2
L_COL0: SW1.1, SW8.1, SW14.1, SW20.1, SW27.1, U1.D3
L_COL1: SW2.1, SW9.1, SW15.1, SW21.1, SW28.1, U1.D5
L_COL2: SW3.1, SW10.1, SW16.1, SW22.1, SW29.1, U1.D4
L_COL3: SW4.1, SW11.1, SW17.1, SW23.1, SW30.1, U1.D6
L_COL4: SW5.1, SW12.1, SW18.1, SW24.1, SW31.1, U1.D7
L_COL5: SW6.1, SW13.1, SW19.1, SW25.1, U1.D8
L_COL6: SW7.1, SW26.1, U1.D9
L_ROW0: D1.1, D2.1, D3.1, D4.1, D5.1, D6.1, D7.1, U1.D10
L_ROW1: D8.1, D9.1, D10.1, D11.1, D12.1, D13.1, U1.D16
L_ROW2: D14.1, D15.1, D16.1, D17.1, D18.1, D19.1, U1.D14
L_ROW3: D20.1, D21.1, D22.1, D23.1, D24.1, D25.1, D26.1, U1.D15
L_ROW4: D27.1, D28.1, D29.1, D30.1, D31.1, U1.D18
NN_B+: SW_PWR1.2, U1.RAW
RST: SW_RST1.1, U1.RST

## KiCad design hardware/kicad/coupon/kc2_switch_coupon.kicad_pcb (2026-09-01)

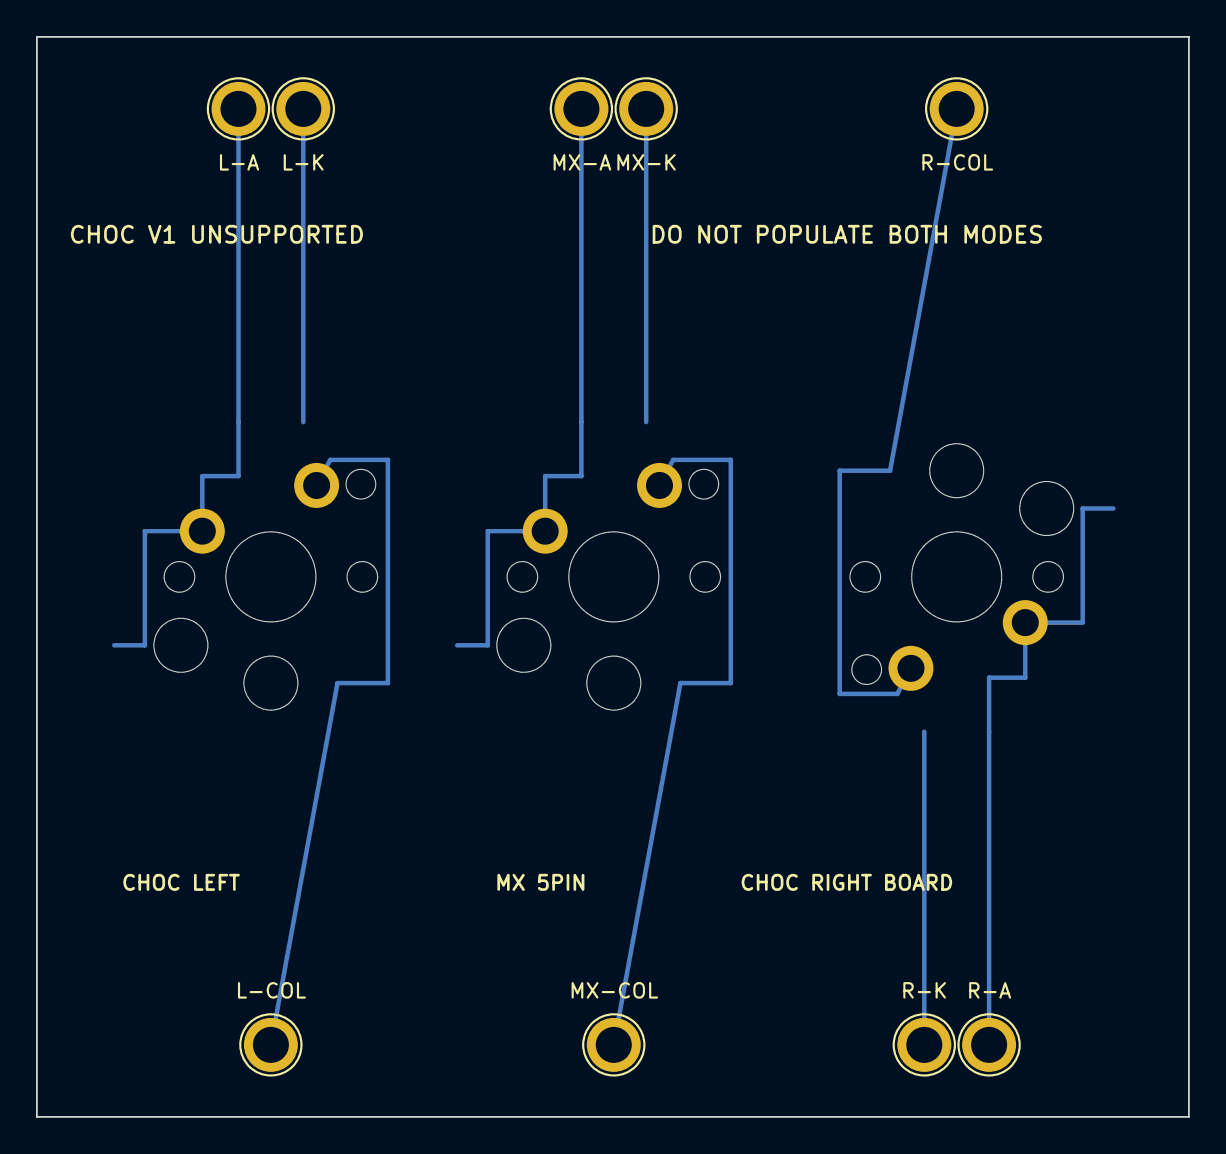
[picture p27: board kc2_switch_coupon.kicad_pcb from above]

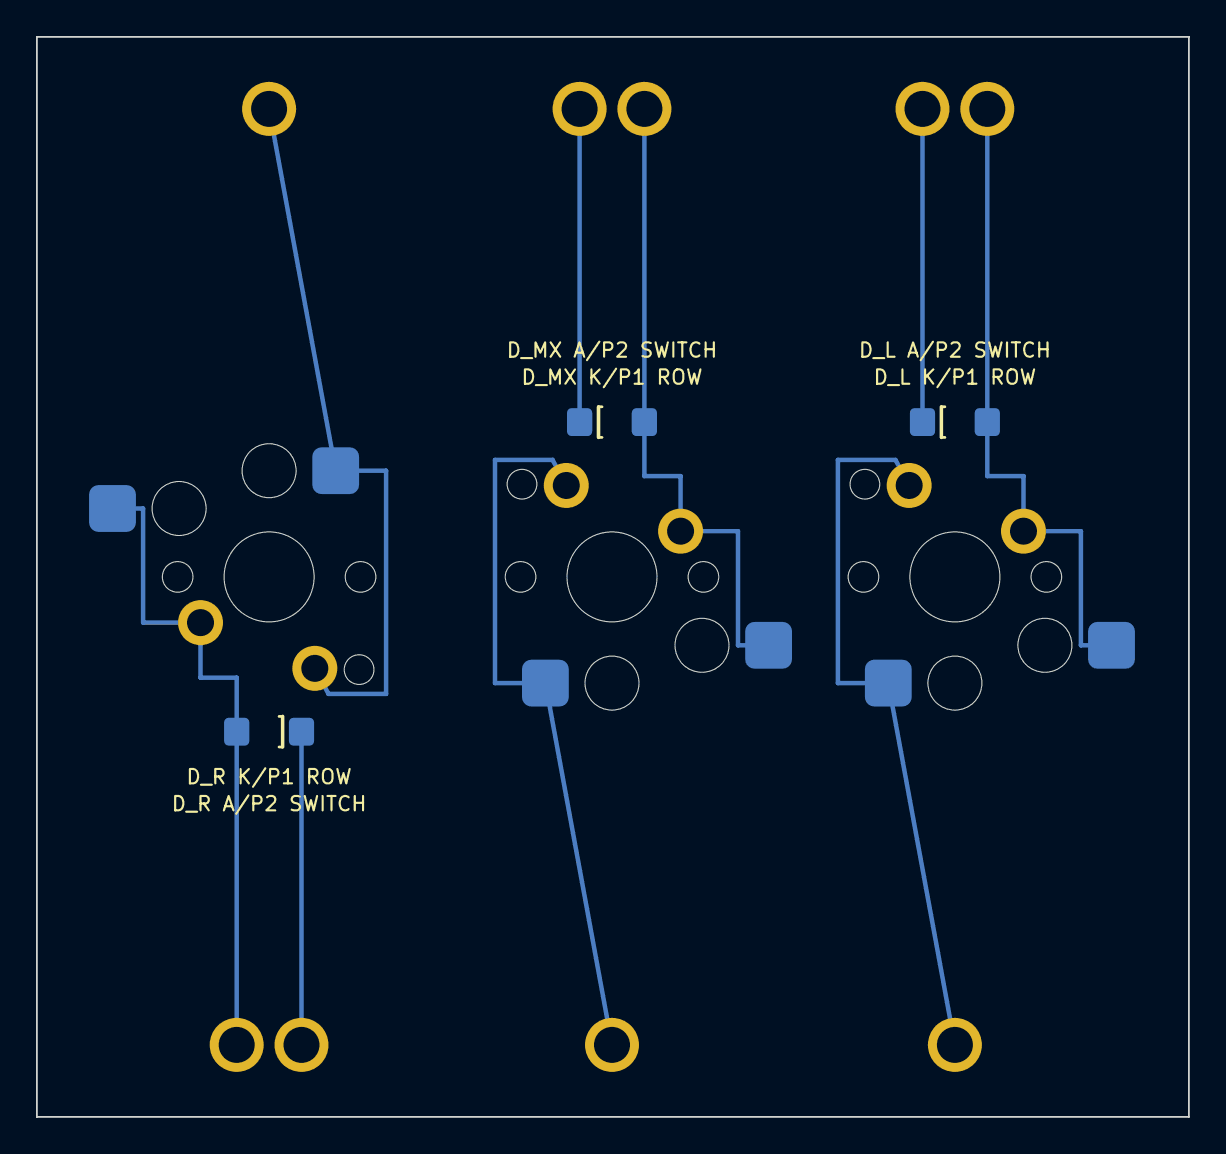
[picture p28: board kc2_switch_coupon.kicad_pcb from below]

Board: 2 copper layers, 64.0 x 60.0 mm, 15 parts (3 on the bottom side), 9 nets.

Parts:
D_L: 1N4148W-13-F_DiodesInc_SOD123; D_1N4148W_SOD123_HandSolder_DiodesInc
D_MX: 1N4148W-13-F_DiodesInc_SOD123; D_1N4148W_SOD123_HandSolder_DiodesInc
D_R: 1N4148W-13-F_DiodesInc_SOD123; D_1N4148W_SOD123_HandSolder_DiodesInc
SW_L: CHOC_V2_SOCKET_OR_MX_5PIN_THT; SW_Choc_V2_Socket_MX_THT
SW_MX: CHOC_V2_SOCKET_OR_MX_5PIN_THT; SW_Choc_V2_Socket_MX_THT
SW_R: CHOC_V2_SOCKET_OR_MX_5PIN_THT; SW_Choc_V2_Socket_MX_THT
TP_L_ANODE: 2.0mm_PTH_SERVICE_PROBE; TestPoint_Plated_Hole_D2.0mm
TP_L_COL: 2.0mm_PTH_SERVICE_PROBE; TestPoint_Plated_Hole_D2.0mm
TP_L_ROW: 2.0mm_PTH_SERVICE_PROBE; TestPoint_Plated_Hole_D2.0mm
TP_MX_ANODE: 2.0mm_PTH_SERVICE_PROBE; TestPoint_Plated_Hole_D2.0mm
TP_MX_COL: 2.0mm_PTH_SERVICE_PROBE; TestPoint_Plated_Hole_D2.0mm
TP_MX_ROW: 2.0mm_PTH_SERVICE_PROBE; TestPoint_Plated_Hole_D2.0mm
TP_R_ANODE: 2.0mm_PTH_SERVICE_PROBE; TestPoint_Plated_Hole_D2.0mm
TP_R_COL: 2.0mm_PTH_SERVICE_PROBE; TestPoint_Plated_Hole_D2.0mm
TP_R_ROW: 2.0mm_PTH_SERVICE_PROBE; TestPoint_Plated_Hole_D2.0mm

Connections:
D_L_ANODE: D_L.2, SW_L.2, TP_L_ANODE.1
D_L_COL: SW_L.1, TP_L_COL.1
D_L_ROW: D_L.1, TP_L_ROW.1
D_MX_ANODE: D_MX.2, SW_MX.2, TP_MX_ANODE.1
D_MX_COL: SW_MX.1, TP_MX_COL.1
D_MX_ROW: D_MX.1, TP_MX_ROW.1
D_R_ANODE: D_R.2, SW_R.2, TP_R_ANODE.1
D_R_COL: SW_R.1, TP_R_COL.1
D_R_ROW: D_R.1, TP_R_ROW.1

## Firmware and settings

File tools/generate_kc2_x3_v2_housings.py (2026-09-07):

"""Generate KC2 support webs with integrated closed floors and silicone-pad plans.

The V2 design supersedes the former canonical 77-key housing. It subtracts
internal underside-component reliefs from the current canonical V2 board
outlines, preserves the distributed load path, and adds only the
CON-ARCH-006 M1.4 MH clamp/registration columns and provisional blind pilots.
"""

from __future__ import annotations

import argparse
import json
import math
import re
import subprocess
import sys
from pathlib import Path
from typing import Any


ROOT = Path(__file__).resolve().parents[1]
GENERATOR_PATH = Path(__file__).resolve()
if str(ROOT / "tools") not in sys.path:
    sys.path.insert(0, str(ROOT / "tools"))

import generate_kc2_housings as legacy_geometry  # noqa: E402
from canonical_hash import HASH_POLICY, sha256_file  # noqa: E402


REQUIREMENT = "CON-ARCH-006"
VARIANT = "x3-v2"
OUTPUT_DIR = ROOT / "hardware" / "case"
MANIFEST_PATH = OUTPUT_DIR / "kc2_housing_manifest.json"
BOARD_PATHS = {
    "left": ROOT / "hardware" / "kicad" / "kc2_left" / "kc2_left.kicad_pcb",
    "right": ROOT / "hardware" / "kicad" / "kc2_right" / "kc2_right.kicad_pcb",
}

EXTERIOR_BOTTOM_Z_MM = 0.00
HOUSING_HEIGHT_MM = 2.50
PCB_BOTTOM_Z_MM = HOUSING_HEIGHT_MM
PCB_THICKNESS_MM = 1.60
OUTLINE_INSET_MM = 0.10
RAIL_INSET_MM = 0.10
RAIL_WIDTH_MM = 0.65
POST_DIAMETER_MM = 2.40
POST_CLEARANCE_MM = 0.30
KEY_LOAD_SUPPORT_ROUTED_COPPER_CLEARANCE_MM = 0.30
FILLET_ALLOWANCE_MM = 0.30
COMPONENT_MINIMUM_CLEARANCE_MM = 0.30
COMPONENT_CUTOUT_CLEARANCE_MM = 0.35
COMPONENT_CUTOUT_SIMPLIFY_MM = 0.02
MIN_DIODE_HOUSING_PERIMETER_LAND_MM = 0.85
MIN_SERVICE_HOUSING_PERIMETER_LAND_MM = 0.85
CHOC_SOCKET_OFFICIAL_BODY_DEPTH_MAX_MM = 2.30
CHOC_SOCKET_ASSEMBLY_ALLOWANCE_MM = 0.10
DIODE_MANUFACTURER = "Diodes Incorporated"
DIODE_MPN = "1N4148W-13-F"
DIODE_ELEPARTS_GOODS_NO = "3417687"
DIODE_OFFICIAL_BODY_DEPTH_MAX_MM = 1.35
DIODE_OFFICIAL_PLAN_ENVELOPE_MAX_MM = (2.85, 1.70)
DIODE_OFFICIAL_TERMINAL_SPAN_MAX_MM = 3.85
DIODE_SOLDER_FILLET_DEPTH_ALLOWANCE_MM = 0.30
CHOC_SOCKET_OFFICIAL_SOURCE = "https://www.kailhswitch.com/uploads/15927/files/CPG135001S30.pdf"
DIODE_OFFICIAL_SOURCE = "https://www.diodes.com/datasheet/download/1N4148W.pdf"
TRACK_CLEARANCE_MM = 0.15
BATTERY_ACCESS_CLEARANCE_MM = 0.70
BATTERY_REFERENCE = "BAT1"
BATTERY_NOMINAL_PLAN_ENVELOPE_MM = (30.00, 12.00)
BATTERY_MODELED_DEPTH_MM = 3.00
BATTERY_CENTERS_MM = {
    "left": [131.7125, 50.7500],
    "right": [78.4000, 50.7500],
}
BATTERY_TERMINATION_REFERENCE = "J_BAT1"
POWER_SWITCH_REFERENCE = "SW_PWR1"
POWER_SWITCH_DRILL_COUNT = 3
POWER_SWITCH_DRILL_DIAMETER_MM = 0.80
POWER_SWITCH_PITCH_MM = 2.54
POWER_SWITCH_BODY_ENVELOPE_MM = (10.00, 2.50)
POWER_SWITCH_ACTUATOR_TRAVEL_MM = 1.60
# The controlled drawing gives travel but no separate actuator plan width.  Use
# the complete body plus the full travel in both longitudinal directions so a
# body-only placement mutation cannot hide behind unchanged through-hole pads.
POWER_SWITCH_ACTUATOR_SWEEP_ENVELOPE_MM = (
    POWER_SWITCH_BODY_ENVELOPE_MM[0] + 2.0 * POWER_SWITCH_ACTUATOR_TRAVEL_MM,
    POWER_SWITCH_BODY_ENVELOPE_MM[1],
)
RESET_REFERENCE = "SW_RST1"
RESET_BODY_ENVELOPE_MM = (6.10, 3.70)
RESET_ACTUATOR_ENVELOPE_MM = (2.70, 1.30)
RESET_LOCAL_SUPPORT_DIAMETER_MM = 3.00
MAX_LOAD_POINT_TO_SUPPORT_MM = 4.40
PRINT_VOLUME_LIMIT_MM = 150.0
RIGHT_SPLIT_CLEARANCE_MM = 0.20
PUZZLE_CAPTURE_FEATURE_COUNT = 2
PUZZLE_NECK_WIDTH_MM = 2.00
PUZZLE_HEAD_DIAMETER_MM = 4.50
PUZZLE_NECK_LENGTH_MM = 3.00
PUZZLE_MIN_CAPTURE_PER_SIDE_MM = 1.00
DESK_STANDOFF_NOMINAL_MM = 1.00
DESK_STANDOFF_PRINT_TOLERANCE_MM = 0.30
DESK_DATUM_Z_MM = EXTERIOR_BOTTOM_Z_MM - DESK_STANDOFF_NOMINAL_MM
DESK_CONTACT_DIAMETER_MM = POST_DIAMETER_MM
CLOSED_FLOOR_TOP_Z_MM = -1.0
CLOSED_FLOOR_THICKNESS_MM = 1.2
CLOSED_FLOOR_BOTTOM_Z_MM = -2.2
SILICONE_FOOT_DIAMETER_MM = 8.0
SILICONE_FOOT_EDGE_RESERVE_MM = .8
MOUNTING_NPTH_DIAMETER_MM = 1.60
MOUNTING_SUPPORT_LAND_DIAMETER_MM = 3.00
MOUNTING_PILOT_DIAMETER_MM = 1.10
MOUNTING_PILOT_DEPTH_MM = 2.80
MOUNTING_PILOT_BOTTOM_Z_MM = round(
    PCB_BOTTOM_Z_MM - MOUNTING_PILOT_DEPTH_MM,
    4,
)
MOUNTING_CLOSED_BOTTOM_MM = round(
    MOUNTING_PILOT_BOTTOM_Z_MM - DESK_DATUM_Z_MM,
    4,
)
MOUNTING_FASTENER_HEAD_STYLE = "non_countersunk_rounded_pan_or_button"
MOUNTING_HEAD_DIAMETER_MM = 3.00
MOUNTING_HEAD_HEIGHT_MM = 1.20
MOUNTING_DRIVER_DIAMETER_MM = 3.00
MOUNTING_UNRELATED_SUPPORT_RESERVE_MM = 0.25
MOUNTING_HEAD_RESERVE_MM = 0.25
MOUNTING_PROVISIONAL_SCREW_UNDER_HEAD_LENGTH_MM = 4.00
PCB_THICKNESS_TOLERANCE_FRACTION = 0.10
MOUNTING_PENETRATION_RANGE_MM = (
    MOUNTING_PROVISIONAL_SCREW_UNDER_HEAD_LENGTH_MM
    - PCB_THICKNESS_MM * (1.0 + PCB_THICKNESS_TOLERANCE_FRACTION),
    MOUNTING_PROVISIONAL_SCREW_UNDER_HEAD_LENGTH_MM
    - PCB_THICKNESS_MM * (1.0 - PCB_THICKNESS_TOLERANCE_FRACTION),
)
MOUNTING_MINIMUM_TIP_CLEARANCE_MM = (
    MOUNTING_PILOT_DEPTH_MM - MOUNTING_PENETRATION_RANGE_MM[1]
)
SWITCH_SERVICE_BODY_ENVELOPE_MM = 15.60
EXPECTED_DISTRIBUTED_SUPPORT_COUNTS = {"left": 31, "right": 39}
EXPECTED_PRIMARY_SUPPORT_LOAD_SPAN_MM = {"left": 4.3902, "right": 4.3902}
KEY_LOAD_SUPPORT_TO_MOUNT_CLEARANCE_MM = 2.50
MOUNTING_HOLE_COORDINATES_MM = {
    "left": (
        ("MH1", 112.8625, 43.0000),
        ("MH2", 144.1125, 66.2500),
        ("MH3", 39.3625, 111.0000),
        ("MH4", 63.6125, 123.0000),
        ("MH5", 81.1125, 151.7500),
        ("MH6", 137.3625, 153.5000),
        ("MH7", 165.8625, 148.7500),
        ("MH8", 75.2500, 134.0000),
    ),
    "right": (
        ("MH1", 97.1875, 43.2500),
        ("MH2", 72.4375, 67.0000),
        ("MH3", 170.4375, 95.2500),
        ("MH4", 194.4375, 98.7500),
        ("MH5", 155.9375, 112.5000),
        ("MH6", 70.1875, 146.7500),
        ("MH7", 97.6875, 152.0000),
        ("MH8", 122.6875, 151.0000),
        ("MH9", 177.7500, 117.2500),
    ),
}


def has_trailing_horizontal_whitespace(path: Path) -> bool:
    return re.search(rb"[ \t]+(?=\r?\n|\Z)", path.read_bytes()) is not None


def normalize_exported_text(path: Path) -> None:
    """Strip only line-ending spaces/tabs while preserving all newline bytes."""

    original = path.read_bytes()
    normalized = re.sub(rb"[ \t]+(?=\r?\n|\Z)", b"", original)
    if normalized != original:
        path.write_bytes(normalized)


def _box(pcbnew: Any, item: Any) -> list[float]:
    bounds = item.GetBoundingBox()
    return [
        pcbnew.ToMM(bounds.GetX()),
        pcbnew.ToMM(bounds.GetY()),
        pcbnew.ToMM(bounds.GetX() + bounds.GetWidth()),
        pcbnew.ToMM(bounds.GetY() + bounds.GetHeight()),
    ]


def _point(pcbnew: Any, value: Any) -> list[float]:
    return [pcbnew.ToMM(value.x), pcbnew.ToMM(value.y)]


def _shape_box(pcbnew: Any, shape: Any) -> list[float]:
    bounds = shape.BBox()
    return [
        pcbnew.ToMM(bounds.GetX()),
        pcbnew.ToMM(bounds.GetY()),
        pcbnew.ToMM(bounds.GetX() + bounds.GetWidth()),
        pcbnew.ToMM(bounds.GetY() + bounds.GetHeight()),
    ]


def _axis_aligned_projection_size(
    size_mm: tuple[float, float], angle_deg: float
) -> list[float]:
    angle = math.radians(float(angle_deg))
    cosine = abs(math.cos(angle))
    sine = abs(math.sin(angle))
    return [
        round(size_mm[0] * cosine + size_mm[1] * sine, 4),
        round(size_mm[0] * sine + size_mm[1] * cosine, 4),
    ]


def validate_battery_termination_pad_records(
    source_name: str, pads: list[dict[str, Any]]
) -> dict[str, Any]:
    if len(pads) != 2:
        raise RuntimeError(
            f"{source_name}: {BATTERY_TERMINATION_REFERENCE} must have exactly two pads"
        )
    plated_count = sum(bool(pad.get("is_plated_through_hole")) for pad in pads)
    if plated_count != 2:
        raise RuntimeError(
            f"{source_name}: {BATTERY_TERMINATION_REFERENCE} must have two plated PTH pads"
        )
    centers = [pad.get("center", []) for pad in pads]
    sizes = [pad.get("size_mm", []) for pad in pads]
    if any(len(center) != 2 for center in centers) or any(len(size) != 2 for size in sizes):
        raise RuntimeError(
            f"{source_name}: {BATTERY_TERMINATION_REFERENCE} pad envelope is missing"
        )
    center_distance = math.hypot(
        float(centers[1][0]) - float(centers[0][0]),
        float(centers[1][1]) - float(centers[0][1]),
    )
    cutout_radii = [
        max(float(size[0]), float(size[1])) / 2.0
        + FILLET_ALLOWANCE_MM
        + COMPONENT_CUTOUT_CLEARANCE_MM
        for size in sizes
    ]
    cutout_envelopes_overlap = center_distance < sum(cutout_radii) - 1e-6
    return {
        "pad_count": 2,
        "plated_pth_count": 2,
        "pad_numbers": sorted(str(pad.get("number", "")) for pad in pads),
        "required_pad_envelope_count": 2,
        "cutout_envelopes_overlap": cutout_envelopes_overlap,
        "expected_union_opening_count": 1 if cutout_envelopes_overlap else 2,
    }


def validate_power_switch_pad_records(
    source_name: str, pads: list[dict[str, Any]]
) -> dict[str, Any]:
    if len(pads) != POWER_SWITCH_DRILL_COUNT:
        raise RuntimeError(
            f"{source_name}: {POWER_SWITCH_REFERENCE} must have exactly three pads"
        )
    if any(
        not pad.get("is_plated_through_hole") or pad.get("shape") != "circle"
        for pad in pads
    ):
        raise RuntimeError(
            f"{source_name}: {POWER_SWITCH_REFERENCE} pads must be round plated PTH"
        )
    for pad in pads:
        drill = pad.get("drill_mm", [])
        if len(drill) != 2 or any(
            abs(float(value) - POWER_SWITCH_DRILL_DIAMETER_MM) > 1e-6
            for value in drill
        ):
            raise RuntimeError(
                f"{source_name}: {POWER_SWITCH_REFERENCE} drills must be round "
                f"{POWER_SWITCH_DRILL_DIAMETER_MM:.2f} mm"
            )
    centers = [pad.get("center", []) for pad in pads]
    if any(len(center) != 2 for center in centers):
        raise RuntimeError(f"{source_name}: {POWER_SWITCH_REFERENCE} pad center is missing")
    distances = sorted(
        round(
            math.hypot(
                float(centers[right][0]) - float(centers[left][0]),
                float(centers[right][1]) - float(centers[left][1]),
            ),
            4,
        )
        for left in range(3)
        for right in range(left + 1, 3)
    )
    expected_distances = [POWER_SWITCH_PITCH_MM, POWER_SWITCH_PITCH_MM, 5.08]
    if any(
        abs(actual - expected) > 1e-4
        for actual, expected in zip(distances, expected_distances, strict=True)
    ):
        raise RuntimeError(
            f"{source_name}: {POWER_SWITCH_REFERENCE} pad distances are {distances}, "
            f"expected {expected_distances} mm"
        )
    return {
        "pad_count": 3,
        "all_round_plated_pth": True,
        "drill_count": 3,
        "drill_diameter_mm": POWER_SWITCH_DRILL_DIAMETER_MM,
        "pitch_mm": POWER_SWITCH_PITCH_MM,
        "pad_numbers": sorted(str(pad.get("number", "")) for pad in pads),
    }


def bind_battery_extraction_record(
    side: str,
    record: dict[str, Any],
    source_board: str,
    source_board_sha256: str,
) -> dict[str, Any]:
    expected_center = BATTERY_CENTERS_MM.get(side)
    if expected_center is None:
        raise RuntimeError(f"unknown X3 V2 side: {side}")
    center = record.get("center", [])
    if len(center) != 2 or any(
        abs(float(actual) - expected) > 1e-6
        for actual, expected in zip(center, expected_center, strict=True)
    ):
        raise RuntimeError(
            f"{side}: {BATTERY_REFERENCE} center is {center}, expected {expected_center}"
        )
    if not source_board or not source_board_sha256:
        raise RuntimeError(f"{side}: {BATTERY_REFERENCE} source binding is missing")
    return {
        **record,
        "side": side,
        "source_board": source_board,
        "source_board_sha256": source_board_sha256,
    }


def _normalized_service_pad(pcbnew: Any, pad: Any) -> dict[str, Any]:
    drill = pad.GetDrillSize()
    size = pad.GetSize()
    return {
        "number": pad.GetNumber(),
        "is_plated_through_hole": pad.GetAttribute() == pcbnew.PAD_ATTRIB_PTH,
        "shape": "circle" if pad.GetShape() == pcbnew.PAD_SHAPE_CIRCLE else "other",
        "drill_mm": [pcbnew.ToMM(drill.x), pcbnew.ToMM(drill.y)],
        "size_mm": [pcbnew.ToMM(size.x), pcbnew.ToMM(size.y)],
        "center": _point(pcbnew, pad.GetPosition()),
    }


def extract_board(pcbnew: Any, path: Path) -> dict[str, Any]:
    board = pcbnew.LoadBoard(str(path))
    if board is None:
        raise RuntimeError(f"Cannot load board: {path}")

    edge_segments = []
    for item in board.GetDrawings():
        if item.GetLayer() != pcbnew.Edge_Cuts or not hasattr(item, "GetStart"):
            continue
        edge_segments.append([*_point(pcbnew, item.GetStart()), *_point(pcbnew, item.GetEnd())])

    classes: dict[str, list[dict[str, Any]]] = {
        "choc_socket_body": [],
        "choc_socket_fillets": [],
        "switch_mechanical_pins": [],
        "mx_pins_pads_fillets": [],
        "diode_body_pads_fillets": [],
        "bottom_copper_tracks": [],
        "vias": [],
        "controller_socket": [],
        "reset_topside": [],
        "battery_termination": [],
        "power_switch_leads": [],
        "battery_slot": [],
    }
    switches: list[dict[str, Any]] = []
    mounting_holes: list[dict[str, Any]] = []
    routed_copper_exact: list[dict[str, Any]] = []
    bottom_mask_openings: list[dict[str, Any]] = []
    legacy_refs: list[str] = []
    reset_topside: dict[str, Any] | None = None
    battery_above_carrier: dict[str, Any] | None = None
    battery_termination_contract: dict[str, Any] | None = None
    power_switch_contract: dict[str, Any] | None = None
    power_switch_topside: dict[str, Any] | None = None
    matching_sides = [side for side, board_path in BOARD_PATHS.items() if path.resolve() == board_path.resolve()]
    if len(matching_sides) != 1:
        raise RuntimeError(f"{path.name}: cannot bind board to one X3 V2 side")
    side = matching_sides[0]
    source_board = str(path.relative_to(ROOT)).replace("\\", "/")
    source_board_sha256 = sha256_file(path)

    for drawing in board.GetDrawings():
        if drawing.GetLayer() == pcbnew.B_Mask:
            bottom_mask_openings.append(
                {
                    "kind": "box",
                    "bounds": _box(pcbnew, drawing),
                    "source": "board_graphic",
                }
            )

    for footprint in board.GetFootprints():
        ref = footprint.GetReference()
        if (ref.startswith("REG") and ref[3:].isdigit()) or (
            ref.startswith("H") and ref[1:].isdigit()
        ):
            legacy_refs.append(ref)

        pads = list(footprint.Pads())
        graphics = list(footprint.GraphicalItems())
        for pad in pads:
            if pad.IsOnLayer(pcbnew.B_Mask):
                bottom_mask_openings.append(
                    {
                        "kind": "box",
                        "bounds": _shape_box(
                            pcbnew,
                            pad.GetEffectiveShape(pcbnew.B_Mask),
                        ),
                        "source": f"{ref}.{pad.GetNumber()}",
                    }
                )
        for graphic in graphics:
            if graphic.GetLayer() == pcbnew.B_Mask:
                bottom_mask_openings.append(
                    {
                        "kind": "box",
                        "bounds": _box(pcbnew, graphic),
                        "source": ref,
                    }
                )
        if ref.startswith("MH") and ref[2:].isdigit():
            pad_records = []
            for pad in pads:
                drill = pad.GetDrillSize()
                size = pad.GetSize()
                drill_x = pcbnew.ToMM(drill.x)
                drill_y = pcbnew.ToMM(drill.y)
                size_x = pcbnew.ToMM(size.x)
                size_y = pcbnew.ToMM(size.y)
                pad_records.append(
                    {
                        "attribute": int(pad.GetAttribute()),
                        "is_npth": pad.GetAttribute() == pcbnew.PAD_ATTRIB_NPTH,
                        "drill_mm": [drill_x, drill_y],
                        "size_mm": [size_x, size_y],
                        "copper_annulus_mm": round(
                            max(size_x - drill_x, size_y - drill_y) / 2.0,
                            6,
                        ),
                        "net": pad.GetNetname(),
                    }
                )
            mounting_holes.append(
                {
                    "ref": ref,
                    "center": _point(pcbnew, footprint.GetPosition()),
                    "pad_count": len(pad_records),
                    "pads": pad_records,
                }
            )
            continue

        if ref.startswith("SW") and ref[2:].isdigit():
            center = _point(pcbnew, footprint.GetPosition())
            switches.append(
                {
                    "ref": ref,
                    "center": center,
                    "angle_deg": float(footprint.GetOrientationDegrees()),
                }
            )
            body_boxes = [
                _box(pcbnew, item)
                for item in graphics
                if item.GetLayer() in (pcbnew.B_Fab, pcbnew.B_SilkS)
            ]
            if body_boxes:
                classes["choc_socket_body"].append(
                    {
                        "kind": "box",
                        "bounds": [
                            min(bounds[0] for bounds in body_boxes),
                            min(bounds[1] for bounds in body_boxes),
                            max(bounds[2] for bounds in body_boxes),
                            max(bounds[3] for bounds in body_boxes),
                        ],
                        "ref": ref,
                    }
                )
            for pad in pads:
                if pad.GetAttribute() == pcbnew.PAD_ATTRIB_NPTH:
                    classes["switch_mechanical_pins"].append(
                        {
                            "kind": "box",
                            "bounds": _box(pcbnew, pad),
                            "ref": ref,
                        }
                    )
                if pad.GetAttribute() == pcbnew.PAD_ATTRIB_SMD and pad.IsOnLayer(pcbnew.B_Cu):
                    classes["choc_socket_fillets"].append(
                        {
                            "kind": "box",
                            "bounds": _box(pcbnew, pad),
                            "allowance_mm": FILLET_ALLOWANCE_MM,
                            "ref": ref,
                        }
                    )
                if pad.GetAttribute() == pcbnew.PAD_ATTRIB_PTH:
                    classes["mx_pins_pads_fillets"].append(
                        {
                            **({
                                "kind": "oriented_oval",
                                "center": _point(pcbnew, pad.GetPosition()),
                                "size_x_mm": pcbnew.ToMM(pad.GetSize().x),
                                "size_y_mm": pcbnew.ToMM(pad.GetSize().y),
                                "angle_deg": float(pad.GetOrientationDegrees()),
                            } if pad.GetShape() == pcbnew.PAD_SHAPE_OVAL else {
                                "kind": "box", "bounds": _box(pcbnew, pad),
                            }),
                            "allowance_mm": FILLET_ALLOWANCE_MM,
                            "ref": ref,
                        }
                    )
            continue

        if ref.startswith("D") and ref[1:].isdigit():
            # The housing keepout follows the official Diodes Incorporated
            # maximum body envelope rather than nominal Fab/Silk graphics. The
            # KC2 enlarged hand-solder pads below carry their own fillet allowance.
            classes["diode_body_pads_fillets"].append(
                {
                    "kind": "oriented_box",
                    "center": _point(pcbnew, footprint.GetPosition()),
                    "size_x_mm": DIODE_OFFICIAL_PLAN_ENVELOPE_MAX_MM[0],
                    "size_y_mm": DIODE_OFFICIAL_PLAN_ENVELOPE_MAX_MM[1],
                    "angle_deg": float(footprint.GetOrientationDegrees()),
                    "ref": ref,
                }
            )
            for pad in pads:
                classes["diode_body_pads_fillets"].append(
                    {
                        "kind": "box",
                        "bounds": _box(pcbnew, pad),
                        "allowance_mm": FILLET_ALLOWANCE_MM,
                        "ref": ref,
                    }
                )
            continue

        if ref == "BAT_LEAD_SLOT1":
            for pad in pads:
                drill = pad.GetDrillSize()
                size_x = pcbnew.ToMM(drill.x) or pcbnew.ToMM(pad.GetSize().x)
                size_y = pcbnew.ToMM(drill.y) or pcbnew.ToMM(pad.GetSize().y)
                angle = float(pad.GetOrientation().AsDegrees())
                classes["battery_slot"].append(
                    {
                        "kind": "capsule",
                        "center": _point(pcbnew, pad.GetPosition()),
                        "size_x_mm": size_x,
                        "size_y_mm": size_y,
                        "angle_deg": angle,
                        "allowance_mm": BATTERY_ACCESS_CLEARANCE_MM,
                        "ref": ref,
                    }
                )
            continue
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

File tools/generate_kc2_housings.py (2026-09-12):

from __future__ import annotations

import argparse
import json
import math
import subprocess
import sys
from dataclasses import dataclass
from pathlib import Path
from typing import Any


ROOT = Path(__file__).resolve().parents[1]
DEFAULT_OUTPUT_DIR = ROOT / "hardware" / "case"
BOARD_PATHS = {
    "left": ROOT / "hardware" / "kicad" / "kc2_left" / "kc2_left.kicad_pcb",
    "right": ROOT / "hardware" / "kicad" / "kc2_right" / "kc2_right.kicad_pcb",
}
HOTSWAP_SOCKET_FOOTPRINT = "SW_Kailh_Choc_V1_HotSwap_THT"


@dataclass(frozen=True)
class HousingParams:
    design_style: str = "hollow_rail_capture_tray"
    # The housing stays slightly inside the PCB outline so the joined inner
    # edges cannot be blocked by printed plastic swelling.
    outline_inset_mm: float = 0.10
    rail_inset_mm: float = 0.30
    rail_width_mm: float = 2.00
    outer_wall_width_mm: float = 2.40
    floor_thickness_mm: float = 1.20
    socket_body_height_mm: float = 2.20
    socket_safety_clearance_mm: float = 0.40
    # Add 0.01 mm so tessellated/offset geometry still verifies at >= 0.30 mm.
    socket_lateral_clearance_mm: float = 0.31
    pcb_thickness_mm: float = 1.60
    support_post_diameter_mm: float = 4.80
    registration_peg_diameter_mm: float = 2.55
    screw_pilot_hole_diameter_mm: float = 1.60
    peg_top_below_pcb_top_mm: float = 0.30
    battery_slot_clearance_mm: float = 0.70
    battery_floor_cutout_enabled: bool = False
    bottom_corner_radius_mm: float = 0.80
    bottom_edge_radius_mm: float = 0.00
    rear_height_ratio: float = 1.00
    print_volume_limit_mm: float = 150.0
    right_split_center_x_mm: float = 112.0
    right_split_zigzag_amplitude_mm: float = 5.0
    right_split_zigzag_pitch_mm: float = 8.0
    right_split_face_setback_mm: float = 0.20
    cylinder_segments: int = 32

    @property
    def bottom_component_clearance_mm(self) -> float:
        return self.socket_body_height_mm + self.socket_safety_clearance_mm

    @property
    def pcb_bottom_z(self) -> float:
        return self.floor_thickness_mm + self.bottom_component_clearance_mm

    @property
    def front_height_mm(self) -> float:
        return self.pcb_bottom_z

    @property
    def rear_height_mm(self) -> float:
        return self.front_height_mm * self.rear_height_ratio

    @property
    def rear_rise_mm(self) -> float:
        return self.rear_height_mm - self.front_height_mm

    @property
    def peg_top_z(self) -> float:
        return self.pcb_bottom_z + self.pcb_thickness_mm - self.peg_top_below_pcb_top_mm


Point3 = tuple[float, float, float]
Point = tuple[float, float]
Facet = tuple[Point3, Point3, Point3]
TRIANGLE_AREA_TOLERANCE_MM2 = 1e-8
TRIANGLE_OUTSIDE_AREA_TOLERANCE_MM2 = 1e-7


def locate_kicad_python() -> Path:
    candidates = [
        Path(r"C:\Program Files\KiCad\10.0\bin\python.exe"),
        Path(r"C:\Program Files\KiCad\9.0\bin\python.exe"),
    ]
    for candidate in candidates:
        if candidate.exists():
            return candidate
    raise SystemExit("KiCad Python was not found. Install KiCad 10 or pass --kicad-python.")


def mm_vec(pcbnew: Any, vec: Any) -> Point:
    return pcbnew.ToMM(vec.x), pcbnew.ToMM(vec.y)


def extract_geometry() -> None:
    import pcbnew  # type: ignore[import-not-found]

    out: dict[str, Any] = {"boards": {}}
    for side, board_path in BOARD_PATHS.items():
        board = pcbnew.LoadBoard(str(board_path))
        if board is None:
            raise RuntimeError(f"Cannot load board: {board_path}")

        edge_segments = []
        registration_holes = []
        socket_keepouts = []
        battery_slot = None
        for item in board.GetDrawings():
            if not hasattr(item, "GetLayer") or item.GetLayer() != pcbnew.Edge_Cuts:
                continue
            if not hasattr(item, "GetStart") or not hasattr(item, "GetEnd"):
                continue
            sx, sy = mm_vec(pcbnew, item.GetStart())
            ex, ey = mm_vec(pcbnew, item.GetEnd())
            edge_segments.append([sx, sy, ex, ey])

        for fp in board.GetFootprints():
            ref = fp.GetReference()
            value = fp.GetValue()
            x, y = mm_vec(pcbnew, fp.GetPosition())
            if value == "REG_NPTH_3.0":
                drill = 3.0
                pads = list(fp.Pads())
                if pads:
                    drill = pcbnew.ToMM(pads[0].GetDrillSize().x)
                registration_holes.append({"ref": ref, "x": x, "y": y, "drill_mm": drill})
            elif ref == "BAT_LEAD_SLOT1":
                pads = list(fp.Pads())
                size_x = 3.6
                size_y = 2.2
                angle_deg = 0.0
                if pads:
                    pad = pads[0]
                    size = pad.GetSize()
                    size_x = pcbnew.ToMM(size.x)
                    size_y = pcbnew.ToMM(size.y)
                    try:
                        angle_deg = float(pad.GetOrientation().AsDegrees())
                    except AttributeError:
                        angle_deg = 0.0
                battery_slot = {
                    "ref": ref,
                    "x": x,
                    "y": y,
                    "size_x_mm": size_x,
                    "size_y_mm": size_y,
                    "angle_deg": angle_deg,
                }
            if str(fp.GetFPID().GetLibItemName()) == HOTSWAP_SOCKET_FOOTPRINT:
                bounds = []
                for item in fp.GraphicalItems():
                    if item.GetLayer() == pcbnew.B_SilkS:
                        bounds.append(item.GetBoundingBox())
                for pad in fp.Pads():
                    if (
                        pad.GetAttribute() == pcbnew.PAD_ATTRIB_SMD
                        and pad.IsOnLayer(pcbnew.B_Cu)
                    ):
                        bounds.append(pad.GetBoundingBox())
                if not bounds:
                    raise RuntimeError(f"{side} {ref}: no bottom socket envelope geometry")
                min_x = min(pcbnew.ToMM(box.GetX()) for box in bounds)
                min_y = min(pcbnew.ToMM(box.GetY()) for box in bounds)
                max_x = max(pcbnew.ToMM(box.GetX() + box.GetWidth()) for box in bounds)
                max_y = max(pcbnew.ToMM(box.GetY() + box.GetHeight()) for box in bounds)
                socket_keepouts.append(
                    {
                        "ref": ref,
                        "min_x": min_x,
                        "min_y": min_y,
                        "max_x": max_x,
                        "max_y": max_y,
                    }
                )

        out["boards"][side] = {
            "path": str(board_path.relative_to(ROOT)),
            "edge_segments": edge_segments,
            "registration_holes": sorted(registration_holes, key=lambda h: h["ref"]),
            "socket_keepouts": sorted(socket_keepouts, key=lambda item: item["ref"]),
            "battery_slot": battery_slot,
        }
    print(json.dumps(out, ensure_ascii=False))
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

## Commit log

2026-06-03 Finalize KC2 routed PCB draft
    [kc2_left.dsn, kc2_left.kicad_pcb, kc2_right.dsn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]
2026-06-03 Add KC2 hotswap PCB variant
    [kc2_left-hotswap.dsn, kc2_left-hotswap.kicad_pcb, kc2_right-hotswap.dsn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]
2026-06-03 Add KC2 x1 hand-solder diode variant
    [kc2_left-x1.dsn, kc2_left-x1.kicad_pcb, kc2_right-x1.dsn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]
2026-06-03 Add KC2 x2 socket and solder variant
    [kc2_left-x2.dsn, kc2_left-x2.kicad_pcb, kc2_right-x2.dsn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]
2026-06-04 feat: KC2 X3 무보강판 변형과 SpecKiwi SRS 워크플로 도입
    - generate_kc2_pcbs.py x3 변형: x2 전기 스택 + no-stabilizer 77키 layout, KiCad 8/9/10 share 자동 탐색, 임베디드 footprint fallback
    - verify_kc2_connectivity.py: 레이어 인식 넷/diode/row-col/컨트롤러 핀 매핑 검증 (좌우 X3 PASS)
    - kc2_left/right-x3 보드, autoroute dsn/ses, x3 manifest 생성
    - docs/spec.md·research 문서에 X3 결과 반영, kc2_right-x2.kicad_pro KiCad 재저장 동기화
    - SpecKiwi SRS 도입: CLAUDE.md/AGENTS.md 작업 규약, docs/rule 작성 규칙, docs/spec/ 스캐폴딩과 20.no-stabilizer-layout SSOT
    [kc2_left-x3.dsn, kc2_left-x3.kicad_pcb, kc2_right-x3.dsn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]
2026-06-04 fix: KC2 X3 발주 차단 해소
    - nice!nano 좌/우 전용 풋프린트 추가 및 controller/switch/power 추적성 정리
    - switch pad island routing, edge clearance, DRC error/warning 해소
    - 좌/우 PCB, DSN/SES, Gerber/Excellon/fabrication zip/render/DRC JSON 갱신
    [kc2_left-x3-B_Cu.gbl, kc2_left-x3-B_Mask.gbs, kc2_left-x3-B_Paste.gbp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]
2026-06-05 fix: KC2 X3 결합부 clearance 복구
    - Y/H 돌출부 세로면을 3.6 mm inner margin으로 복구하고 가로 ledge relief만 유지
    - 6-Y X축 clearance 표시와 geometry verifier를 추가
    - DRC, Gerber/Drill, SpecKiwi evidence를 갱신
    [kc2_left-x3-B_Cu.gbl, kc2_left-x3-B_Mask.gbs, kc2_left-x3-B_Paste.gbp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]
2026-06-05 chore: OPS-ARCH-002 KC2 X3 KiCad 산출물을 main 경로로 승격한다
    - X3 좌우 프로젝트를 hardware/kicad/kc2_left, hardware/kicad/kc2_right로 승격
    - soldered, hotswap, x1, x2 변형은 hardware/kicad/draft 아래에 보존
    - manifest, autoroute, file naming, fabrication ZIP, renders, verify scripts를 main 경로 기준으로 갱신
    - SRS evidence와 OPS-ARCH-002 verified 상태를 반영
    [kc2_left-B_Cu.gbl, kc2_left-B_Mask.gbs, kc2_left-B_Paste.gbp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]
2026-06-05 fix: KC2 X3 탭 축소로 nice!nano 안테나 keepout 충돌 해소
    배터리 carrier 패드와 불필요한 전원 넷을 제거해 컨트롤러 탭을 축소
    reset 스위치 위치와 후처리 라우팅을 조정해 nice!nano 안테나 keepout 및 M2 홀 간섭을 해소
    검증기, DRC, 렌더, Gerber, JLCPCB ZIP, docs/spec 증거를 갱신
    [kc2_left-B_Cu.gbl, kc2_left-B_Mask.gbs, kc2_left-B_Paste.gbp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]
2026-06-06 fix: KC2 X3 H4/H5 마운팅 홀 배치 조정
    H4를 한 줄 위로 옮기고 H2 인접 상단 코너에 H5를 추가해 하부 바닥판 고정 지점 분포를 개선
    왼쪽은 상단 외곽 제약 때문에 H2.x보다 안쪽인 x=173.45에 H5를 배치
    관련 산출물과 검증 증거를 동일 보드 상태로 재생성
    [kc2_left-B_Cu.gbl, kc2_left-B_Mask.gbs, kc2_left-B_Paste.gbp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]
2026-06-08 feat: KC2 X3 스크류리스 주문 패키지를 주문 가능 상태로 갱신한다
    스크류리스 레일 하우징용 주문 가능 상태를 확정하기 위해 M2 고정홀을 제거하고 REG_NPTH 등록홀, H1-H9 라벨, 배터리 리드 슬롯, antenna-side reset 위치, KC2 v1.0 L/R 실크를 반영한다.
    DRC, 연결성, 실크 간섭, 키캡 간격, Gerber/drill/render/JLCPCB ZIP 검증기를 보강하고 주문 산출물을 재생성한다.
    SpecKiwi 요구사항 증거와 Freerouting 프로세스 안전 규칙을 함께 갱신한다.
    [kc2_left-B_Cu.gbl, kc2_left-B_Mask.gbs, kc2_left-B_Paste.gbp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]
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2026-06-15 CON-ARCH-003 하우징 산출물 추가
    [kc2_left_lower_housing - 복사본.stl, kc2_left_lower_housing.stl, kc2_right_lower_housing - 복사본.stl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]
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2026-07-19 Clean KC2 housing underside mesh
    Requirement: CON-ARCH-003
    Disable the lower-edge roundover loft, tighten STL mesh verification, and regenerate the left/right lower housing STL outputs.
    [kc2_left_lower_housing.stl, kc2_right_lower_housing.stl]
2026-07-19 Mirror KC2 housing STL orientation
    X-reflect both lower-housing STL artifacts so the assembled left/right cut faces match the physical keyboard orientation. Keep generator and KiCad sources unchanged per STL-only request.
    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
    [kc2_left_lower_housing.stl, kc2_right_lower_housing.stl]
2026-07-24 feat: flatten KC2 X3 lower housings
    [kc2_left_lower_housing.f3d, kc2_left_lower_housing.step, kc2_left_lower_housing.stl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]
2026-08-03 feat(hardware): add KC2 X3 V2 routed draft
    [kc2_left-x3-v2-B_Cu.gbl, kc2_left-x3-v2-B_Mask.gbs, kc2_left-x3-v2-B_Paste.gbp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]
2026-08-19 feat(hardware): implement recessed 71-key X3 V2 PCB
    [kc2_left-x3-v2-71-r13.dsn, kc2_left-x3-v2-71-r8.pre-route.kicad_pcb, kc2_left-x3-v2-71-r8.raw.dsn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]
2026-08-20 feat(hardware): complete KC2 X3 V2 digital draft
    [kc2_left-x3-v2-B_Cu.gbl, kc2_left-x3-v2-B_Mask.gbs, kc2_left-x3-v2-B_Paste.gbp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]
2026-08-20 feat: redesign X3 V2 2.5mm lower housing
    [kc2_left_x3_v2_lower_housing.step, kc2_left_x3_v2_lower_housing.stl, kc2_right_x3_v2_lower_housing_part_a.stl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]
2026-08-21 fix: add X3 V2 diode edge clearance
    [kc2_left-x3-v2-71-r14.dsn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]
2026-08-21 feat(x3-v2): widen joined seam safely
    [kc2_left-x3-v2-B_Cu.gbl, kc2_left-x3-v2-B_Mask.gbs, kc2_left-x3-v2-B_Paste.gbp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]
2026-08-22 feat(x3-v2): revise left layout to 70-key v5
    [kc2_left-x3-v2-70-v5-r1.dsn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]
2026-08-24 feat(x3-v2): finalize ES1B mounting prototype
    [kc2_left-x3-v2-70-es1b-mh-r2.dsn, kc2_left-x3-v2-70-es1b-r1.dsn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]
2026-08-26 feat(x3-v2): compact controller tab and label mounts
    [kc2_left-x3-v2-70-es1b-controller-r3.dsn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]
2026-08-26 feat(x3-v2): USB 하부 리셋 배치와 실크 충돌 수정
    소켓으로 높아진 nice!nano 아래 공간을 활용하도록 좌우 리셋 배치와 RST/GND 라우팅을 재구성한다. 우측 Reference 필드를 안전한 위치로 옮겨 DRC 경고를 제거하고 SRS, 해시 증거, 생성·검증 코드를 갱신한다.
    Requirements: CON-ARCH-004, CON-ARCH-006, OPS-ARCH-003
    [kc2_left-x3-v2.kicad_pcb, kc2_right-x3-v2.kicad_pcb]
2026-08-28 feat(x3-v2): add switched battery service layout
    - Add direct-solder battery power and mirrored power/reset controls.
    - Integrate controller-service openings and lower-housing support.
    - Regenerate routing, DRC, fabrication, mechanical, render, and model evidence.
    - Document protected KiCad mutations and keep physical gates order-blocked.
    Refs: CON-ARCH-004
    Refs: CON-ARCH-006
    Refs: CON-ARCH-007
    Refs: REL-ARCH-001
    Refs: OPS-ARCH-003
    Refs: OPS-ARCH-004
    Refs: OPS-ARCH-005
    [kc2_left-x3-v2-B_Cu.gbl, kc2_left-x3-v2-B_Mask.gbs, kc2_left-x3-v2-B_Paste.gbp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]
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2026-08-29 wip(x3-v2): redesign mounts and per-key supports
    [kc2_left-x3-v2.kicad_pcb, kc2_right-x3-v2.kicad_pcb]
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2026-08-30 feat(x3-v2): reinforce mounting holes
    [kc2_left-x3-v2-70-es1b-controller-r3.dsn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]
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2026-09-01 feat(x3-v2): add fail-closed hand-assembly quote package
    [kc2_left-x3-v2-B_Cu.gbl, kc2_left-x3-v2-B_Mask.gbs, kc2_left-x3-v2-B_Paste.gbp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]
2026-09-03 feat(x3-v2): promote active hardware to canonical paths
    Align PCB, housing, fabrication artifacts, firmware metadata, tooling, and SRS evidence with OPS-ARCH-006.
    Keep fabrication blocked until physical evidence is complete.
    [kc2_left-B_Cu.gbl, kc2_left-B_Mask.gbs, kc2_left-B_Paste.gbp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]
2026-09-06 feat(kc2): add solid-floor housing and publish reviewed order guide
    CON-ARCH-004/006, OPS-ARCH-007: retain enlarged solder lands and reviewed PCB release; add continuous floors, silicone-foot layouts, CAD/native regression evidence, exact order.md paths, and raw-byte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
    [kc2_left-B_Cu.gbl, kc2_left-B_Mask.gbs, kc2_left-B_Paste.gbp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]
2026-09-07 feat(hardware): preserve r5 housings and add verified magnetic variants
    CON-ARCH-006, OPS-ARCH-006: keep canonical hardware paths and both lower-housing options; add two oversized magnet pockets per half without thicker walls, native CAD and source-bound evidence. Includ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
    [kc2_left.kicad_pcb, kc2_left_lower_housing - 복사본.stl, kc2_left_lower_housing.f3d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]
2026-09-09 feat(hardware): enclose MX upper and lower housings
    CON-ARCH-006, CON-ARCH-007, OPS-ARCH-006: continuous seated walls, retained normal/magnetic lower options, service access and current print guides. Preserve ordered PCB/Gerber bytes; physical qualification remains pending.
    Evidence: 72 regression tests pass; actual STEP/mesh independent audits pass; six Fusion native round trips pass; 21 CAD outputs and 92 bindings pass canonical and isolated Git-archive verification. Independent publication review closed prewrite and inventory blockers.
    [kc2_left_lower_housing.f3d, kc2_left_lower_housing.stl, kc2_left_lower_housing_magnetic.f3d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]
2026-09-09 fix(hardware): preserve PCB-on-base stack and add local socket covers
    [kc2_left_lower_housing.f3d, kc2_left_lower_housing.stl, kc2_left_lower_housing_magnetic.f3d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]
2026-09-12 Checkpoint reinforced housings before solid-filled plate publication
    [kc2_left_lower_housing.f3d, kc2_left_lower_housing.stl, kc2_left_lower_housing_magnetic.f3d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]
2026-09-12 Publish verified solid-filled MX Choc V1 and Deep Sea plates
    [kc2_left_choc_v1_upper_housing.f3d, kc2_left_choc_v1_upper_housing.stl, kc2_left_deep_sea_upper_housing.f3d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]
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2026-09-14 Complete registered housing fit and verified CAD publication
    CON-ARCH-006 CON-ARCH-007 OPS-ARCH-006: raised perimeter walls and upper rebates; central nonlatching fit and right A/B relief. Publish 35 CAD files with 356 passing tests, native and independent por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
    [kc2_left_choc_v1_upper_housing.f3d, kc2_left_choc_v1_upper_housing.stl, kc2_left_deep_sea_upper_housing.f3d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]
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2026-09-14 Fill former central guide cavities for smooth housing walls
    [kc2_left_lower_housing.f3d, kc2_left_lower_housing.stl, kc2_left_lower_housing_magnetic.f3d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]
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2026-09-20 Raise continuous PCB sleeve and publish verified housing set (CON-ARCH-006)
    [kc2_left_choc_v1_upper_housing.f3d, kc2_left_choc_v1_upper_housing.stl, kc2_left_deep_sea_upper_housing.f3d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]
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
